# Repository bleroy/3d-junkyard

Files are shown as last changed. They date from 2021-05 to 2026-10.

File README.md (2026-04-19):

# 3d-junkyard

A repository of various 3D models and projects.

So far:

* [DecentXE](./DecentXE): a mechanical keyboard for Atari XE computers
* [DecentXL](./DecentXL/): a mechanical keyboard for Atari 600XL and 800XL computers
* [Decent400](./Decent400/): a mechanical keyboard for Atari 400 computers
* [Decent800](./Decent800/): a mechanical keyboard for Atari 800 computers
* [Decent1200](./Decent1200/): a mechanical keyboard for Atari 1200XL computers 
* [Dungeon Master](./DungeonMaster): reverse-engineering Dungeon Master's rendering and running it in a browser
* [Beyond the Jaggi lines](./Jaggilines): reverse-engineering Rescue on Fractalus and running it in a browser
* [JoyKeyMX](./JoyKeyMX): a joypad compatible with Atari 8-bit and 7800 built with Cherry MX compatible switches

## License

All hardware in this repository is licensed under [CERN Open Hardware License v2](https://ohwr.org/cern_ohl_p_v2.pdf).
All software in this repository is licensed under the [MIT license](https://mit-license.org/).
All documentation in this repository is licensed under [Creative Commons Creative Commons Attribution-ShareAlike 4.0 International Public License](https://creativecommons.org/licenses/by-sa/4.0/legalcode).

Full terms can be found in the [LICENSE](./LICENSE) file or on the web sites linked above.

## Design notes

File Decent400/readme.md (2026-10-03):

# Decent 400 mechanical keyboard replacement for Atari 400 computers

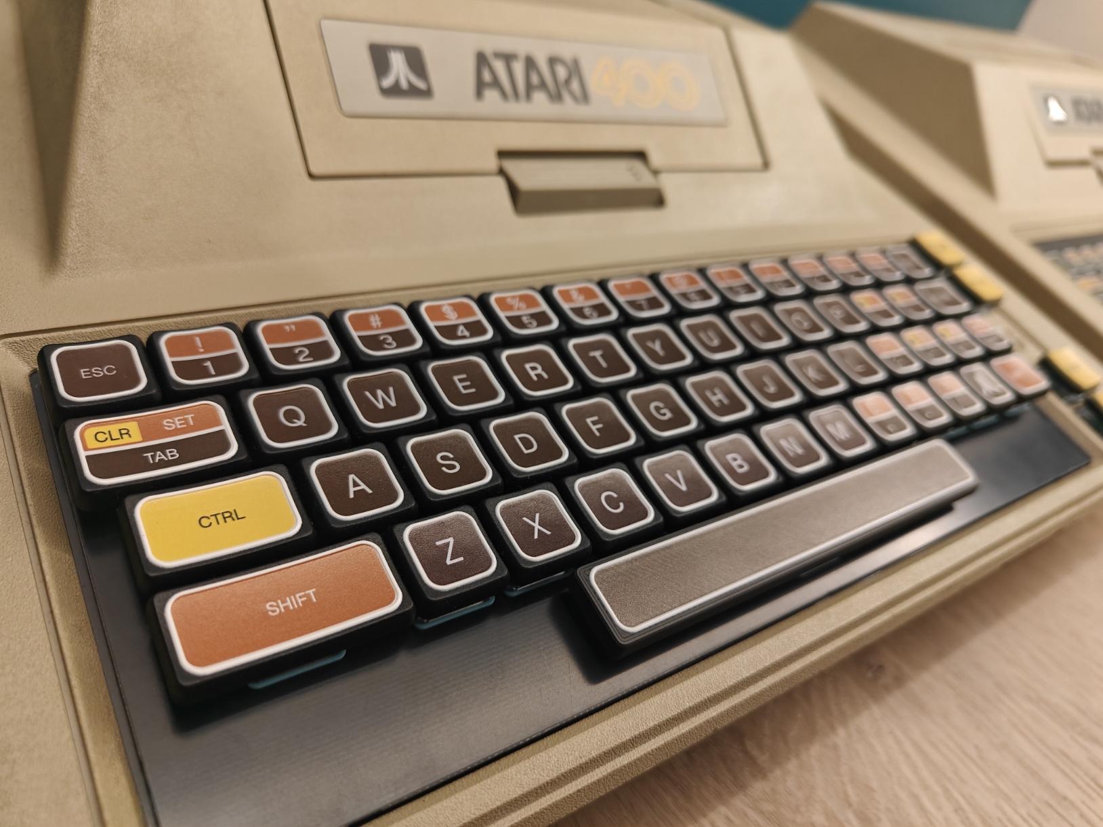
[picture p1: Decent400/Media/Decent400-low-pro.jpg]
The Decent 400 keyboard


If you always wished the Atari 400 had a real keyboard, this is the project for you.

There's been a number of aftermarket keyboards for the Atari 400, but they all faced a big issue: the original membrane "keyboard"'s "keys" are much smaller than standard key caps. There just isn't enough space in the case for a sane layout with full-sized keys. It took a lot of attempts before coming up with the realization that there was an untapped degree of freedom in the design: the spacing of the keys. This is even more true of low-profile key caps, and given how infinitely taller MX switches and caps are compared to the original membrane thing, it made sense to try to build the Decent400 as a low-profile mechanical keyboard. I was finally able in late 2025 to fit the original layout of the computer in its very small space, with modern switches.

There was one final obstacle though, which is that as I'm writing this readme, no company in the world will print custom low-profile key caps. My only option was to somehow find a way to do it myself. When I heard about the [Eufymake](https://www.eufymake.com/) kickstarter for a UV printer capable of transferring a full-color design onto any material, it was clear it could be the last piece to the puzzle. It was a big investment, but I bet on it and waited and waited and waited. Finally, the printer arrived and check this out:

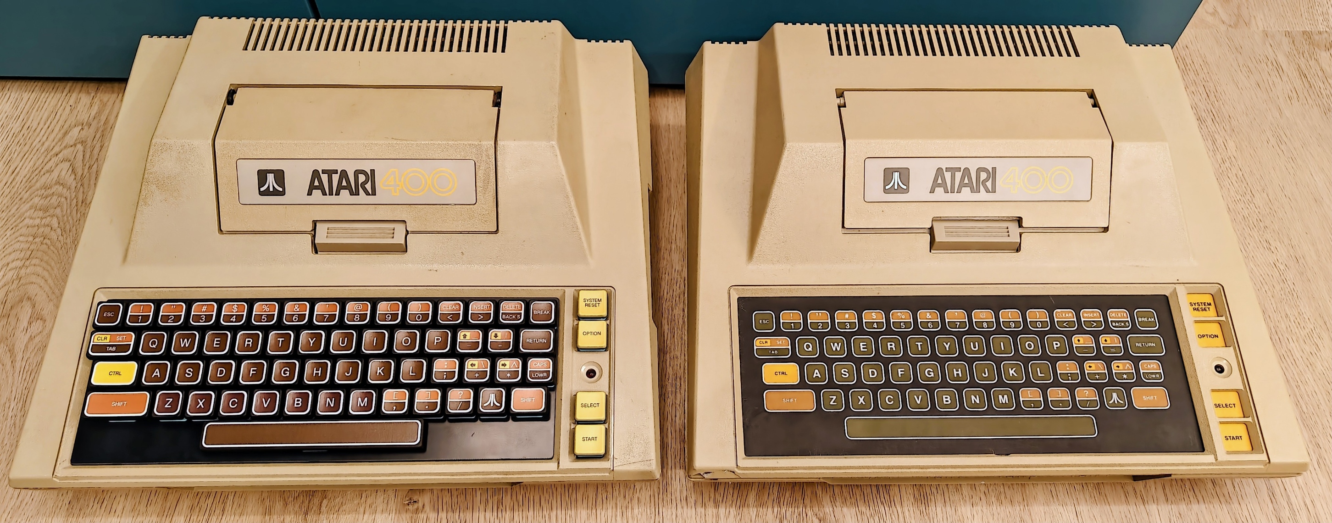
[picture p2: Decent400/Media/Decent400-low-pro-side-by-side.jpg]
Side-by-side comparison with the vintage membrane


It even has the raised white outline on each key, a very satisfying detail...

The keyboard can be built with your choice of Kailh Choc v1 switches. I prefer the clicky Robins myself, but perfectly good tactile and linear options do exist if that's your preference.

If you're looking to modify an XE computer, head over to [the DecentXE project](../Atari130MX/). For 600XL and 800XL keyboards, go to [the DecentXL project](../DecentXL/). For the 1200XL keyboard, go to [the Decent1200 project](../Decent1200/). For the 800, go to [the Decent800 project](../Decent800/).

## Current version

The current revision of the Decent 400 keyboard is: rev. 5.

## Can I buy one?

The project is open-source, and I encourage everyone to build their own (access to a UV printer can be an obstacle, but you can buy the printed key caps from me). I also sell kits and assembled keyboards for those who are not comfortable with ordering parts, PCBs or using a soldering iron.

How expensive is it? It depends on what you're ordering, but this is a made-to-order custom mechanical keyboard, so not cheap.

## Project history

This is a brand new design that uses a lot of lessons learned from building the [DecentXE](https://github.com/bleroy/3d-junkyard/tree/main/Atari130MX) and the [award-winning DecentXL](https://github.com/bleroy/3d-junkyard/tree/main/DecentXL), but adapts to the specificities of the 400.

## Options

### Switches

Switches are largely a matter of taste. The Decent 400 PCB can be mounted with any Kailh Choc v1 switch.

With any type of switch, there is a wide array of choices. If you're new to the world of mechanical keyboards, there are 3 main families of switch experiences:

* Linear (often red): the switch reacts with mostly constant resistance throughout the course of the key press until it hits the bottom.
* Tactile (often brown): there is a higher resistance at a specific point of the key's course, providing tactile feedback to pressing the key.
* Clicky (often white): an even more pronounced and localized resistance is accompanied with an audible and satisfying click.

My personal preference goes to Choc Robin switches, which are very pleasant clicky switches.

## Design

Decent 400 schematic

The Decent 400 project is constituted of the following parts (this is not a BOM but a list of custom parts created for this project; see below for the actual BOM):

* A PCB with adjustable blue backlighting.
* An aluminum or FR4 plate to hold the switches firmly aligned and rigidify the assembly.
* A custom set of Choc v1-compatible modern key caps.
* A connector adapter board
* Cables

## Bill of materials

This project is meant to be reproduced. You'll need a few things that are more or less easy to source, so I've made sure to give multiple roads to success and alternatives for most parts.

It's also an approach that can be easily adapted to other vintage computer keyboards, Atari or not.

### Atari 400 computer

The project is designed around the conservation of the vintage look of the Atari 400 computer and the integration of the keyboard in its original case. As such, you'll need a host 400 computer to receive the end product.

### Key caps

The key caps are the hardest part to source because at the time of writing, nobody's printing custom low-profile caps.

As UV printers are becoming relatively affordable, it has become possible to print blank caps at home.

You'll need a set of blank caps that can be printed in a UV printer.
I'm providing a set of templates and printing support to make it easier to get consistent results.

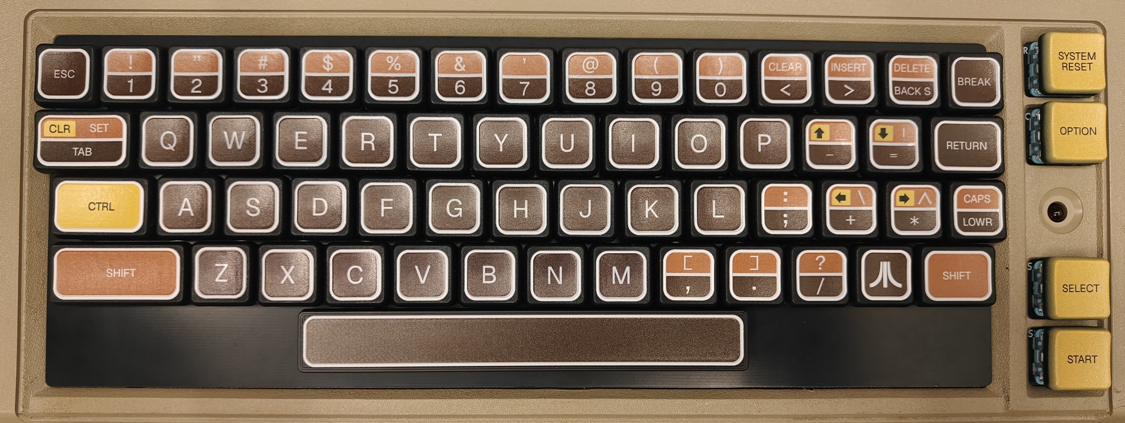
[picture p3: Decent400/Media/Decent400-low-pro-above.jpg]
Bird-eye view of the Decent400


The space bar key cap is almost impossible to source and must be [printed with black filament](./Caps/SpaceBar-Choc-v1-6U25.3mf).

### Switches

You'll need 63 Choc v1 switches.

### Stabilizers and adapters

The Decent 400 keyboard uses one 2U stabilizers for the left shift key, and one 6.25U stabilizer for the space bar.
Make sure you order the correct low-profile stabilizers.

### PCB

Use [the Gerber](./Keyboard/production/Decent400_keyboard_5.zip), [BOM](./Keyboard/production/bom.csv) and [position](./Keyboard/production/positions.csv) files to order a PCB with all the SMD parts assembled.

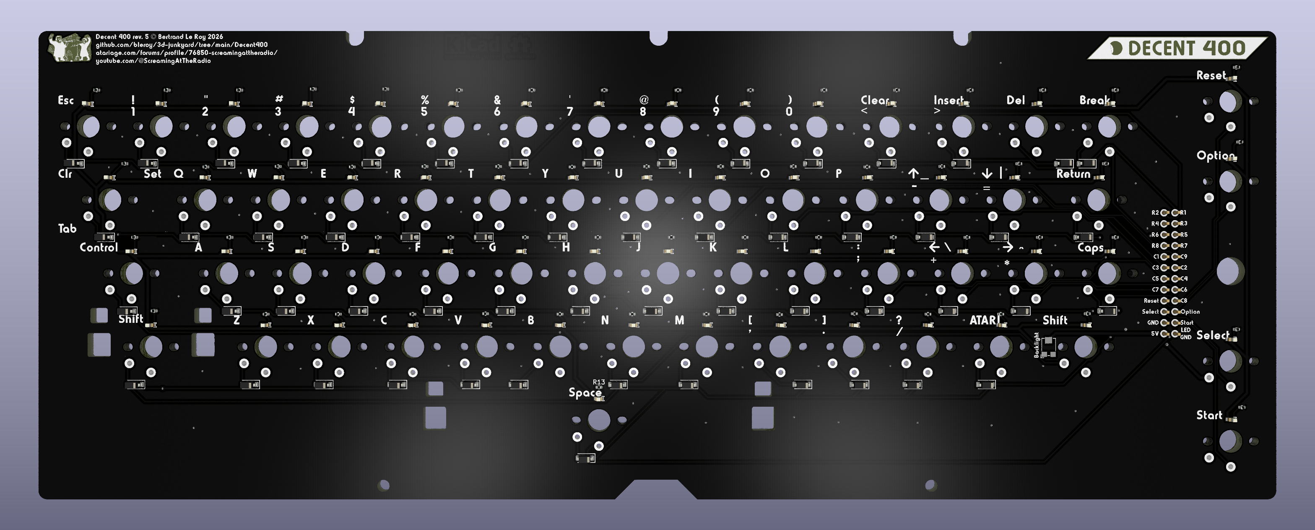
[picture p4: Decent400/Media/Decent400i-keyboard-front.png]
The Decent400 PCB


The main PCB needs a 2x12 pin male IDC connector.

### Plate

The plate is just a PCB, which can be done in aluminum or FR4. Download [the Gerber](./Plate/production/Decent400_Plate_4.2i.zip) and have it produced in 1.2mm. It is important to check the thickness is 1.2mm and not the default 1.6mm, so that the Choc switches can properly grip it. I recommend having this done in black.

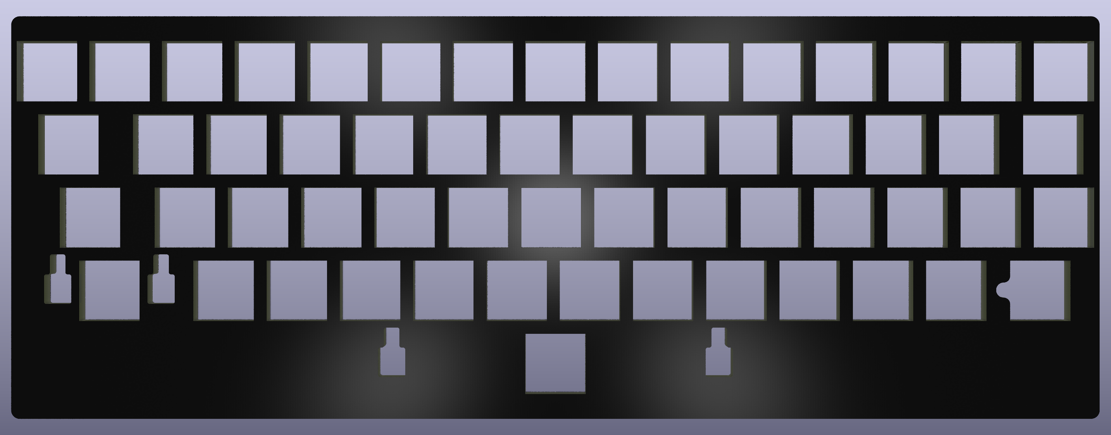
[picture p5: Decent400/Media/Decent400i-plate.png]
Decent 400 aluminum plate


### Connectors

The keyboard connects to the motherboard through a small interface board. A pin header goes into the motherboard connector, and an IDC connector goes to the keyboard. There's also a pair of headers that can be connected to 5V and ground on the 400's power board to provide backlighting.

The connector board needs another 2x12 pin male IDC connector a 22 precision male pin header a a 2 pin angled male header.

You'll need a 24 wire 1.27mm pitch flat cable. 10cm or 15cm is fine since the connector board will be very close to the keyboardś connector.

You'll also need a 22 pin 2.54mm precision male header and a 2 pin 2.54mm pitch angled male header. Finally, two Dupont wires will connect the backlighting to 5V and ground on the Atariś power board.

## Assembly

Once you've gathered all the parts, you can assemble them in the following order:

### Mount the switches onto the plate

Insert switches into the plate with the LED window to the back and the pins to the front.

### Mount the stabilizers

The stabilizers consist of two parts and a rod. They must first be assembled and then added to the plate from the underside.

Thereś plenty of tutorials that get into the details of installing those stabilizers. Here's one:

[Kailh Chox stabilizer installation](https://docs.keeb.io/choc-stabs)

### Get the plate and PCB together

After making sure all the switch pins are vertical and none are bent out of place, carefully align the plate and switches with the PCB. Slowly and carefully complete that assembly, making sure no pins get bent. Once that is done, the plate and PCB should be a few millimeters apart, evenly spaced across the whole surface.

You may secure the boards together with tape or clothespins until you've soldered enough switches.

### Solder the switches onto the PCBs

Solder each switch onto the PCBs.

Note the console key switches are not within the area covered by the plate and need to be soldered separately after being carefully aligned by hand.

### Assemble the connector board

Solder the 24 pin IDC connector to the top of the connector board, the 22 pin header to the bottom and the 2 pin power header to the top.

### Plug the cables

Solder the second 24-pin IDC connector to the bottom of the keyboard and connect both ends of the flat cable into the IDC connectors. 

### Add the key caps

Assemble the key caps onto the switches starting with the stabilized keys. Don't add the caps to the console keys as that will make it difficult to get the keyboard through the tight console key holes.

Your keyboard is now assembled. Let's mount it into the computer.

### Removing the old keyboard

Opening the Atari 400 can be tricky if you haven't done it before. There are some great tutorials and videos showing how to do that. You only need to remove the top of the case, no need to fully disassemble the computer.

Once the top of the case is free, carefully lift it and unplug the keyboard ribbon cable from the connector on the motherboard.

Carefully remove the membrane abomination from the top of the case, taking care not to break the two very small pegs that hold it on the bottom. Some bending will be necessary.

Get the new keyboard in place under the top of the case. Getting the console key switches through is usually the trickiest part. Also take care to get the PCB in place on the bottom.

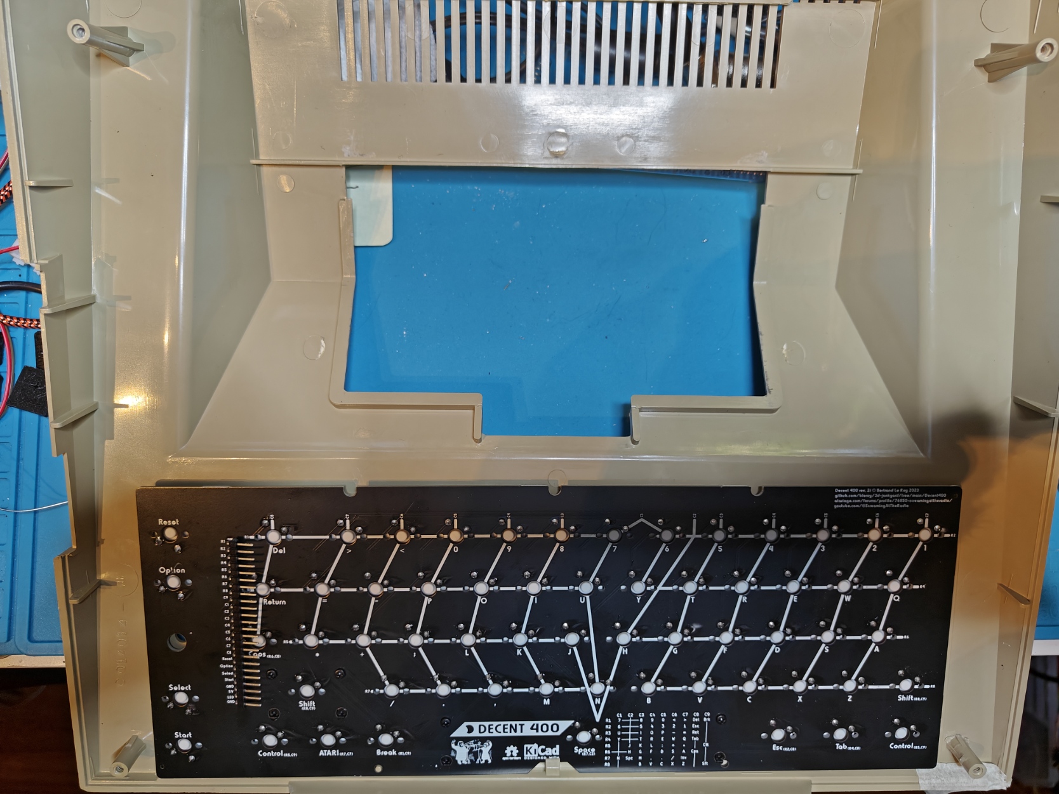
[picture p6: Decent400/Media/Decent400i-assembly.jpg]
Positioning the new keyboard in the case


The top will still be floating, but it will be held by the shielding when we reassemble the computer.

### Connect the LED power lines

The keyboard's backlighting needs to get power from the 400 board since the keyboard connector doesn't have a 5V line. Power and ground taps can be found on the power board.

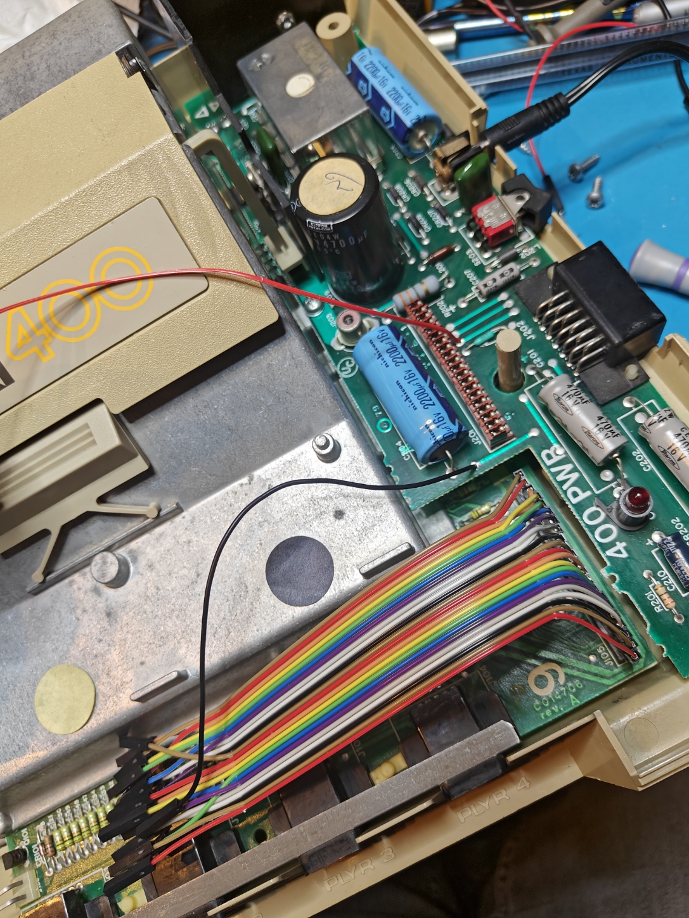
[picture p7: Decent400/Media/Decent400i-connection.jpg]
Connecting backlighting power lines


The black wire is ground and the red one is 5V.

### Connect the keyboard

Carefully insert the pin header on the bottom of the connector board into the motherboard's keyboard connector.

Connect the two power lines to the remaining two pins on the connector board.

### Close the case

Close the case, making sure to hold the keyboard while you're doing it and screw it shut. Now would be a good time to add those console key caps.

Congratulations, you're done! Turn your computer on and enjoy your mechanical keyboard. It's a good idea to go into BASIC and check every key works. There are also [keyboard testers](https://forums.atariage.com/index.php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) that will allow for a complete check.

## Troubleshooting

Defects and mistakes happen. If when testing your keyboard, you notice a key or a bunch of them don't work, testing and fixing the keyboard is usually quite easy.

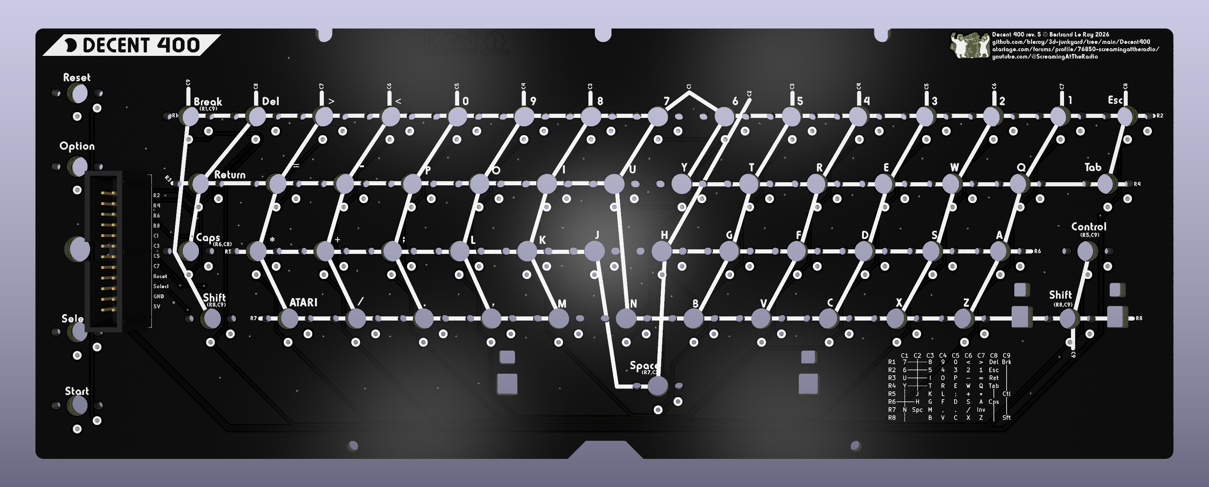
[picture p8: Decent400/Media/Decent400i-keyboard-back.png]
The back of the Decent400 PCB


The back of the board shows the matrix the keyboard is built on. It's easy, from the indications there to figure out what pins a switch is supposed to connect. It's like coordinates: the keyboard is essentially a matrix of switches with diodes behind them. You can test continuity using the connector pins and the diode testing mode of your multimeter. Connect your multimeter, press the switch. You can also test the switch directly, and test continuity from it to its neighbours and to the connectors. Most problems can be found this way, and if the keyboard needs repairs, it's usually easy to pull an additional wire to fix a damaged trace.

## Acknowledgements

I want to thank [XLFreak](https://forums.atariage.com/profile/63723-xl-freak/) for designing early versions of the modern key cap set for this project.

And of course, many thanks to all those who provided feedback on the [DecentXE keyboard](https://github.com/bleroy/3d-junkyard/tree/main/Atari130MX) over its many revisions or bought a keyboard.

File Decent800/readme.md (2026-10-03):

# Decent 800 mechanical keyboard replacement for Atari 800 computers

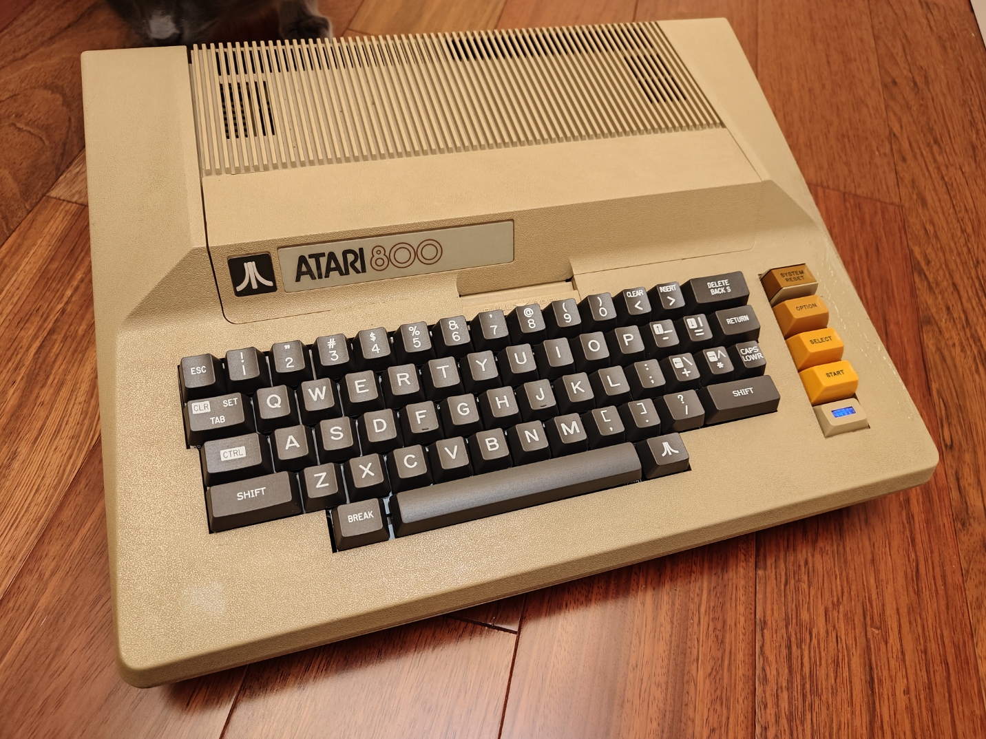
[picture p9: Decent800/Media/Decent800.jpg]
The Decent800 keyboard


If you have an Atari 800 with a faulty keyboard or just want to upgrade, this is the project for you.

If you're looking to modify an XE computer, head over to [the DecentXE project](../Atari130MX/). For 600XL and 800XL keyboards, go to [the DecentXL project](../DecentXL/). For the 1200XL keyboard, go to [the Decent1200 project](../Decent1200/).

## Current version

The current revision of the Decent 800 keyboard is: rev. 3M. There's an older revision that can take low-profile switches and printed adapters for vintage key caps that I'm not covering in this readme.

## Can I buy one?

The project is open-source, and I encourage everyone to build their own. I also sell kits and assembled keyboards for those who are not comfortable with ordering parts, PCBs or using a soldering iron.

How expensive is it? It depends on what you're ordering, but this is a made-to-order custom mechanical keyboard, so not cheap.

## Project history

This is a brand new design that uses a lot of lessons learned from building the [DecentXE](https://github.com/bleroy/3d-junkyard/tree/main/DecentXE) and the [award-winning DecentXL](https://github.com/bleroy/3d-junkyard/tree/main/DecentXL), but adapts to the specificities of the 800.

## Options

### Switches

Switches are largely a matter of taste. The Decent 800 PCB can be mounted with any MX-compatible switch.

With any type of switch, there is a wide array of choices. If you're new to the world of mechanical keyboards, there are 3 main families of switch experiences:

* Linear (often red): the switch reacts with mostly constant resistance throughout the course of the key press until it hits the bottom.
* Tactile (often brown): there is a higher resistance at a specific point of the key's course, providing tactile feedback to pressing the key.
* Clicky (often white): an even more pronounced and localized resistance is accompanied with an audible and satisfying click.

## Design

Decent 800 schematic

The Decent 800 project is made of the following parts (this is not a BOM but a list of custom parts created for this project; see below for the actual BOM):

* A PCB with adjustable blue backlighting.
* An aluminum or FR4 plate to hold the switches firmly aligned and rigidify the assembly.
* A custom set of MX-compatible modern key caps.
* Two 3D-printed brackets.
* Cables.

## Bill of materials

This project is meant to be reproduced. You'll need a few things that are more or less easy to source, so I've made sure to give multiple roads to success and alternatives for most parts.

It's also an approach that can be easily adapted to other vintage computer keyboards, Atari or not.

### Atari 800 computer

The project is designed around the conservation of the vintage look of the Atari 800 computer and the integration of the keyboard in its original case. As such, you'll need a host 800 computer to receive the end product.

### Key caps

You'll need a set of caps that you can order from me or from ThockFactory.

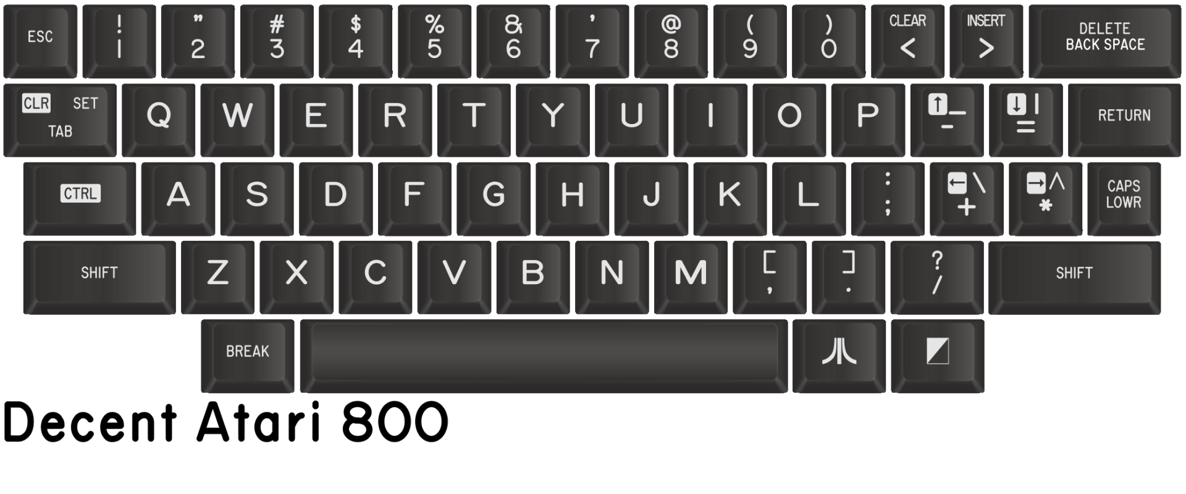
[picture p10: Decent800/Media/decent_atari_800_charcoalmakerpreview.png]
The Decent 800 modern layout


### Switches

You'll need 57 MX compatible switches.

### Stabilizers and adapters

The Decent 800 keyboard uses three 2U Durock v2 stabilizers for the shift and backspace keys, and one 6.25U Durock v2 stabilizer for the space bar.

### PCB

Use [the Gerber](./Keyboard/production/Decent800_keyboard_3M.zip), [BOM](./Keyboard/production/Decent800_Rev_3M-bom.csv) and [position](./Keyboard/production/Decent800_Rev_3M-positions.csv) files to order a PCB with all the SMD parts assembled.

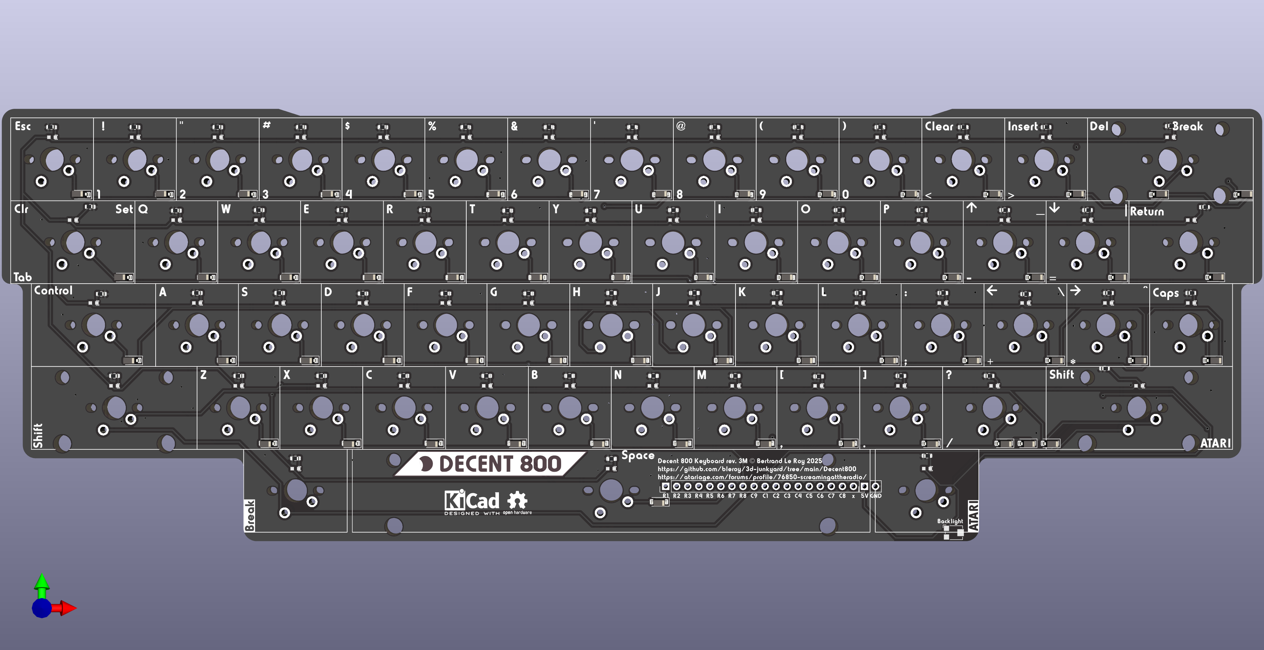
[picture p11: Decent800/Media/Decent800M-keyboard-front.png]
The Decent800 PCB


### Plate

The plate is just an aluminum or FR4 PCB. Download [the Gerber](./Plate/production/Decent800_Rev3M.zip) and have it produced in 1.6mm aluminum or FR4. I recommend having this done in black even if it's more expensive because the default white is very visible between the caps.

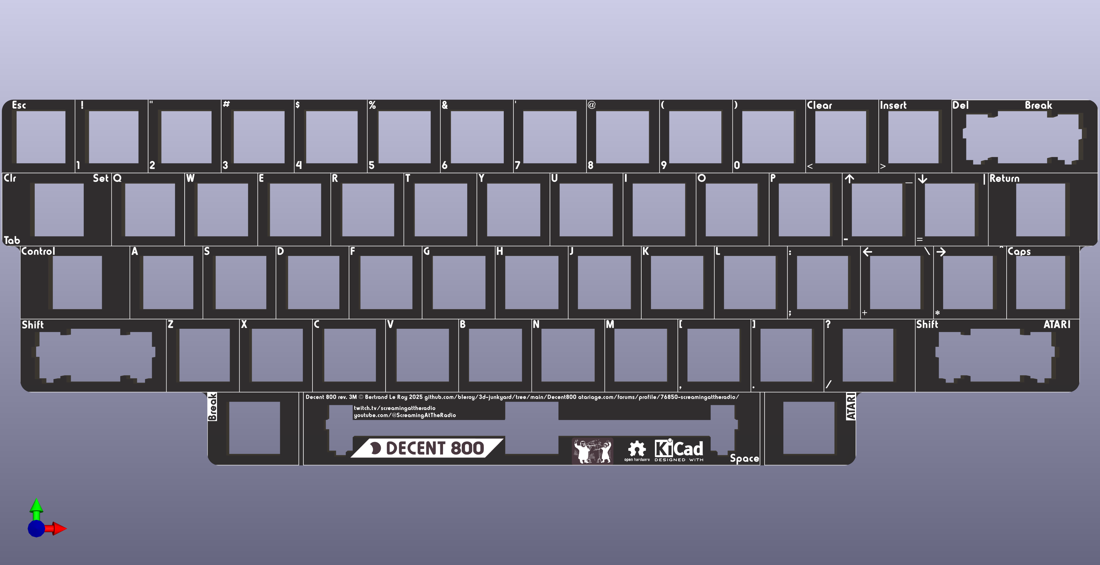
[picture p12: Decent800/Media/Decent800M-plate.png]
Decent 800 aluminum plate


### Connectors

The connector to the motherboard is a pair of cables with female Dupont connectors on both ends. LED power comes through a pair of wires that get soldered onto the power board on one end, and should have female Dupont connectors on the other side. We need 18 pins spaced 2.54mm (0.1") on a single line for the main keyboard signals and two for LED power. The cables should be at least 10cm long, but 15cm or 20cm will be more comfortable.

You'll also need a 20 pin 2.54mm angled header.

## Assembly

Once you've gathered all the parts, you can assemble them in the following order:

### Solder the connector

The 20-pin angled header needs to be soldered before assembling the switches because the solder points will be between the PCB and the plate. That may make some switch solder points a little more difficult as they will be partially under the pins. Make sure to not let the connector pins through the board too much. Your solder points should be almost flush with the PCB because one of the stabilizers for the space bar will need to be assembled over that. Note that the screw for that stabilizers is a little tricky to set right.

Solder the 20-pin angled header under the PCB (solder on the top of the PCB, header under). Make sure to leave enough space between the PCB and the pins.

### Mount the stabilizers

The stabilizers consist of a larger part that has the threaded part, a smaller part that slides into the previous one, a metal bar linking two assemblies of the two previous parts, and some hardware. The stabilizers are best assembled in this order: slide the smaller part into the larger one (make sure you orient it properly), then insert one end of the metal rod into that assembly and push it into place so it clicks and is properly secured. Once you've done that with both ends of the stabilizer, you should be able to verify both ends lift together and with no friction (some people like to lube their stabilizers by the way).

Once the stabilizers are assembled, you can put them in their respective places on the top side of the PCB. Insert the bottom, non-threaded part first, try to lay the stabilizer's surface flat on the PCB, and push the top threaded part into place. This usually moves the other end a bit, so make sure both ends are properly inserted all the way into the holes in the PCB.

Turn the PCB over. Position one of the small washers around each of the screw holes for the stabilizers and secure it with a screw.

### Mount the switches onto the plate

Insert switches into the aluminum plate with the LED window to the back and the pins to the front.

### Get the plate and PCB together

After making sure all the switch pins are vertical and none are bent out of place, carefully align the plate and switches with the stabilizers and the PCB. Slowly and carefully complete that assembly, making sure no pins get bent. Once that is done, the plate and PCB should be a few millimeters apart, evenly spaced across the whole surface.

You can secure the boards together with tape or clothespins until you've soldered enough switches.

### Solder the switches onto the PCBs

Solder each switch onto the PCBs.

### Plug the cables

Plug one end of your cables onto those headers.

### Add the key caps

Assemble the key caps onto the switches starting with the stabilized keys.

Your keyboard is now assembled. Let's mount it into the computer.

### Removing the old keyboard

Opening the Atari 800 can be tricky if you haven't done it before. There are some great tutorials and videos showing how to do that. You only need to remove the top of the case, no need to fully disassemble the computer.

Once the top of the case is free, carefully lift it and unplug the keyboard cable from the connector on the motherboard.

Carefully unscrew the old keyboard from the top of the case. Leave the "pull open" part in place (unlike what's on the photo below, that was a mistake).

Add the two brackets around the PCB and plate, then carefully add the resulting assembly over the four columns around the keyboard opening.
Secure with the four original screws.

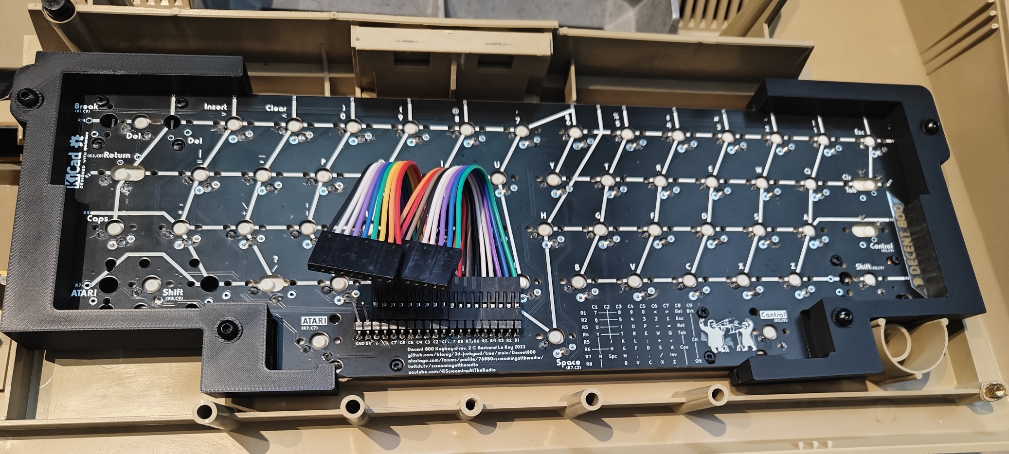
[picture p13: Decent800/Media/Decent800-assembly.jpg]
Positioning the new keyboard in the case


### Connect the LED power lines

The keyboard's backlighting needs to get power from the 800 board since the keyboard connector doesn't have a 5V line. Power and ground tap vias can be found on the power board. Use wires with Dupont female connectors on one end, and nothing on the other end. I just cut and tin jumper cables for those.

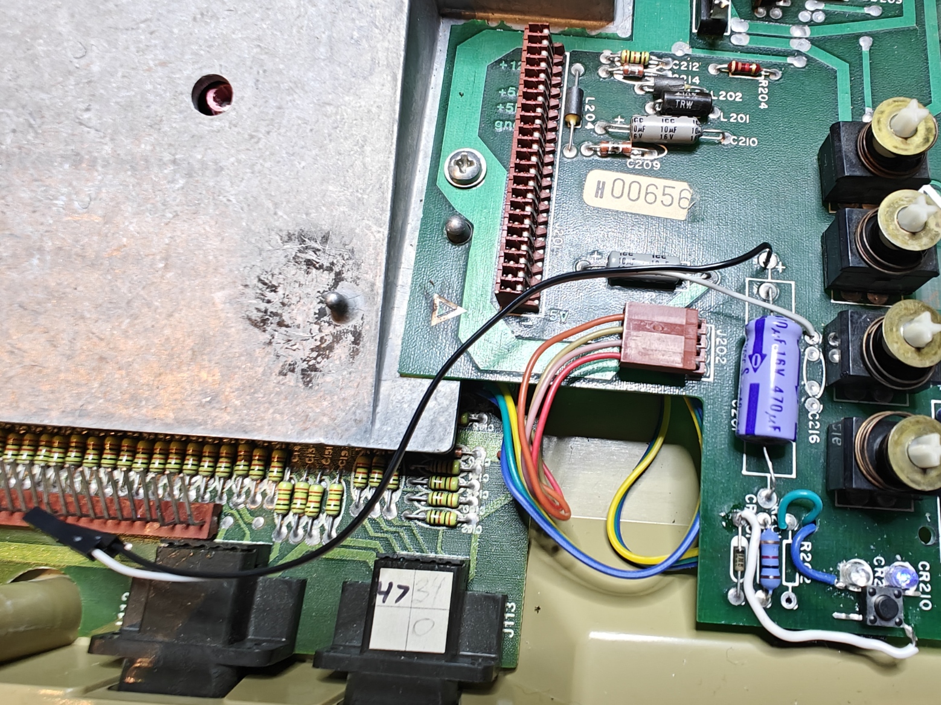
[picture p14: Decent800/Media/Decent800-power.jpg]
Connecting backlighting power lines


The black wire is ground and the white one is 5V.

### Connect the keyboard

Carefully insert the connectors into the motherboard's keyboard connector.

Connect the two power lines to the remaining two pins on the keyboard's connector. LED ground is the bottom pin, and 5V goes right above that.

### Close the case

Close the case (follow whatever tutorial you followed for disassembling the computer in reverse).

Congratulations, you're done! Turn your computer on and enjoy your mechanical keyboard. It's a good idea to go into BASIC and check every key works. There are also [keyboard testers](https://forums.atariage.com/index.php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) that will allow for a complete check.

## Troubleshooting

Defects and mistakes happen. If when testing your keyboard, you notice a key or a bunch of them don't work, testing and fixing the keyboard is usually quite easy.

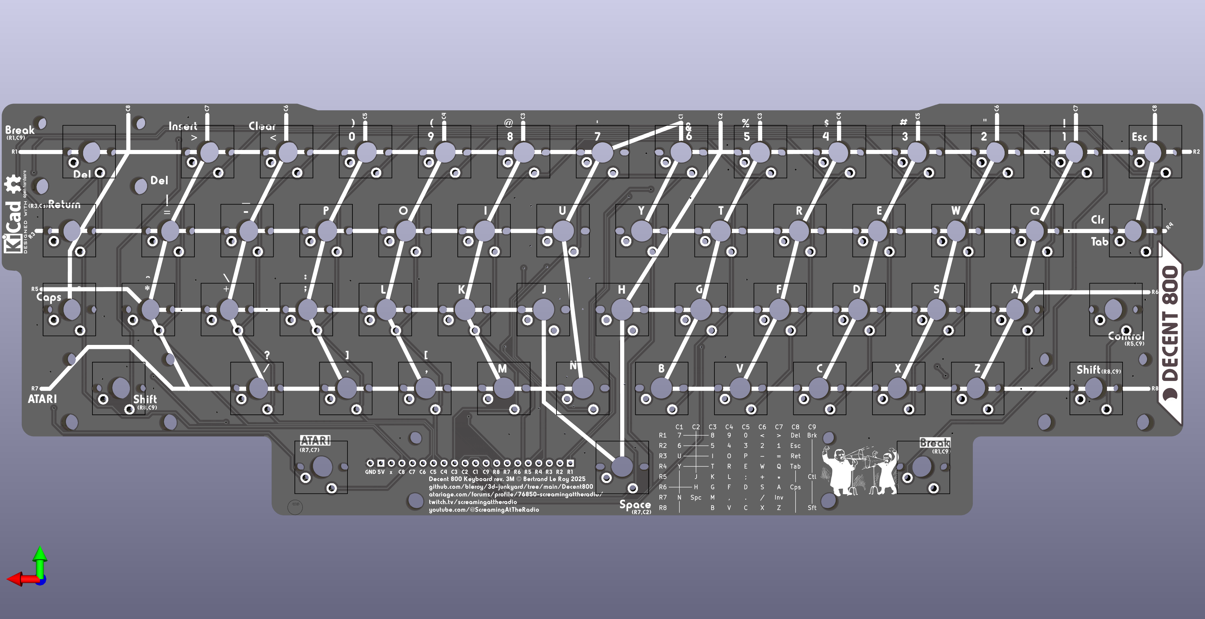
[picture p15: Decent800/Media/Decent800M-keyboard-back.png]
The back of the Decent800 PCB


The back of the board shows the matrix the keyboard is built on. It's easy, from the indications there to figure out what pins a switch is supposed to connect. It's like coordinates: the keyboard is essentially a matrix of switches with diodes behind them. You can test continuity using the connector pins and the diode testing mode of your multimeter. Connect your multimeter, press the switch. You can also test the switch directly, and test continuity from it to its neighbours and to the connectors. Most problems can be found this way, and if the keyboard needs repairs, it's usually easy to pull an additional wire to fix a damaged trace.

## Acknowledgements

I want to thank [XLFreak](https://forums.atariage.com/profile/63723-xl-freak/) for designing the modern key cap set for this project.

And of course, many thanks to all those who provided feedback on the [DecentXE keyboard](https://github.com/bleroy/3d-junkyard/tree/main/Atari130MX) over its many revisions or bought a keyboard.

## What about vintage?

The current PCB supports only modern switches and caps. The older version 2.1 supports vintage versions of the keyboard through the use of Kailh Choc v1 switches and printed adapters that bridge the gap between the footprint of the Kailh switches and the Atari key caps. The adapters can be printed from models that are in [the SCAD file for all adapters](../Atari130MX/Stems/keeb-stem.scad). Wide keys are offset, which necessitates weird positioning of the switch footprints on the PCB.

There's a reason why I stopped producing vintage keyboards: they are of much lower quality than the modern ones, so if you want to go that route, you're on your own, sorry...

The types of keyboards I've seen so far for the 800 are:

* [Mitsumi KSD](https://deskthority.net/wiki/Mitsumi_KSD_Type): 1.6mm cross pattern
* [Hi-Tek High Profile](https://deskthority.net/wiki/Hi-Tek_High_Profile): square pattern, flat-top variant

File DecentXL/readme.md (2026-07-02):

# Decent XL mechanical keyboard replacement for Atari 600XL and 800XL computers

The DecentXL keyboard with charcoal modern key caps mounted in a 800XL

Whether you have a vintage Atari 800XL or 600XL computer with a deficient keyboard or just want a better keyboard, this is the project for you.

There are two versions of the keyboard: modern and vintage. Modern uses brand new MX-compatible key caps and switches, while vintage keeps the original vintage Atari caps and adapts them to modern switches.

The vintage version can use Kailh Choc v2 low-profile switches, in which case 3D-printed adapters bridge one of the supported variants of XL key caps to the Choc switches' MX footprint.

There's been a number of mechanical keyboard builds for Atari computers that are all great but tend to be one-off projects that are not designed to be reproduced or commercially produced. This project does all that and more.

If you're looking to modify an XE computer, head over to [the DecentXE project](https://github.com/bleroy/3d-junkyard/tree/main/Atari130MX).

## Current version

The current revision of the DecentXL keyboard is: rev. 4 (4v designates the vintage version, and 4m the modern version).

## Can I buy one?

The project is open-source, and I encourage everyone to build their own. I also sell kits and assembled keyboards (both modern and vintage) for those who are not comfortable with ordering parts, PCBs or using a soldering iron.

How expensive is it? It depends on what you're ordering, but this is a made-to-order custom mechanical keyboard, so not cheap.

## Project history

This is a brand new design that uses a lot of lessons learned from building the [DecentXE keyboards](https://github.com/bleroy/3d-junkyard/tree/main/Atari130MX), but adapts to the many complicated subtleties of the XL line of computers.

The DecentXL keyboard won first prize at the [2023 ABBUC hardware contest](https://abbuc.de/forum/viewtopic.php?f=3&t=1658).

## Options

### Key caps: modern or vintage?

The modern versions of Decent keyboards are the best quality keyboards. It's a solid design that feels great. In comparison, the vintage versions tend to feel more wobbly and are generally of lower quality. They are also more difficult to build, which is why I stopped producing them myself. I want to keep the quality of the assembled keyboards I build as high as possible.

The modern version also has a slightly modified layout with large delete and return keys, and relocated break and control keys around the shorter space bar. Caps is relocated to where it is on a modern keyboard, above left shift (that's where Atari originally placed the control key, now left of space).

If you absolutely want to keep the look and layout of your keyboard as close to the original as possible, you can use vintage caps (scavenged from the computer you're modifying or bought new old stock or used), but be aware of the quality difference. The result is visually indistinguishable from the original, if it wasn't for the backlighting, and does feel much better than the original, but is significantly less nice than the modern version... You'll also have to build it yourself since I no longer ship assembled vintage versions. See building instructions below to get a feel of the build difficulty.

### Switches

Switches are largely a matter of taste. The DecentXL modern PCB can be mounted with MX-compatible switches. The vintage PCB can be mounted with Kailh Choc v1 switches.

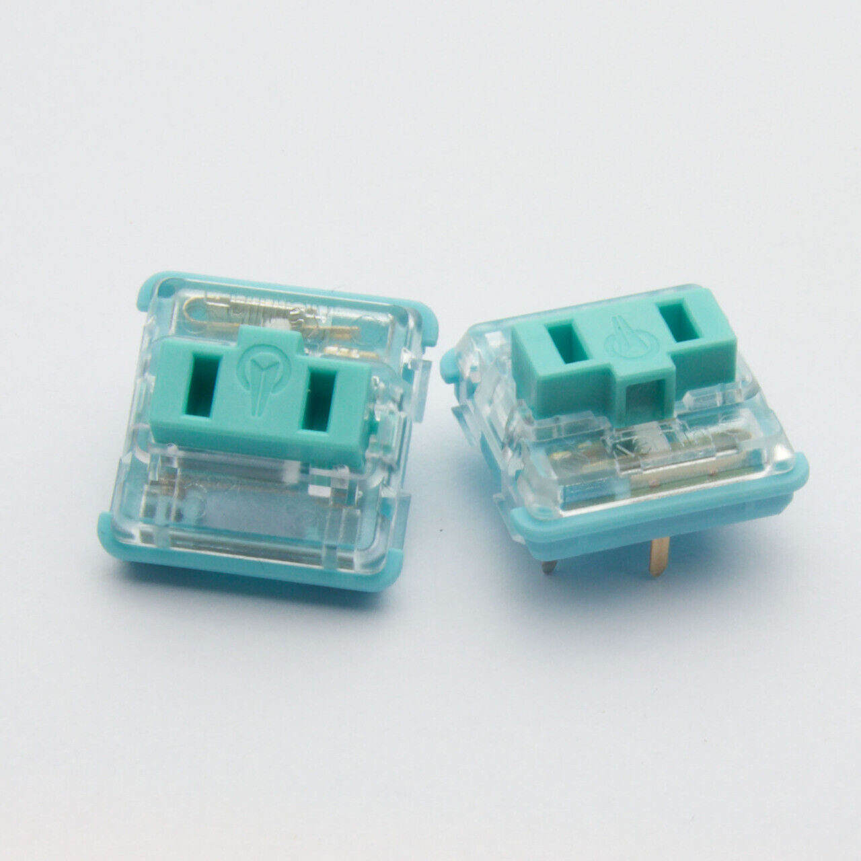
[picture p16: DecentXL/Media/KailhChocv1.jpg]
Kailh Choc v1 switches


It's your choice of caps that determines what type of switch to use:

* Modern: choose MX-compatible switches
* Vintage: choose Kailh Choc v1

With any type of switch, there is a wide array of choices. If you're new to the world of mechanical keyboards, there are 3 main families of switch experiences:

* Linear (often red): the switch reacts with mostly constant resistance throughout the course of the key press until it hits the bottom.
* Tactile (often brown): there is a higher resistance at a specific point of the key's course, providing tactile feedback to pressing the key.
* Clicky (often white): an even more pronounced and localized resistance is accompanied with an audible and satisfying click.

## Design

DecentXL schematic

The DecentXL project is constituted of the following parts (this is not a BOM but a list of custom parts created for this project; see below for the actual BOM):

* A PCB with surface-mounted anti-ghosting diodes, adjustable blue backlighting and flexible cable connection (revisions before rev. 4 have two PCBs, as the console keys are separate).
* An aluminum plate to hold the switches firmly aligned and rigidify the assembly.
* A custom set of MX-compatible modern key caps.
* 3D-printed adapters for vintage caps.
* 3D-printed console keys with vinyl texture stickers.
* A flexible PCB to connect the main board to the Atari motherboard.
* 3D-printed brackets to connect the boards to the XL top case shell (when rails are not available or using a revision lower than 3).
* A 3D-printed LED diffuser.

## Bill of materials

This project is meant to be reproduced. You'll need a few things that are more or less easy to source, so I've made sure to give multiple roads to success and alternatives for most parts.

It's also an approach that can be easily adapted to other vintage computer keyboards, Atari or not.

### Atari 600XL or 800XL computer

The project is designed around the conservation of the vintage look of the Atari XL computers and the integration of the keyboard in its original case. As such, ideally you'd have a host XL computer to receive the end product.

### Key caps and adapters

You'll need a set of caps.

If you've decided to go for modern, you'll need a set of modern caps that you can order from me or from [GoblinTech](https://goblintechkeys.com/collections/60-keycap). Make sure to specify a 2.25U left shift.

The DecentXL modern layout

The key cap set is defined by [this SVG file](./Caps/Atari%20XL.svg).

If you have a complete set of vintage key caps, identify the type of cap by looking underneath one of your caps. Currently supported shapes are:

* Alps:
  
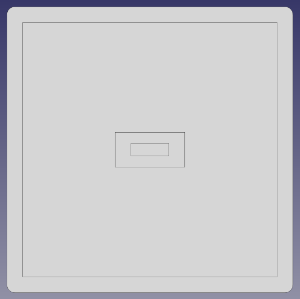
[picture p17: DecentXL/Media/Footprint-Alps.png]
Alps footprint
  

  You'll need 62 [Alps adapters](./Adapters/kailh-choc-to-xl-alps-x10.stl) (more affordable if printed as 7x sets of 10).

* Cross (AWC):

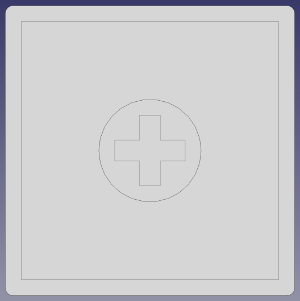
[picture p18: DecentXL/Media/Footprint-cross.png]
Cross footprint
  

  You'll need 63 [cross adapters](./Adapters/kailh-choc-to-xl-cross-x10.stl) (more affordable if printed as 7x sets of 10).

* Square (Stackpole):

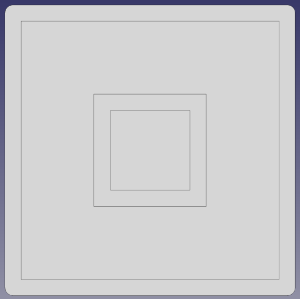
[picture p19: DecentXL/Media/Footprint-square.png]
Square footprint
  

  You'll need 62 [square adapters](./Adapters/kailh-choc-to-xl-square-stackpole-x10.stl) (more affordable if printed as 7x sets of 10).

If your key caps look nothing like those above (there are many different XL key footprints), please contact me. If you're OK sending me a key, I can measure it and make a new adapter for it, after which I'll send your key back.

[JLCPCB](https://jlcpcb.com/) and [PCBWay](https://www.pcbway.com/) are examples of fabrication houses that can produce high-quality prints of adapters for cheap, but there's plenty of other places where these can be done. You can also print your own (with a resin printer).

### Console keys (Help, Start, Select, Option and Reset)

You'll need new [3D-printed console keys](./Caps/ConsoleXL-Choc-Single.stl) (more affordable if printed as a [set of five](./Caps/Console-set-XL-Choc-x5.stl) or [ten](./Caps/Console-set-XL-Choc-x10.stl)). The printed console keys fit on top of Kailh Choc v1 switches, not the MX switches used for the rest of the keyboard.

3D-printed console keys will look great if you apply a [brushed metal vinyl sticker](https://www.amazon.com/dp/B08L4GZRDY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).

If using a revision before 4, you can re-use your existing vintage console keys for a vintage keyboard. Just use the same adapters as for other keys.

### Switches

For a modern layout, you'll need 62 switches total corresponding to your cap type. You need 57 switches for the main keyboard, and 5 for the console keys. That means that you'll need 57 MX switches and 5 Kailh Choc v1 switches.

Vintage uses all Kailh Choc switches for both main keyboard and console keys (62). Some vintage variants require additional switches that are used as stabilizers. For instance, Alps has two switches for the space bar. Both cross and Alps use two switches on the sides for the left shift, and remove the central switch. That means Alps needs two additional switches, bringing the total to 64, and cross (AWC) one additional switches for a total of 63.

### Stabilizers and adapters

#### Left shift

All keyboards except Alps and cross (AWC) need one 2U Durock v2 stabilizer for the left shift.

For modern keyboards, the stabilizer can be used as-is.

For Alps, you'll need special adapters specifically for left shift (not yet available).

For cross (AWC), you can use the same adapters as for other keys.

For square (Stackpole), you'll need in-key adapters (not yet available).

#### Space bar

Modern keyboards use a 6.25U space bar and as such can use a standard 6.25U Durock v2 stabilizer.

Vintage keyboards use a 9U spacebar for which no off-the-shelf modern stabilizer exist.

Alps keyboards have a second stabilizing switch to the right of the center one. This may be enough to stabilize the space bar, but it should also be possible to add a Durock stabilizer with a hand-made custom-length stabilizer rod made from [1/16" copper rods](https://www.mcmaster.com/8859K511/) and custom printed stems (not yet available).

Cross (AWC) keyboards require a Durock stabilizer with a hand-made custom-length stabilizer rod made from [1/16" copper rods](https://www.mcmaster.com/8859K511/) and custom printed stems (not yet available).

#### Delete and return

I recommend also stabilizing the delete and return keys with 2U stabilizers for the modern layout.

Contact me if you have an as yet unsupported shape of vintage cap. If you're OK sending me your space and left shift for measurements, I can design new adapters and send you back your caps.

### PCB

For the modern version, use [the Gerber](./DecentXL-keyboard/production/DecentXL_keyboard_-_Modern_4.2m-bom.csv), [BOM](./DecentXL-keyboard/production/DecentXL_keyboard_-_Modern_4.2m-bom.csv) and [position](./DecentXL-keyboard/production/DecentXL_keyboard_-_Modern_4.2m-positions.csv) files to order a PCB with all the SMD parts assembled.

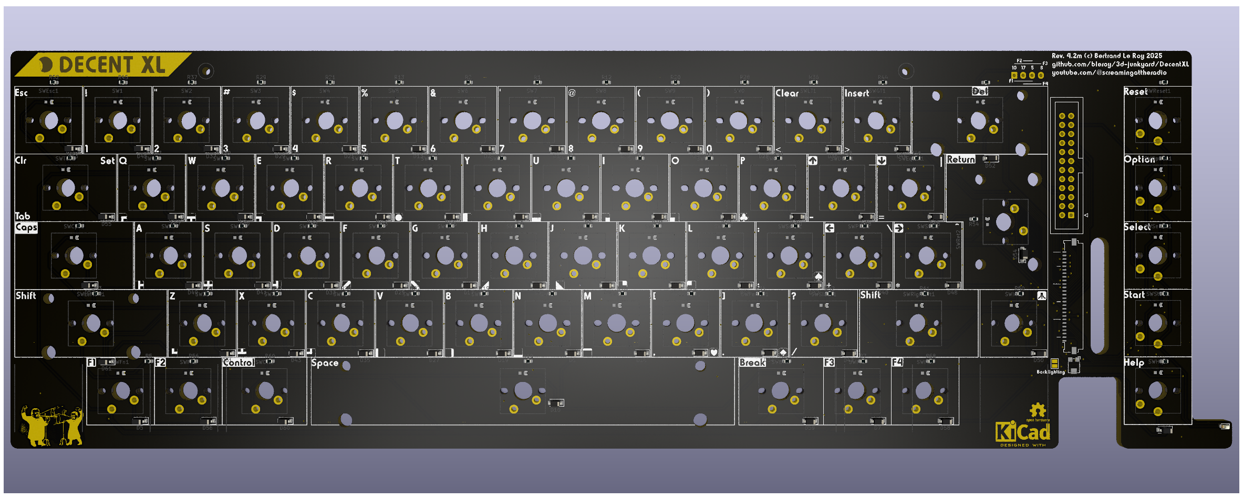
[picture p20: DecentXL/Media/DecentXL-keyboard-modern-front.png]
The DecentXL Modern PCB


For vintage versions, use [the Gerber](./DecentXL-keyboard/production/DecentXL_keyboard_4v.zip), [BOM](./DecentXL-keyboard/production/DecentXL_keyboard_4v-bom.csv) and [position](./DecentXL-keyboard/production/DecentXL_keyboard_4v-positions.csv) files to order a PCB with all the SMD parts assembled.

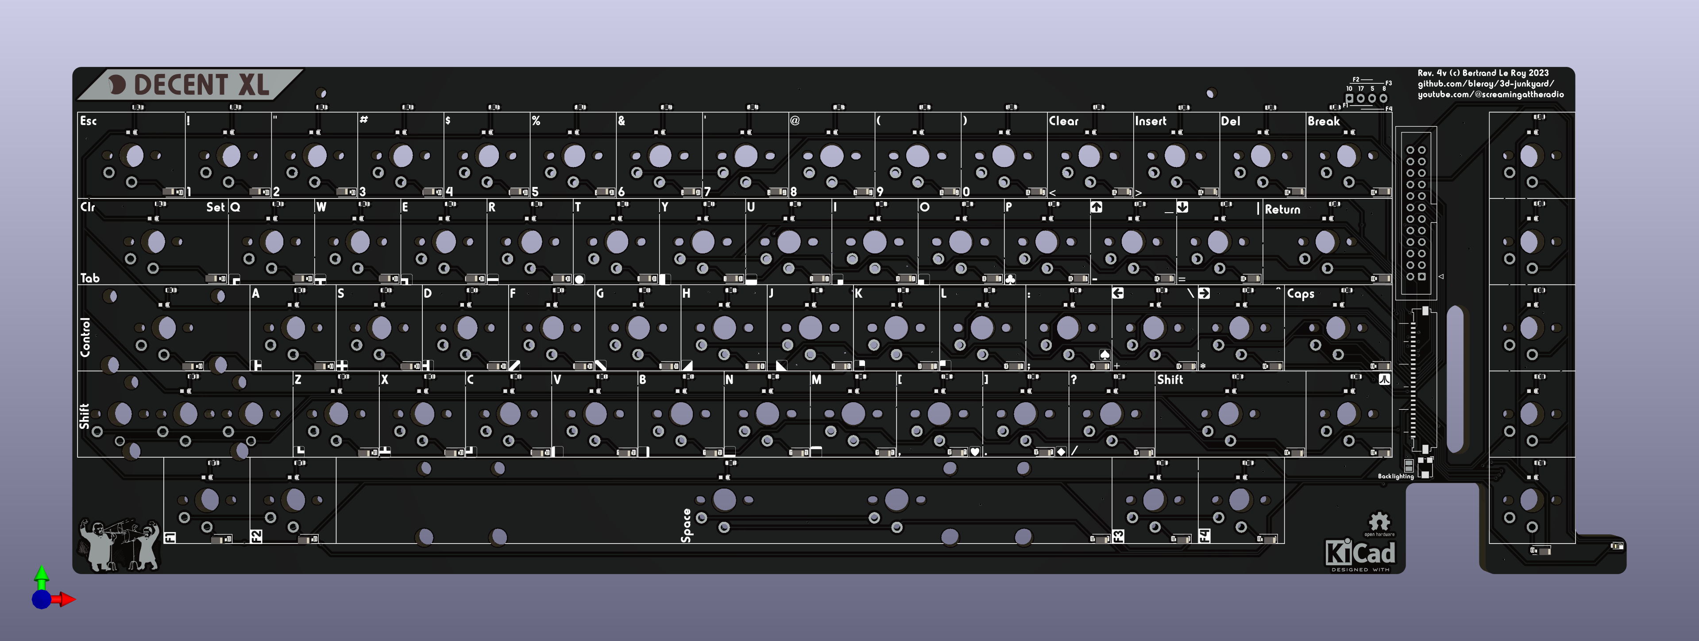
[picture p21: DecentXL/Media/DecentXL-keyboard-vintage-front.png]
The DecentXL Modern PCB


### Plate

The plate is just an aluminum PCB. Download [the Gerber for the modern](./DecentXL-plate/production/DecentXL_modern_plate_4m.zip) or [vintage](./DecentXL-plate/production/DecentXL_vintage_plate_4v.zip) and have it produced. I recommend having this done in black as it will be visible through the gaps between keys and on the sides.

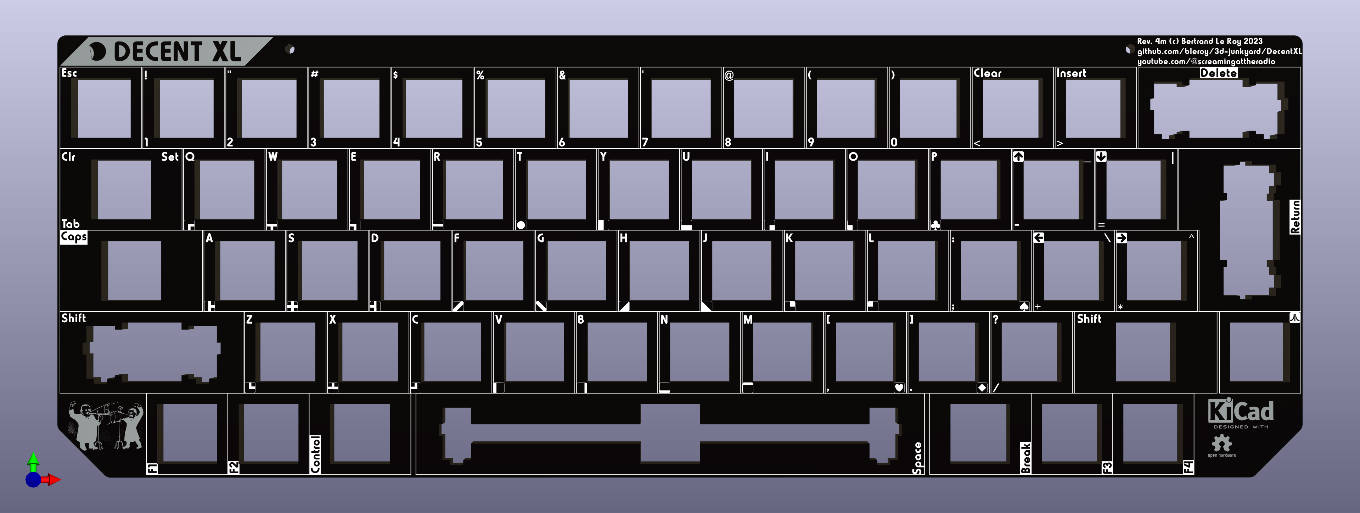
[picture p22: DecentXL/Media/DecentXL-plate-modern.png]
DecentXL modern aluminum plate


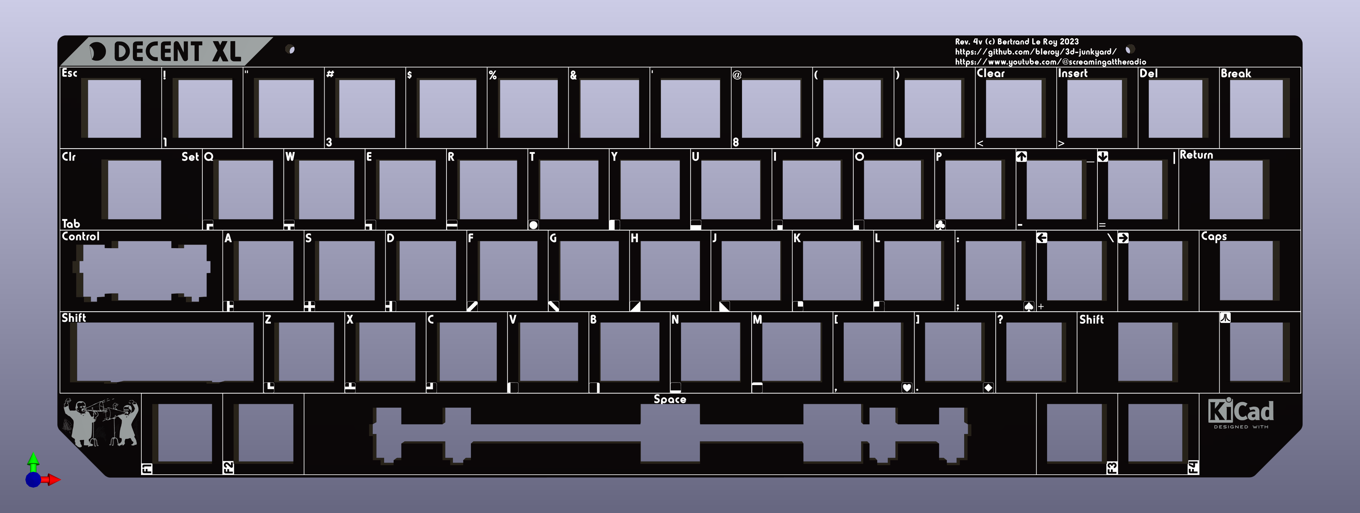
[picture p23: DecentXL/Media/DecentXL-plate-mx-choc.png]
DecentXL vintage aluminum plate


### Connectors

The connector to the motherboard is [a flexible PCB](./DecentXL-Cable/production/DecentXL_Flexible_Cable_2.zip). The fabrication house will usually ask you to specify what zones to apply rigidifiers to. There are two rectangles on the silkscreen that specify that.

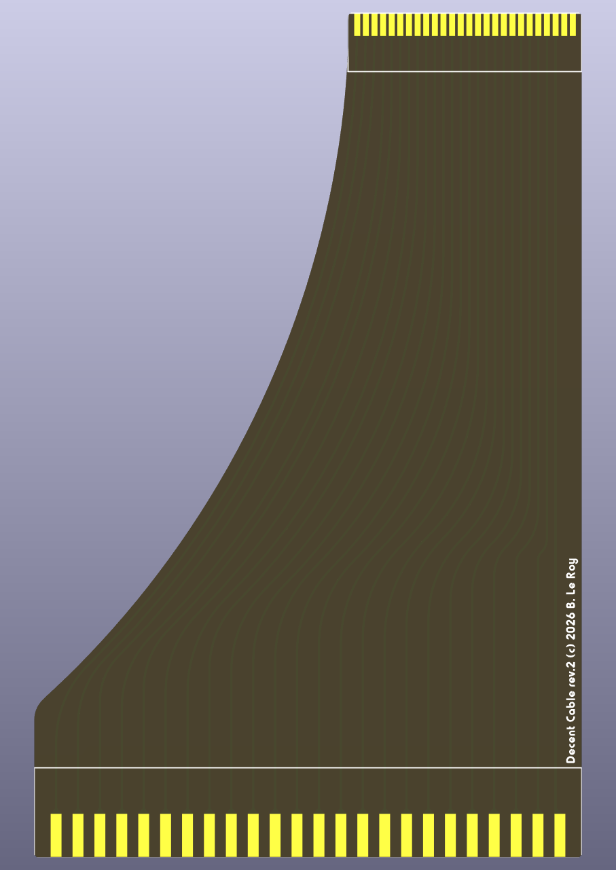
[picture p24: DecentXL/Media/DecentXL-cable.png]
The custom flexible PCB
[](./Media/DecentXL-cable.png)

### Brackets

The XL keyboard is mounted to the top of the Atari case. On some original keyboards, a metal plate has bent parts that extend beyond the PCB or membrane and fit the corresponding screw columns on the top shell of the case. Some models have a pair of metal rails that can be re-used for both modern and vintage versions of the keyboard. If your original keyboard had those, then you don't need to print brackets and can just use those rails.

* [STL file for the left bracket](./Brackets/DecentXL-Left-Bracket.stl)
  Left bracket
* [STL file for the right bracket](./Brackets/DecentXL-Right-Bracket.stl)
  Right bracket

For our keyboards, we can't unfortunately just have correctly placed holes in the PCBs because the columns extend beyond the planes where they need to be located. Instead, the columns go around the PCB and fit into 3D-printed adapters that hold the PCBs in place and receive the screws.

### Spring

If you went for a vintage keyboard, the wide space bar may need a spring. The original spring from the Atari keyboard should work, but you can also source a new 17mm x 9mm one.

### Hardware

When using MX or Alps switches, the plate will usually naturally be held at a constant height by the switches. When using low-profile switches however, it's a little trickier and I recommend using the two mounting holes at the top of the main PCB and plate to add screws and nuts or [standoffs that keep the plate at a constant distance of 3.5mm (or 1/8 freedom units)](https://www.mcmaster.com/92510A400/) from the PCB.

### LED diffuser

The new power LED is quite small, and it's a good idea to diffuse its light. There's [a part that you can print in transparent filament or resin](https://github.com/bleroy/3d-junkyard/blob/main/DecentXL/readme.md). It should fit in the LED hole of the top shell of the case.

[Model for the LED diffuser](./Misc/LedDiffuser600XL.stl)

Thanks to [@Waynetho](https://forums.atariage.com/profile/67688-waynetho/), there's a model for the LED diffuser that mimics more closely the look of the old power LEDs:

- [800XL "bulb" diffuser](./Misc/800XL%20LED%20diffuser.stl)
- [600XL "bulb" diffuser](./Misc/600XL%20LED%20Diffuser.stl)
- [Black washer for either model](./Misc/LED%20diffuser%20black%20washer.stl)

## Assembly

Once you've gathered all the parts, you can assemble them in the following order:

### Mount the stabilizers

The stabilizers consist of a larger part that has the threaded part, a smaller part that slides into the previous one, a metal bar linking two assemblies of the two previous parts, and some hardware. The stabilizers are best assembled in this order: slide the smaller part into the larger one (make sure you orient it properly), then insert one end of the metal rod into that assembly and push it into place so it clicks and is properly secured. Once you've done that with both ends of the stabilizer, you should be able to verify both ends lift together and with no friction (some people like to lube their stabilizers by the way).

Once the stabilizers are assembled, you can put them in their respective places on the top side of the PCB. Insert the bottom, non-threaded part first, try to lay the stabilizer's surface flat on the PCB, and push the top threaded part into place. This usually moves the other end a bit, so make sure both ends are properly inserted all the way into the holes in the PCB.

Turn the PCB over. Position one of the small washers around each of the screw holes for the stabilizers and secure it with a screw.

#### Special vintage stabilizers

Stabilizing vintage caps can be challenging. If you went down that route, be patient: it can be done, but it's difficult.

Bending a copper rod to be the correct distance between stabilizers is hard, but can be done with a good pair of pliers, and fulsh cutters.

In some cases you'll have to print adapters that either fit inside the key cap or replace the stem of a Durock stabilizer.

### Configure the keyboard for your layout (Rev. 2 and 3 only!)

Solder two small jumper wires **horizontally** to the left of the PCB to configure it for Caps or Control. This rewires the key that's above left shift and that's normally Control on an original keyboard. Control on the modern keyboard goes to the left of the space bar, and this key is reconfigured to be Caps. The two wires should short from the middle position to the right position for modern, and from the middle to the left for vintage. The silkscreen has helper text for this.

Revisions 4 and after require no configuration because modern and vintage are separate, pre-configured PCBs.

### Mount the switches onto the plate

Insert switches into the aluminum plate with the LED window to the back and the pins to the front.

On modern layouts, the exception to this is the return key that should have its LED window to the left and pins to the right.

On vintage revisions preceding 4, delete, return and caps have a different orientation. It's more practical to wait and add those at the next step, while soldering the switches.

Note that the console keys do not have a place on the plate. That's because they will be aligned using a separate printed plate.

There are 4 additional positions around the space bar, control and break keys for F1-4 optional keys. Usually you won't mount switches onto those, just ignore them unless you have a modified case that can accommodate them.

### Get the plate and PCB together

After making sure all the switch pins are vertical and none are bent out of place, carefully align the plate and switches with the stabilizers and the PCB. Slowly and carefully complete that assembly, making sure no pins get bent. Once that is done, the plate and PCB should be a few millimeters apart, evenly spaced across the whole surface.

If using low-profile switches, mount standoffs between the plate and main PCB using the two mounting holes on top of the boards.

You can secure the boards together with tape or clothespins until you've soldered enough switches.

### Solder the switches onto the PCBs

Solder each switch onto the PCBs. Use a printed plate to align the console keys before soldering them.

### Assemble the daughter board (Rev. 2 and 3 only!)

This is only for older revisions of the boards. The current versions don't have a daughter board.

Carefully align the switches on the daughter board using the printed console plate. Solder them in place. Mounting the caps before soldering can help achieve better alignment. Soldering one leg, adjusting orientation, then soldering the second leg, is a way to improve alignment, especially in the absence of a guiding plate.

### Assemble the brackets

If you have rails, you can skip this part.

Gently insert the PCBs into the brackets. There is some lateral freedom in the assembly to allow for the 0.25U narrower modern layout to be centered in the case: if you're using the modern layout, you'll want to shift the main board a few millimeters to the right to perfectly center the keyboard.

### Plug the cables

If you're on a rev. 2 or rev. 3 PCB, add the cable linking the daughter board to the main board.

The cable that connects the keyboard to the motherboard is a flexible PCB. Pass the smaller end of the custom cable through the hole in the bracket (if using bracckets, through the hole in the PCB otherwise) and then plug it into the connector on the bottom-right of the keyboard PCB. This can be tricky to get right: make sure the cable is inserted sufficiently that closing the connector will hold it in place and properly connected. You can verify continuity on the pads at the extremities to verify you got this right.

Contacts go on the bottom side.

### Add cap adapters

If you need them (vintage), add the cap adapters to your switches.

### Add the key caps

Assemble the key caps onto the switches or cap adapters. If needed, don't forget to insert the stabilizer adapters into the relevant key caps before you press fit them onto the switches and stabilizers.

Apply brushed metal stickers to the console keys. I find that holding the stickers with an Exacto knife is a good way to get the alignment precisely right. Take you time for this, as misalignments tend to be very visible with the keys so close to one another. Avoid touching the underside of the stickers as fingerprints can cause oxydation of the brushed metal layer in the sticker.

3D-printed console keys

Your keyboard is now assembled. Let's mount it into the computer.

## Mounting the keyboard into the computer

You might want to briefly connect the keyboard before mounting it and turn the computer on to check the LEDs light up. If you need to tune the brightness of the backlight to the desired level, this is a good time to do it by turning the pot on the bottom-right of the board. If you do it later, you may have to remove the keyboard from the case.

Before you assemble the keyboard into the top shell, make sure you've inserted the printed LED diffuser into the LED hole. It should just fit into 600XL cases, and require some tape to hold it in place on 800XL.

If you have rails, mounting the keyboard should be very easy: just position your keyboard on the back of the top case, then screw the rails on top of that. You have some freedom on the horizontal alignment of the keyboard (not a lot, but enough to get your console keys properly centered).

DecentXL keyboard mounted into a 600XL using rails. Make sure that unlike me, you've installed the cable before mounting the keyboard.

If using brackets, align the bracket screw holes with the correct columns on the top shell of your Atari XL case and screw the keyboard in place. Make sure to precisely center your keyboard in its window, moving it in the barckets if necessary, then secure the screws in place. This can take some trial and error. Take your time so your keyboard is nicely centered.

Mounted keyboard

Plug the larger end of the custom cable into the Atari motherboard's connector.

Backlighting

Close the case. Congratulations, you're done! Turn your computer on and enjoy your mechanical keyboard. It's a good idea to go into the Atari diagnostics or BASIC and check every key works.

## Troubleshooting

Defects and mistakes happen. If when testing your keyboard, if you notice a key or a bunch of them don't work, testing and fixing the keyboard is usually quite easy.

The back of the PCBs

The back of the board shows the matrix the keyboard is built on. It's easy, from the indications there to figure out what pins a switch is supposed to connect. It's like coordinates: the keyboard is essentially a matrix of switches. You can test continuity using the empty pinout connector footprint above the FFC connector. Connect your multimeter, press the switch. Be aware that there's an anti-ghosting diode in series with each switch, so setup your multimeter accordingly or you may get false negatives. You can also test the switch directly, and test continuity from it to its neighbours and to the connectors. Most problems can be found this way, and if the keyboard needs repairs, it's usually easy to pull an additional wire to fix a damaged trace.

## Acknowledgements

I want to thank [XLFreak](https://forums.atariage.com/profile/63723-xl-freak/) for designing the modern key cap set for this project.

Thanks to [Wildstar87](https://forums.atariage.com/profile/29638-wildstar87/) who has been loaning me various XL keyboards and case parts to check their footprints and design adapters.

Thanks to ABBUC members for voting for this project and giving it first prize at the 2023 hardware contest.

And of course, many thanks to all those who provided feedback on the [DecentXE keyboard](https://github.com/bleroy/3d-junkyard/tree/main/Atari130MX) over its many revisions or bought a keyboard.

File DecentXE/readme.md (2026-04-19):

# Decent XE mechanical keyboard replacements for Atari XE computers

Open source licenses

Whether you have an old Atari XE computer with a dead keyboard membrane, would like to use a XE keyboard with your favorite PC emulators, or just want to build a more modern XE keyboard, this is the project for you.

The DecentXE keyboard with modern graphite key caps

There are two versions of the keyboard: modern and vintage. Modern uses brand new MX-compatible key caps, while vintage uses the original Atari key caps and adapts them to modern switches.

There's been a number of previous projects to put a modern keyboard on Atari 8-bit computers. I don't think anyone's done it while preserving the original keycaps though (would love to be proven wrong). Once assembled, you can't tell the difference from an aesthetic point of view... Check this out:

Vintage DecentXE keyboard

But wait!... That's not all. Since the project started, there's been multiple revisions, adaptations to all kinds of demands from other Atari enthusiasts, and you now have many options to build the keyboard of your dreams...

## Current version

The current revision of the DecentXE modern keyboard is: **rev. 16.1**.

## Can I buy one?

The project is open-source, and I'm encouraging everyone to try to build their own. I do sell kits and assembled keyboards (both modern and vintage) for those who are not comfortable with ordering parts, PCBs or using a soldering iron. If you'd like to order something, [drop me a personal message on AtariAge](https://forums.atariage.com/profile/76850-screamingattheradio/). Keyboards and kits are made to order, so expect several weeks between ordering and receiving.

How expensive is it? It depends on what you're ordering, but this is a made-to-order custom mechanical keyboard, so, not cheap. You can find all the prices [in this thread](https://forums.atariage.com/topic/352558-decent-xe-mechanical-keyboard-for-atari-xe-computers-how-to-order-one/).

## Project history

My first attempt at this was to replace the stem in a [Kailh Box Pink switch](https://novelkeys.com/collections/switches/products/kailh-box-switches?variant=40598132129959) with a 3D-printed version that replaces the regular MX cap footprint with an Atari XE cap footprint. The modified stems were printed with my first printer, an Elegoo Mars 2 Pro. Its 50 micron resolution was essential when replacing such a small and precise part.

This worked great, with switches that were a little more gritty than the originals but still a huge improvement over the mushy XE keyboard I was replacing.

As I made the project public on [Atariage forums](https://forums.atariage.com/topic/324588-atari-130xe-keyboard-rebuild-vintage-keycaps-on-modern-switches), I quickly discovered the key caps I had on my 130XE were only one of two variants, and not the most common at that. I've been supporting both variants, square and circle ever since.

The stabilizers were costar stabilizers for the left shift, which required some creative bending of the vintage stabilizer rod and always remained a little clunky. The space bar rod has a larger diameter and necessitated 3D-printed stabilizers that were, to be frank, terrible. They sorta did the job, just poorly.

Stems and stabilizers, comparison with stock parts

The first plate I made was water-jet-cut steel. That was expensive and rusty. I quickly realized after that first attempt that PCB fabrication houses can make aluminum PCBs for cheap. Those are machined rather than laser or water-jet cut, but the quality is perfectly adequate for a fraction of the price. They are just PCBs without circuitry on them. I later learned how other handmade keyboard makers use the same trick, including with regular PCBs, although aluminum is clearly superior for this application.

The first connector I used was an ad-hoc cable made from breadboard jumper wires (I replaced the notoriously hard to source 24 pin Atari connector with pin headers). Based on early feedback, this was quickly replaced with a choice of standard flat cables, to the 1mm pitch 26 pin FFCs used today. Why 26 pins? Because 24 pin FFC connectors and cables don't exist or are hard to source whereas the 26 pin versions are commonly used in DVD players and printers. Also, that gives us two additional lines to separate the backlighting power from the rest, but that in itself came later, at first there was no backlighting and those two additional lines just duplicated the 5V and ground lines, which was just good practice at the time, but turned out to provide that feature for free later without breaking pinout back-compat.

On the side of the Atari motherboard, an adapter was needed that could plug into the original 24 pin connector or be soldered to pin headers, and had a 1mm pitch 26 pin FFC connector on the other side. The main difficulty is that there's very little space between the motherboard and the bottom of the keyboard.

The next breakthrough resulted from re-thinking the constraints:
* Keep compatibility with vintage key caps
* Keep the assembly the same height as the original so everything looks unchanged, including function keys flush to the case

Keeping the same height with MX switches meant replacing internal parts. This is time-consuming and results in lower-quality. What if instead you could work with lower switches that give enough vertical space to build an interface between the switch and the cap? That's what led me to consider low-profile switches. My first choice was to remain with Kailh switches, that I like quite a lot, and I picked Choc v1, specifically Robins that have a clicking behavior similar to Box Pinks. Using adapters instead of replacing internals however also gave the side benefit to allow people to choose the switches they prefer. If you prefer linear or tactile, that's fine.

I made a new version of the PCB for Choc switches which was also the first to have backlighting.

Then there were demands to support more types of low-profile switches to allow for cheaper alternatives to Kailh Chocs.

Around the same time, I had been trying to find reasonably affordable small batch key cap sets to make it possible to build a keyboard without depending on vintage parts. XLFreak is the one who designed and sourced new key caps from [WASD](https://www.wasdkeyboards.com/) (no longer in activity). The very wide space bar doesn't exist on modern keyboards, so we had to shuffle things around. I think the layout that came out of this is better than the original: we get a larger backspace key, an ISO return key, control moves to the left of the smaller 6.5U space bar, break to its right, caps moves to its modern place above left shift. I was able to lay out the PCB so it's compatible with both the vintage and the modern layouts with a single configuration header.

In order to simplify things and have a single unified PCB design, I designed a switch footprint that could accommodate four different kinds of switches: MX, Kailh Choc, Gateron low-pro and RedDragon low-pro.

I also moved the Raspberry Pi Pico connection off the board to a separate USB adapter board since not everybody needed it and it added routing complexity.

It was also a good time to update the stabilizer design. For modern caps, there was no reason not to use the better alternative that are Durock v2 stabilizers. For vintage caps, I wasn't able to swap left switch stabilizers because the way vintage shift keys are built doesn't leave space for 2U Durock v2 stabilizers.

That was where we were with revision 11, which shipped as a pre-order to readers of [the AtariAge forum thread](https://forums.atariage.com/topic/324588-atari-130xe-keyboard-rebuild-vintage-keycaps-on-modern-switches/).

**Revision 12** moved the FFC connector to the top side of the board so it could be assembled at the fab house with the other surface-mount components, and moved to the bottom-right of the board, next to the break key. The FFC cable is now routed to the front between the two halves of the shield.

The power LED is now surface-mount like the backlight LEDs.

The optional function keys (F1-4) pins are now duplicated on a separate header on the top-right of the board to enable easy wiring of those pins to keys placed for example in an extension device.

The adapter that plugs into the motherboard was now smaller, leaving more space above and removing the requirement to replace the Atari keyboard connector and replace it with pin headers (although that was still recommended). The adapter's FFC connector was now moved to the left of the connector instead of above it.

The plate outline has been modified to let more power LED light through.

The silkscreen has been updated to give clearer instructions about configuring the keyboard for vintage or modern modes.

**Revision 13** changes console keys (Help, Start, Select, Option and Reset) to use low-profile switches, which enables thinner 3D-printed key caps that better fit the XE case.

The PCB now has a visual representation of the keyboard matrix with pin numbers, making debugging easier.

The PCB and plate have a consistent Harry Fatt typeface, and each key gets all its glyphs represented, which makes it easier to use the keyboard without caps.

**Revision 14** replaced the adapter and flat cable with a flexible PCB.

**Revision 15** splits the modern and vintage designs. This removes the requirement to have configuration headers and greatly simplifies the layout of the PCBs. I also stopped building assembled vintage keyboards myself with this version, instead focusing on the higher quality modern keyboards. The files for vintage remain available for thos who want to build their own.

**Revision 16**

[x] Power LED switched to red in BOM
[x] Optional red LED diffuser 3D model
[x] Mid-keyboard support 3D model
[x] Back of the board padding 3D model for better fit in the XE case
[x] Console keys have stabilization holes in PCB and plate
[x] Plate covers the whole width of the keyboard and conoles keys area
[x] PCB made 1.75mm deeper to reach the case's fins on the back of the keyboard area
[x] Remove legends from plate front so it's a uniform black between key caps

**Revision 16.1**

[x] Moved the cable slot and connector apart for easier assembly.
[x] Rerouted the whole thing with wider power tracks.

## Options

### Key caps: vintage or modern?

My own original preference was to use the original key caps from a vintage Atari XE computer. They can be scavenged from an existing computer, or from new old stock that's still available at the usual places. The result is, like above, visually indistinguishable from the original keyboard, but feels oh so much better.

XLFreak has been working on new caps in the style of old Atari caps, but that can be produced in small quantities. The nice thing about those is that no adapter is necessary and the end result is an amazing keyboard that is and feels in every way like a great modern keyboard. This is now my preferred option to upgrade Atari XE keyboards.

### Switches

If you're using modern key caps, you may choose any MX-compatible switch. You'll need 5 low-profile Kailh Choc v1 switches for the conole keys.

If you're using vintage caps, you can pick any Kailh Choc v1 low-profile switch.

## Design

The Decent XE project is built on [an original PCB design](./Keyboard/DecentXE-Modern.kicad_pcb), [a custom aluminum plate](./Plate/DecentXE-plate-modern.kicad_pcb), [MX-compatible switches](https://www.kailhswitch.com/mechanical-keyboard-switches/smt-key-switches/box-blue-white-switches-for-mechanical.html), [Kailh Choc v1 low-profile switches](http://www.kailh.com/en/Products/Ks/CS/), custom key caps, 3D printed adapters and Durock v2 and Costar stabilizers.

The DecentXE keyboard assembly

Here's [a video showing revision B of the project)](https://youtu.be/r8T07Rskkgs):

Atari 130XE keyboard rebuild (https://www.youtube.com/watch?v=r8T07Rskkgs)

And here's [another](https://youtu.be/FDqwOca9oRQ/) showing the revision 11 with modern caps:

DecentXE keeb (https://www.youtube.com/watch?v=r8T07Rskkgs)

DecentXE schematic

## Bill of materials

This project is meant to be reproduced. You'll need a few things that are more or less easy to source, so I've made sure to give multiple roads to success and alternatives for most parts.

It's also an approach that could easily be adapted to other vintage computer keyboards, Atari or not. Everything is provided [under an open source license](../LICENSE) so you're encouraged to reproduce and fork the design.

### Atari XE computer

The project is designed around the conservation of the look of Atari XE computers and the integration of the keyboard in its original case. As such, you'll need a host XE computer to receive the end product.

It is also possible however to build and use this keyboard and use it with an emulator on a PC or Mac through a USB adapter. In this way, you can get closer to the original experience even if you don't have access to the original hardware.

* Optimal: Atari XE computer
* Fine: a PC, mac or a MiSTer with [an emulator](https://www.virtualdub.org/altirra.html)

### Key caps

The best result will be obtained with new key caps.

Key caps can be sourced from [ThockFactory](https://thockfactory.com/fr/configurator) or [GoblinTech](https://goblintechkeys.com/collections/60-keycap).

#### ThockFactory

Use the following configuration files in the ThockFactory configurator:

* [Modern layout (white)](./Caps/Atari%20XE%20-%20White%20-%20Thock.json)
* [Modern layout (Falcon)](./Caps/Atari%20XE%20-%20Falcon%20-%20Thock.json)

#### GoblinTech

Use the following templates when ordering from GoblinTech:

* Modern layout (white)
* Modern layout (Falcon)

#### Vintage

Vintage key caps from an Atari XE computer can also be used to maintain a look that is indistinguishable from the original. Old-new stock of XE keyboards is also currently available without too much trouble and for a reasonable price.

* Optimal: MX-compatible set of key caps
* Fine: vintage set of XE key caps

### Console keys (Help, Start, Select, Option, Reset)

If you're using modern key caps, you'll need to make a choice for console keys.

The best solution is to re-use your vintage console keys with adapters.

Itś also possible to [3D-print your own](./Caps/fn-console-set-choc.stl) and then paint them. I recommend [Tamiya Sea Grey model paint](https://www.tamiyausa.com/shop/acrylic-paint-flat-mini-10ml/acrylic-mini-xf-83-m-sea-gray/) for a pretty good match with the Atari XE case color. You can mask the legends when painting to make them stand out.

* Fine: 3D-printed
* Optimal: vintage function keys on adapters

### Switches

A choice of switches is highly personal and there are many options. Get a sample set if you don't have a preferred kind. You can choose between MX-compatible switches for modern caps and any Kailh Choc v1 switch for conole switches or for the vintage version.

There are three main categories for switches:
* linear (such as reds): the resistance from the switch is about constant as it's pressed.
* tactile (such as browns): there's a slight bump of resistance as the switch is pressed, giving more feedback than linear switches.
* clicky (such as whites): there's a bump in resistance (or it feels like thereś one), accompanied with an audible and satisfying clicking sound.

Console keys should now be mounted on Kailh Choc v1 low-profile switches, so you'll need to buy 5 that match the characteristics of your main keyboard choice (clicky, linear or tactile).

* Optimal: 57 MX-compatible switches of your preferred brand and kind (for modern caps) + 5 Kailh Choc v1 switches for the console keys
* Fine: 62 Kailh Choc v1 low-profile switches (for vintage caps)

### Adapters

The switch adapters link vintage caps to modern switches. As such, you don't need them if you opted for all modern caps. If you're using vintage console keys, you'll need 5 adapters.

The best option today is to simply have the adapters printed, for example by JLCPCB.

Online printing services have become very inexpensive, and the quality of their prints can't be rivalled by any hobbyist printer available today. The trick for small parts such as these adapters is to group them in [batches](./Stems/kailh-choc-to-xe-circle-set.stl) so they count as a single part. I stopped printing locally after the prototyping phase, and am now ordering all my 3D prints from JLCPCB.

If you decide to print them, you'll need a resin printer with a resolution of 50 micrometers (1/20th of a millimeter) or better.

The choice of resin is very important, as the same design on the same printer can give wildly varying qualities of print. For instance, I stay away from all grey Elegoo resins, as I found them to blur the design and be very unreliable. The resin I've had the best results with is Elegoo's [clear red](https://www.elegoo.com/collections/resin/products/elegoo-standard-resin?variant=32365787807792). Resin prints also tend to be brittle, and it's no fun trying to remove a broken leg from inside a switch's stem or a key cap.

There are adapters in the repo for all types of vintage XE caps. You can even generate your own by using [the OpenScad model](./Stems/keeb-stem.scad), which is fully parametric.

* Optimal: order from a fab house such as JLCPCB
    - 7x [set of circle adapters](./Stems/kailh-choc-to-xe-circle-set.stl) or 7x [set of square adapters](Stems/kailh-choc-to-xe-square-set.stl) if you're going full vintage.
    - 5 adapters, circle or square. You can use one of the sets above (10 adapters per set).
* Fine: print your own with a resin printer

I also sell adapters separately from keyboards.

### Board padding (obsolete as of rev. 16)

A revision 15.2 keyboard with 3D-printed padding added for better stability

For the most stable results, you can add two [padding 3D-printed parts](./Stabilizers/HeightPadding.stl) on top of the main board at the bottom left and right:

board padding, photo courtesy of Clint Thompson

Those can be printed on any 3D printer as they don't require a lot of precision.

[Additional padding](./Misc/XE-rev-before-16-depth-padding.stl) can be added to the back of the board to prevent the keyboard from moving to the back of the computer.

### Mid-keyboard support

While the XE case provides some support to the middle of the keyboard with a column, pressing the console keys can still cause some bending of the board. To prevent that, [support](./Misc/XE-mid-keeb-support.stl) can be added to the left of the console keys.

### Power LED coloring

If you have a board with a white power LED and your XE case has a transparent LED window, you can still make thepower LED shine red using a [LED diffuser](./Misc/LED-red-lens.stl) printed in transparent red.

### Stabilizers

If you're using modern caps, just use Durock v2 stabilizers for backspace, Return, left shift and the space bar.

The Atari XE keyboard has stabilizers on the left SHIFT key and on the space bar. Some versions also have stabilizers on control and right shift, but anything 2U and smaller can work well without stabilizers.

The left shift stabilizer is made with a standard metal bar that fits in standard costar stabilizers, for which the vintage plate is designed. There are two possible orientations for the costar stabilizers that work best for the circle and square variants of vintage key caps. Those stabilizers can be bought for a very reasonable price from many places.

The vintage space bar can use Durock v2 stabilizers, for which I've made adapters for both types of vintage Atari space bars.

* Optimal (modern caps): 1x 6.5U and 3x 2U Durock v2 stabilizers
* Fine (vintage caps):
    * Vintage Atari XE left shift stabilizer metal part
    * 2x standard costar stabilizers
    * 1x 6.5U Durock v2 stabilizer set
    * 3D-printed stabilizer adapters [for circle](./Stabilizers/durock-v2-spacebar-circle-adapter.stl) or [square](./Stabilizers/durock-v2-spacebar-square-adapter.stl)

### Main board

The [DecentXE KiCad project](./Keyboard/DecentXE-Modern.kicad_pcb) should have everything you need to order a 2 layer PCB from any manufacturing house. The board requires surface-mount diodes, LEDs, resistors and connectors that are best assembled at the fabrication house: nobody wants to solder 62 of the same very tiny components by hand. I think. I don't.

The DecentXE main board

* Optimal:
    - [DecentXE Modern main board Gerber files](./Keyboard//production/Decent_XE_Keyboard_-_Modern_16.1.zip)
    - [DecentXE Modern BOM file](./Keyboard/production/Decent_XE_Keyboard_-_Modern_16.1-bom.csv)
    - [DecentXE Modern Position file](./Keyboard/production/Decent_XE_Keyboard_-_Modern_16.1-positions.csv)
* Fine:
    - [DecentXE Vintage main board Gerber files](./Keyboard//production/Decent_XE_Keyboard_-_Vintage_15.zip)
    - [DecentXE Vintage BOM file](./Keyboard/production/Decent_XE_Keyboard_-_Vintage_15-bom.csv)
    - [DecentXE Vintage Position file](./Keyboard/production/Decent_XE_Keyboard_-_Vintage_15-positions.csv)

### Plate

While it is possible to build and operate a keyboard without a plate, it will not be as nicely aligned and won't feel as solid as it would with a proper plate.

The plate

In terms of weight, the keyboard assembled with an aluminum plate is about 430g.

* Optimal: 1.6mm aluminum PCB. Aluminum PCBs can be made for similar prices as regular PCBs nowadays, and that constitutes the best price / performance compromise currently available.
    - [DecentXE Modern aluminum plate Gerber files](./Plate/production/Decent_XE_Keyboard_Plate_-_Modern_16m.zip)
    - [DecentXE Vintage aluminum plate Gerber files](./Plate/production/Decent_XE_Keyboard_Plate_Vintage_15v.zip)
* Great but expensive: laser-cut or waterjet-cut metal
* Not fine: laser-cut acrylic. Really, don't even try, it'll shatter. Some other laser-cut plastics may be OK, but I can't help you with that, I don't know.

When using vintage caps, you may need to add some spacers between the board and the plate while building, in addition to the switches themselves. I've been using stacked washers.

There's a smaller, 3D-printed plate for the console keys that also adjusts the height of the switches relative to the PCB:

* [Console key plate](./Stabilizers/LowProRaiserPlate.stl)

### Connector

The original Atari XE keyboard's connector was just a part of the mylar membrane. We need a replacement for that. Note that the clearance between the Atari XE motherboard and the bottom of the keyboard is very small at about 16mm.

The current solution is a custom flexible PCB that can plug directly into the Atari motherboard connector, and is compatible with a modern 1mm 26 positions surface-mounted connector on the other side:

The Decent flexible PCB

If your Atari connector is damaged, or you don't have one, it's also possible to solder [an adapter](../Atari130MX/Atari130MX-adapter/Atari130MX-adapter.kicad_pro) and use a standard 1mm pitch 26 position flat cable.

* Optimal:
    * [Flexible PCB](../DecentXL/DecentXL-Cable/production/DecentXL_Flexible_Cable_2.zip).
* Fine:
    * [FFC 26 position 1mm Type A](https://www.digikey.com/en/products/detail/adafruit-industries-llc/5386/16129671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) (contacts on the same side on both ends) ribbon cable, 15cm at least.  Here's also [an Amazon source](https://www.amazon.com/uxcell-Flexible-Cable-Ribbon-Player/dp/B07RWRX6YT/r).
    * [XE keyboard Adapter](../Atari130MX/Fabrication/DecentXE-adapter.zip)
    * 1x24 2.54mm pin headers

## Fabrication and assembly instruction

Once you've sourced all the components, it's time to assemble. The following instructions attempt to reflect all the choices you may have made in selecting components.

Jan Beta has a great video where he shows the full assembly process (the mistake he makes with the config jumpers can no longer be made: those are gone from the design).

Jan Beta's build (https://www.youtube.com/watch?v=BoW_3545O0c)

### Printing console caps and adapters (optional)

There are two known shapes of vintage key caps, requiring distinct adapters. The first type of key cap has square stems, while the second has circular stems.

In this repository, you'll find [OpenScad](./Stems/keeb-stem.scad) and [STL](./Stems) files for [both](./Stems/kailh-choc-to-xe-circle-set.stl) [types](./Stems/kailh-choc-to-xe-circle-set.stl) of stems. If you need to modify anything about the stems, you'd need to regenerate the STL from the OpenScad file. There is [a single OpenScad file](./Stems/keeb-stem.scad) that covers both types of stems through configuration. Otherwise, just send the STL file to your 3D printing manufacturer.

You'll need 62 adapters total for the whole vintage keyboard, and only 5 for modern if you want to re-use your vintage console keys.

### Optional: replace the Atari connector

If you lack the original Atari connector on your motherboard (rare), you may want to use an adapter and solder that in.

### Installing a modern keyboard (assembled)

I do sell assembled modern keyboards, but you still need to get those into your Atari. This section goes through the details of doing that.

The FFC cable should already be attached to the keyboard.

[skip to the common section](#common-section-inserting-the-adapter)

### Installing a vintage keyboard (assembled)

Use a key cap extractor to remove the keys from your vintage keyboard (a key extractor is the best way to make sure you don't damage the caps). Make sure to be especially gentle if you have the square variant, those break easily.

Put the two space bar stabilizer adapters into your vintage space bar. You can set aside the old metal rod for this key, you won't need it. The alignment of the stabilizers and the adapters is not always perfect. If that's a problem in your build, you can try to adjust the OpenScad model to move the footprint and better align with your space bar. Even with good alignment, I recommend salvaging the spring from the original keyboard and inserting it into the new keyboard. It does make a big difference for vintage builds.

Remove the stabilizer rod for your left shift key. You'll need to slightly bend this so it can go around the new switch and into the new stabilizer. This may require some fiddling. In the worst case, the left shift stabilizer can be omitted if you can't find a way to make it work. This is my least favorite part of those keyboards...

Assemble the caps back onto the new keyboard by gently pressing them into place.

[skip to the common section](#common-section-inserting-the-adapter)

### Modern keyboard (kit)

If you ordered a kit or parts from the BOM, there is a specific order in which you should assemble.

#### Assemble the Durock stabilizers

The stabilizers consist of a larger part that has the threaded part, a smaller part that slides into the previous one, a metal bar linking two assemblies of the two previous parts, and some hardware. The stabilizers are best assembled in this order: slide the smaller part into the larger one (make sure you orient it properly), then insert one end of the metal rod into that assembly and push it into place so it clicks and is properly secured. Once you've done that with both ends of the stabilizer, you should be able to verify both ends lift together and with no friction (some people like to lube their stabilizers for added smoothness).

Once the stabilizers are assembled, you can put them in their respective places on the top side of the PCB. Insert the bottom, non-threaded part first, try to lay the stabilizer's surface flat on the PCB, and push the top threaded part into place. This usually moves the other end a bit, so make sure both ends are properly inserted all the way into the holes in the PCB.

Turn the PCB over. Optionally position a small washers around each of the screw holes for the stabilizers. Secure the stabilizer into place with a screw. Repeat this for the space stabilizer, the left shift, the delete key and the return key.

#### Solder the console key switches

The console key switches go *under* the plate, and as such need to be soldered before the other switches are inserted into the plate and soldered.

#### Add the cable

Insert the flexible PCB from below the PCB into its slot through the PCB, so the contacts are on the bottom and can face the board.

Pull the two tabs for the connector, then insert the contacts into the connector, pushing the cable as far as it will go. Push the tabs back in.

At this point, I usually test continuity between a few of the solder points on the board to the other end of the connector, in order to check the cable is properly inserted and secure.

#### Mount the switches onto the plate

Insert switches into the aluminum plate with the LED window to the back and the pins to the front. The exception to this is the modern return key that should have its LED window to the left and pins to the right.

Note that the console keys do not have a place on the plate. That's because they use low-profile switches that wouldn't reach the height of the plate. We'll assemble those later.

#### Get the plate and PCB together

After making sure all the switch pins are vertical and none are bent out of place, carefully align the plate and switches with the stabilizers and the PCB. Slowly and carefully complete that assembly, making sure no pins get bent. Once that is done, the plate and PCB should be a few millimeters apart, more or less evenly spaced across the whole surface. You may want  to secure them together with tape or clothespins until you've soldered enough of them.

#### Solder the switches onto the PCB.

Solder each switch onto the PCB.

Once you've done all the full-size switches, insert the low-profile switches for the console keys into their 3D-printed plate, then align that to the PCB. Solder the switches.

Even after soldering, you can make small adjustments by melting the solder around one of the pins and carefully moving the switch, then reflow the other pin of the same switch to relieve constraints or further adjust.

[skip to the common section](#common-section-inserting-the-adapter)

### Vintage keyboard (kit)

If you ordered a kit or are building one from parts from the BOM, there is a specific order in which you should assemble.

#### Assemble the space stabilizer

Assemble the space stabilizer. The stabilizers consist of a larger part that has the threaded part, a smaller part that slides into the previous one, a metal bar linking two assemblies of the two previous parts, and some hardware. The stabilizers are best assembled in this order: slide the smaller part into the larger one (make sure you orient it properly), then insert one end of the metal rod into that assembly and push it into place so it clicks and is properly secured. Once you've done that with both ends of the stabilizer, you should be able to verify both ends lift together and with no friction (some people like to lube their stabilizers by the way).

Once the stabilizer is assembled, you can put both ends in their respective places on the top side of the PCB. Insert the bottom, non-threaded part first, try to lay the stabilizer's surface flat on the PCB, and push the top threaded part into place. This usually moves the other end a bit, so make sure both ends are properly inserted all the way into the holes in the PCB.

Turn the PCB over. Optionally position a small washers around each of the screw holes for the stabilizers. Secure the stabilizer with a screw.

#### Add the cable

Insert the flexible PCB from below the PCB into its slot through the PCB, so the contacts are on the bottom and can face the board.

Pull the two tabs for the connector, then insert the contacts into the connector, pushing the cable as far as it will go. Push the tabs back in.

At this point, I usually test continuity between a few of the solder points on the board to the other end of the connector, in order to check the cable is properly inserted and secure.

#### Mount the switches onto the plate

Insert switches into the aluminum plate with the LED window to the back and the pins to the front.

#### Get the plate and PCB together

After making sure all the switch pins are vertical and none are bent out of place, carefully align the plate and switches with the stabilizers and the PCB. Slowly and carefully complete that assembly, making sure no pins get bent.

Once that is done, the plate and PCB should be a few millimeters apart, more or less evenly spaced across the whole surface. Low-profile switches have a tendency to not attach to the plate as well as full-sized switches, so don't worry if some of these fall out during assembly, you'll have a chance to set them back in later. At this point, you want to have enough switches in place to ensure proper alignment.

Another thing with low-profile switches is that they're not as good at maintaining the distance between PCB and plate. To make that distane more even with the distance imposed by the space stabilizer, there are two holes for M2 screws at the top of the plate and main board. Use three M2 nuts to keep the correct distance between the plate and PCB. Secure everything from the top with one final nut.

#### Assemble the left shift stabilizer

The left shift stabilizer is more problematic and potentially the most frustrating part of this build. Worst case, it may be fine to just omit this stabilizer because if improperly installed it can make things worse. The stabilizer consists of two plastic parts that should fit into slots around the switch's position. Depending on whether you have circle or square caps, it should be installed upside up or upside down. Those stabilizers are very tricky to put in place. Once they are in place, you'll need (later, we'll get back to that) to get the metal rod from your vintage left shift, remove it, then bend it slightly so it can go around the switch and still be inserted into the new stabilizer. I'm not kidding when I say this is frustrating.

#### Solder the switches

Solder the switches onto the PCB. The Choc switches will barely stick out on the back of the PCB. This is normal, but makes soldering a little more difficult. Give the iron enough time to heat up the vias, the solder and the pins and create a proper join, even if that join ends up relatively flat.

Dont's forget the console keys. Since those do not mount on the plate, use a 3D-printed console key plate to align the switches precisely and keep the switches at the correct height.

Even after soldering, you can make small adjustments by melting the solder around one of the pins and carefully moving the switch, then reflow the other pin of the same switch to relieve constraints or further adjust.

### Common section: inserting the cable

Remove your existing keyboard, pulling the membrane connector carefully using both hands to avoid accidentally folding it.

Insert the flexible PCB into the connector on the motherboard.

Add the height padding on top of your keyboard's main PCB, to the bottom left and right.

You can now power your computer. The power LED on the keyboard should go on and the backlighting should too (this is a good time to set the potentiometer on the bottom left to a brightness level you're comfortabel with). 

It's a good idea to go to the diagnostics and try the keyboard diagnostics. If you got your keyboard from me, I've already done that, but you never know what could happen in transit.

Once you've verified everything works, just add the top of the case back.

And that's it. Let me know if you have any questions or need to troubleshoot anything.

Enjoy!

## License

All hardware in this repository is licensed under [CERN Open Hardware License v2](https://ohwr.org/cern_ohl_p_v2.pdf).
All software in this repository is licensed under the [MIT license](https://mit-license.org/).
All documentation in this repository is licensed under [Creative Commons Creative Commons Attribution-ShareAlike 4.0 International Public License](https://creativecommons.org/licenses/by-sa/4.0/legalcode).

Full terms can be found in the [LICENSE](./LICENSE) file or on the web sites linked above.

## Certification

This project is [certified open source hardware by OSHWA](https://certification.oshwa.org/us002378.html).

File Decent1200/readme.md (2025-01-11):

# Decent 1200 mechanical keyboard replacement for Atari 1200XL computers

The Decent 1200 keyboard with charcoal modern key caps

Whether you have a vintage Atari 1200XL computer with a deficient keyboard or just want a better keyboard, this is the project for you.

There are two versions of the keyboard: modern and vintage. Modern uses brand new MX-compatible key caps and switches, while vintage keeps the original vintage Atari caps and adapts them to modern switches.

The vintage version can use Kailh Choc v2 low-profile switches, in which case 3D-printed adapters bridge one of the supported variants of XL key caps to the Choc switches' MX footprint.

There's been a number of mechanical keyboard builds for Atari computers that are all great but tend to be one-off projects that are not designed to be reproduced or commercially produced. This project does all that and more.

If you're looking to modify an XE computer, head over to [the DecentXE project](https://github.com/bleroy/3d-junkyard/tree/main/Atari130MX). For 600XL and 800XL keyboards, go to [the DecentXL project](https://github.com/bleroy/3d-junkyard/tree/main/DecentXL)

## Current version

The current revision of the Decent 1200 keyboard is: rev. 5m.

## Can I buy one?

The project is open-source, and I encourage everyone to build their own. I also sell modern kits and assembled modern keyboards for those who are not comfortable with ordering parts, PCBs or using a soldering iron.

How expensive is it? It depends on what you're ordering, but this is a made-to-order custom mechanical keyboard, so not cheap.

## Project history

This is a brand new design that uses a lot of lessons learned from building the [DecentXE](https://github.com/bleroy/3d-junkyard/tree/main/Atari130MX) and the [award-winning DecentXL](https://github.com/bleroy/3d-junkyard/tree/main/DecentXL), but adapts to the specificities of the 1200XL.

## Options

### Key caps: modern or vintage?

The modern versions of Decent keyboards are the best quality keyboards. It's a solid design that just feels great. In comparison, the vintage versions tend to feel more wobbly and are generally of lower quality. They are also more difficult to build, which is why I stopped producing them myself. I want to keep the quality of the assembled keyboards I build as high as possible.

The modern version also has a slightly modified layout with a large return key, and relocated control keys around the shorter space bar. Caps is relocated to where it is on a PC keyboard, above left shift (that's where Atari originally placed the control key).

If you absolutely want to keep the look and layout of your keyboard as close to the original as possible, you can use vintage caps (scavenged from the computer you're modifying or bought new old stock or used), but be aware of the quality difference. The result is visually indistinguishable from the original, if it wasn't for the backlighting, and does feel much better than the original, but is significantly less nice than the modern version... You'll also have to build it yourself since I no longer ship assembled vintage versions. See building instructions below to get a feel of the build difficulty.

### Switches

Switches are largely a matter of taste. The Decent 1200 PCB can be mounted with any MX-compatible switch. Version 3, which is the last one to support vintage, can be mounted with MX-compatible or Kailh Choc v1 switches.

It's your choice of caps that determines what type of switch to use:

* Modern: choose MX-compatible switches
* Vintage: choose Kailh Choc v1

With any type of switch, there is a wide array of choices. If you're new to the world of mechanical keyboards, there are 3 main families of switch experiences:

* Linear (often red): the switch reacts with mostly constant resistance throughout the course of the key press until it hits the bottom.
* Tactile (often brown): there is a higher resistance at a specific point of the key's course, providing tactile feedback to pressing the key.
* Clicky (often white): an even more pronounced and localized resistance is accompanied with an audible and satisfying click.

## Design

Decent 1200 schematic

The Decent 1200 project is constituted of the following parts (this is not a BOM but a list of custom parts created for this project; see below for the actual BOM):

* A PCB with adjustable blue backlighting.
* An aluminum plate to hold the switches firmly aligned and rigidify the assembly.
* A custom set of MX-compatible modern key caps.
* 3D-printed adapters for vintage caps.
* 3D-printed console keys with vinyl texture stickers.
* 3D-printed brackets to connect the boards to the 1200XL top case shell.

## Bill of materials

This project is meant to be reproduced. You'll need a few things that are more or less easy to source, so I've made sure to give multiple roads to success and alternatives for most parts.

It's also an approach that can be easily adapted to other vintage computer keyboards, Atari or not.

### Atari 1200XL computer

The project is designed around the conservation of the vintage look of the Atari 1200XL computer and the integration of the keyboard in its original case. As such, ideally you'd have a host 1200XL computer to receive the end product.

### Key caps and adapters

You'll need a set of caps.

If you've decided to go for modern, you'll need a set of modern caps that you can order from me or from [GoblinTech](https://goblintechkeys.com/collections/60-keycap).

The Decent 1200 modern layout

If you have a complete set of vintage key caps, you'll need 55 [adapters](../DecentXL/Adapters/kailh-choc-to-xl-cross-x10.stl) (more affordable if printed as 6x sets of 10).

[JLCPCB](https://jlcpcb.com/) and [PCBWay](https://www.pcbway.com/) are examples of fabrication houses that can produce high-quality prints of adapters for cheap, but there's plenty of other places where these can be done. You can also print your own (with a resin printer).

### Console keys (Help, Start, Select, Option, Reset, F1-F4, Break, Reverse video)

You'll need 11 new [3D-printed console keys](./Caps/Decent1200-console-choc.stl) (more affordable if printed as [sets](./Caps/Decent1200-console-choc-x10.stl)). The printed console keys fit on top of Kailh Choc v1 switches, not the MX switches used for the rest of the keyboard.

3D-printed console keys will look great if you apply a [brushed metal vinyl sticker](https://www.amazon.com/dp/B08L4GZRDY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). The stickers can be cut with a simple vinyl cutter such as a Cricut using [this template](./PrintedParts/ConsoleKeyStickers.svg).

### Switches

For a modern layout, you'll need 67 switches total corresponding to your cap type. You need 56 switches for the main keyboard, and 11 for the console keys. That means that you'll need 56 MX switches and 11 Kailh Choc v1 switches.

Vintage uses all Kailh Choc switches for both main keyboard and console keys with some extras due to stabilization using switches on some keys (69).

### Stabilizers and adapters

#### Modern

The modern version of the Decent 1200 keyboard uses four 2U Durock v2 stabilizers for both shift keys, return and delete, and one 6.25U Durock v2 stabilizer for the space bar.

#### Vintage

The vintage version requires a Durock stabilizer with a hand-made custom-length stabilizer rod made from [1/16" copper rods](https://www.mcmaster.com/8859K511/) and [custom printed stems](./PrintedParts/DurockInsert.stl). 

Shift and delete keys use two lateral switches as a stabilizing method.

### PCB

Use [the Gerber](./Keyboard/production/Decent1200_modern_keyboard_5m.zip), [BOM](./Keyboard/production/Decent1200_modern_keyboard_5m-bom.csv) and [position](./Keyboard/production/Decent1200_modern_keyboard_5m-positions.csv) files to order a PCB with all the SMD parts assembled (vintage versions: [Gerber](./Keyboard/production/Decent1200_keyboard_3.zip), [BOM](./Keyboard/production/Decent1200_keyboard_3-bom.csv) and [position](./Keyboard/production/Decent1200_keyboard_3-positions.csv)). That includes a pair of 4051 chips that decode and encode queries to the keyboard matrix. The 1200XL is the only Atari computer to have those chips on the keyboard and not on the motherboard, which reduces the number of wires necessary in the connector, but makes the keyboard slightly more expensive. It also makes it necessary to have a PCB for the keyboard, a requirement Atari dropped in later computers for the much cheaper membrane-based keyboards in some XL computers and in the XE computers. Note that the vintage PCB has through-hole footprints for the original 4051 chips Atari was using in their keyboards. This is usually going to remain unpopulated, and is only there to allow using vintage chips instead of the modern surface-mounted ones that should come assembled on the PCBs.

### Plate

The plate is just an aluminum PCB. Download [the Gerber](./Plate/production/Decent1200_plate.zip) and have it produced in 1.6mm aluminum. I recommend having this done in black as it will be visible through the gaps between keys and on the sides.

Decent 1200 aluminum plate

There's also [a printed plate](./Adapters/ConsoleKeyKeyPads.stl) to help with the alignment of vintage console keys if you go for the difficult choice of using vintage console keys (which again I really don't recommend). There's [a separate plate for reset](./Adapters/ResetKeyPad.stl). The console keys in this case use smaller standard tactile switches instead of mechanical switches and are mounted on [printed stems](./Adapters/ConsoleKeyAdapter1200-x12.stl).

### Connectors

The connector to the motherboard is a pair of cables with Dupont connectors on both ends. We need 15 pins spaced 2.54mm (0.1") on a single line. 15-pin connectors pretty much don't exist, but 9-pin and 6-pin ones are easy and cheap to source, for example on AliExpress. The cables should be at least 10cm long.

You'll also need 15 pin 2.54mm angled headers.

### Brackets

The XL keyboard is mounted to the top of the Atari case using 3D-printed brackets:

* [STL file for the brackets](./PrintedParts/Decent1200Brackets.stl)
  Left bracket

For our keyboards, we can't unfortunately just have correctly placed holes in the PCBs because the columns extend beyond the planes where they need to be located. Instead, the columns go under the PCB and fit into 3D-printed adapters that hold the PCBs in place and receive the screws.

### Padding

There's some space in the 1200XL case under the keyboard, which can cause some buckling in the middle. To prevent that, you can print a padding part that sit on top of the RF shield and supports the keyboard around the middle.

* [STL file for the support pad](./PrintedParts/KeyboardMiddleSupport1200.stl)
  Support pad

This is easy to print upside-down without support.

### Spring

If you went for a vintage keyboard, the wide space bar may need a spring. The original spring from the Atari keyboard should work, but you can also source a new 17mm x 9mm one.

### Hardware

When using MX switches, the plate will usually naturally be held at a constant height by the switches. When using low-profile switches however, it's a little trickier and I recommend using the two mounting holes at the top of the main PCB and plate to add screws and nuts or [standoffs that keep the plate at a constant distance of 3.5mm (or 1/8 freedom units)](https://www.mcmaster.com/92510A400/) from the PCB.

## Assembly

Once you've gathered all the parts, you can assemble them in the following order:

### Mount the stabilizers

The stabilizers consist of a larger part that has the threaded part, a smaller part that slides into the previous one, a metal bar linking two assemblies of the two previous parts, and some hardware. The stabilizers are best assembled in this order: slide the smaller part into the larger one (make sure you orient it properly), then insert one end of the metal rod into that assembly and push it into place so it clicks and is properly secured. Once you've done that with both ends of the stabilizer, you should be able to verify both ends lift together and with no friction (some people like to lube their stabilizers by the way).

Once the stabilizers are assembled, you can put them in their respective places on the top side of the PCB. Insert the bottom, non-threaded part first, try to lay the stabilizer's surface flat on the PCB, and push the top threaded part into place. This usually moves the other end a bit, so make sure both ends are properly inserted all the way into the holes in the PCB.

Turn the PCB over. Position one of the small washers around each of the screw holes for the stabilizers and secure it with a screw.

The vintage Decent 1200 keyboard only uses a stabilizer for the space bar (the other stabilized keys just have additional switches), but since the space bar is 9U and the cap footprint is different from MX caps, you'll need additional parts. First you'll need custom-printed stems for the stabilizers, that you'll assemble into the Durock stabilizers like you would the standard ones. Then you'll need a custom-length rod made from 1.6mm copper rods (see BOM for source). The rod must be cut to measured dimensions and bent carefully before being added to the stabilizers.

### Configure the keyboard for your layout (vintage only)

Solder two small jumper wires **horizontally** to the left of the PCB to configure it for Control.The two wires should short from the middle position to the left for vintage. The silkscreen has helper text for this.

### Mount the switches onto the plate

Insert switches into the aluminum plate with the LED window to the back and the pins to the front.

On the modern layout, the exception to this is the return key that should have its LED window to the left and pins to the right.

On the vintage layout, delete, return, shift and caps have a different orientation. It's more practical to wait and add those at the next step, while soldering the switches. Also note that stabilized keys need two switches on the vintage layout.

Note that the console keys do not have a place on the plate.

### Get the plate and PCB together

After making sure all the switch pins are vertical and none are bent out of place, carefully align the plate and switches with the stabilizers and the PCB. Slowly and carefully complete that assembly, making sure no pins get bent. Once that is done, the plate and PCB should be a few millimeters apart, evenly spaced across the whole surface.

If using low-profile switches, mount standoffs between the plate and main PCB using the two mounting holes on top of the boards.

You can secure the boards together with tape or clothespins until you've soldered enough switches.

### Solder the switches onto the PCBs

Solder each switch onto the PCBs.

Note the console keys use Kailh Choc v1 switches on both vintage and modern versions.

On the vintage version, each console key, as well as Esc, Tab, Caps/Control, left shift and space have two possible positions, because the keyboard doesn't have the same width for vintage and modern. For vintage, choose the leftmost position.

### Plug the cables

Solder the 15-pin angled header under the PCB (solder on the top of the PCB, header under). Plug one end of your cables onto those headers.

### Add cap adapters

If you need them (vintage), add the cap adapters to your switches.

### Add the key caps

Assemble the key caps onto the switches or cap adapters. If needed, don't forget to insert the stabilizer adapters into the relevant key caps before you press fit them onto the switches and stabilizers.

Apply brushed metal stickers to the console keys. I find that holding the stickers with an Exacto knife is a good way to get the alignment precisely right. Take you time for this, as misalignments tend to be very visible with the keys so close to one another.

Your keyboard is now assembled. Let's mount it into the computer.

### Removing the old keyboard

Opening the Atari 1200 is easy. Remove all the screws on the bottom of the computer, then hold the case together as you carefully put it back upside up. Carefully lift the top of the case to the left, making sure not to pull on the cables to the front-left. Carefully unplug the connectors for the LED board and the keyboard.

Opening the case

Remove the four screws holding the keyboard to the top of the case, then remove the keyboard.

Removing the old keyboard
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

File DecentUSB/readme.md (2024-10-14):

# DecentUSB Host - a USB / Bluetooth / Wifi host for Atari 8-bit computers

The DecentUSB Host board installed in an Atari 800XL computer

## Disclaimer

This is very much a prototype.
Both the hardware and the software are work in progress but the proof of concept is here.

## Summary

The DecentUSB Host aims at being a low-cost extension for Atari 8-bit computers that brings USB,
Bluetooh and Wifi capabilities to the platform.
It's open source both in hardware and software to allow the community to easily build new features.

The device is a multi-function interface to keyboards, gamepads or memory devices
in a single board that costs less than $15 to build.
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

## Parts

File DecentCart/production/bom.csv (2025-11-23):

Designator | Footprint | Quantity | Value | LCSC Part #
BT1 | BAT-SMD_BS-CR2032-8 | 1 | Battery_Cell | C70377
C1, C10, C11, C12, C13, C14, C15, C16, C4, C6, C7, C8, C9 | 0402 | 13 | 100nF | C1525
C20, C5 | 0402 | 2 | 4.7uF | C23733
C21, C22 | 0603 | 2 | 4.7uF | C19666
C23, C26, C27, C28 | 0402 | 4 | 10uF | C15525
C24, C25 | 0402 | 2 | 15pF | C1548
D1 | Nexperia_CFP3_SOD-123W | 1 | MBR120VLSFT1G | C8598
D2 | 0805 | 1 | LED | C2297
J1 | TF-SMD_TF-PUSH | 1 | Micro_SD_Card | C393941
J2 | Atari Cartridge Edge Connector | 1 | Conn_02x15_Row_Letter_First
J3 | IDC-SMD_14P-P1.27_HXJN1.27-14P_ATARI_ECI | 1 | Conn_02x07_Row_Letter_First | C42455944
J4 | CONN-SMD_4P-P1.00_SM04B-SRSS-TB-LF-SN | 1 | Conn_01x04_Socket | C160404
J5 | USB-C-SMD_TYPE-C-6PIN-2MD-073 | 1 | USB_C_Receptacle_USB2.0_16P | C2765186
J9 | JST_SH_SM03B-SRSS-TB_1x03-1MP_P1.00mm_Horizontal | 1 | SM03B-SRSS-TB | C160389
L16 | IND-SMD_L2.0-W1.6_AOTA-B201610S3R3-101-T | 1 | 3.3uH | C42411119
Q1 | SOT-23 | 1 | PNP | C8542
Q2 | SOT-23 | 1 | DMG2305UX | C150470
R1 | 0402 | 1 | 470 | C25117
R2, R3 | 0402 | 2 | 10k | C25744
R25 | 0402 | 1 | 33 | C25105
R26, R28 | 0805 | 2 | 27 | C17561
R30, R31, R32 | 0402 | 3 | 1k | C11702
R34 | 0402 | 1 | 220 | C25091
R4, R5, R6, R7, R8, R9 | 0402 | 6 | 47k | C25792
R41, R42 | 0402 | 2 | 5k1 | C25905
SW2, SW3 | Tactile_Switch_Basic_XKB_TS-1187A | 2 | SW_TACTILE | C318884
U1 | rpi_rmc20452t | 1 | Raspberry Pi RM2 | C49451547
U2 | SOIC-8_3.9x4.9mm_P1.27mm | 1 | DS3231MZ | C107410
U3 | QFN-80_L10.0-W10.0-P0.40-TL-EP3.4 | 1 | RP2354B_80QFN | C39843328
U4 | SOT-223-3_TabPin2 | 1 | NCP1117-3.3_SOT223 | C6186
X1 | Crystal_SMD_Abracon_ABM8AIG-4Pin_3.2x2.5mm | 1 | 12MHz | C20625731

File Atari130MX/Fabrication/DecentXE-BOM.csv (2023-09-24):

Designator | Footprint | Quantity | Value | LCSC Part # | Fitted
D1 | 0603 | 1 | LED | C2290 | Y
D100, D101, D102, D103, D104, D105, D106, D107, D108, D109, D110, D111, D112, D113, D114, D115, D116, D117, D118, D119, D120, D121, D122, D123, D124, D125, D126, D127, D128, D2, D68, D69, D70, D71, D72, D73, D74, D75, D76, D77, D78, D79, D80, D81, D82, D83, D84, D85, D86, D87, D88, D89, D90, D91, D92, D93, D94, D95, D96, D97, D98, D99 | D_SOD-123 | 62 | 1N4148W | C81598 | Y
J2 | Molex_200528-0260_1x26-1MP_P1.00mm_Horizontal | 1 | Conn_01x26 | C60248 | Y
R1, R10, R11, R12, R13, R14, R15, R16, R17, R18, R19, R2, R20, R21, R22, R23, R24, R25, R26, R27, R28, R29, R3, R30, R31, R32, R33, R34, R35, R36, R37, R38, R39, R4, R40, R41, R42, R43, R44, R45, R46, R47, R48, R49, R5, R50, R51, R52, R53, R54, R55, R56, R57, R58, R59, R6, R60, R61, R62, R63, R64, R65, R66, R67, R68, R7, R8, R9 | 0603 | 68 | R | C22775 | Y
SW0, SW1, SW2, SW3, SW4, SW5, SW6, SW7, SW8, SW9, SWA1, SWB1, SWBrk1, SWC1, SWComma1, SWD1, SWDash1, SWDel1, SWE1, SWEqual1, SWEsc1, SWF1, SWG1, SWGT1, SWH1, SWI1, SWInv1, SWJ1, SWK1, SWL1, SWLT1, SWM1, SWN1, SWO1, SWP1, SWPeriod1, SWPlus1, SWQ1, SWR1, SWS1, SWSemi1, SWSlash1, SWStar1, SWT1, SWU1, SWV1, SWW1, SWX1, SWY1, SWZ1 | MX-1-00U-LED | 50 | SW_Push_45deg | C193191 | Y
SWBrk2, SWCps1, SWCtl1 | MX-1-25U-LED | 3 | SW_Push_45deg | C193191 | Y
SWCtlCaps1, SWRightSft1 | MX-1-75U-LED | 2 | SW_Push_45deg | C193191 | Y
SWFn1, SWFn2, SWFn3, SWFn4, SWHlp1, SWOption1, SWReset1, SWSelect1, SWStart1 | MX-1-50U-Atari-Fn-LED | 9 | SW_Push_45deg | C193191 | Y
SWLeftSft1 | MX-2-25U-LED | 1 | SW_Push_45deg | C193191 | Y
SWRet1, SWTab1 | MX-1-50U-LED | 2 | SW_Push_45deg | C193191 | Y
SWSpc1 | MX-6-25U-LED | 1 | SW_Push_45deg | C193191 | Y
RV1 | Potentiometer_Bourns_TC33X_Vertical | 1 | R_Potentiometer | C720647 | Y

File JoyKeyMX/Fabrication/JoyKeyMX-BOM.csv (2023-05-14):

Comment | Designator | Footprint | JLCPCB Part # | Quantity
SW_WITHLED | SW7,SW6,SW5,SW4,SW3,SW2,SW1 | MX-1-00U-LED | C193191 | 7
560 | R9,R8 | R_0603_1608Metric | C23204 | 2
100 | R7,R6,R5,R4,R3,R2,R1 | R_0603_1608Metric | C22775 | 7
DPDT | JP1 | SW_CuK_JS202011AQN_DPDT_Angled |  | 1
Conn_01x02 | J4,J3 | PinHeader_1x02_P2.54mm_Vertical |  | 2
Conn_01x09 | J2 | PinHeader_1x09_P2.54mm_Vertical |  | 1
DB9_Female | J1 | DSUB-9_Female_Horizontal_P2.77x2.54mm_EdgePinOffset9.40mm |  | 1
1M | RV1,RV2 | Potentiometer (centered) |  | 2

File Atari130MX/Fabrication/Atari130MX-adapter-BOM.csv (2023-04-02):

Comment | Designator | Footprint | JLCPCB Part # | Quantity
Potentiometer_CUI-PTN06-D02CB20 | RV1 | R_Potentiometer |  | 1
Molex_200528-0260_1x26-1MP_P1.00mm_Horizontal | J8 | Conn_01x26 | C60248 | 1

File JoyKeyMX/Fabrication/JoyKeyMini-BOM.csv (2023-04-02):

Comment | Designator | Footprint | Quantity | Designation | JCLPCB part #
SMD LED mounted on switch footprint | SW1,SW6,SW4,SW5,SW3 | MX-1-00U-LED | 5 | SW_WITHLED | C193191
SMD Resistor | R7,R6,R5,R4,R1 | R_0603_1608Metric_Pad0.98x0.95mm_HandSolder | 5 | 100 | C22775

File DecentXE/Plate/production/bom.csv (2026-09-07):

Designator | Footprint | Quantity | Value | LCSC Part #
SW0, SW1, SW2, SW3, SW4, SW5, SW6, SW7, SW8, SW9, SWA1, SWB1, SWC1, SWCOMMA1, SWD1, SWDASH1, SWE1, SWEQUAL1, SWESC1, SWF1, SWG1, SWGT1, SWH1, SWI1, SWINV1, SWJ1, SWK1, SWL1, SWLT1, SWM1, SWN1, SWO1, SWP1, SWPERIOD1, SWPLUS1, SWQ1, SWR1, SWS1, SWSEMI1, SWSLASH1, SWSTAR1, SWT1, SWU1, SWV1, SWW1, SWX1, SWY1, SWZ1 | MX-1-00U-Hole | 48 | SW_Push_45deg
SWBRK2, SWCTL1 | MX-1-25U-Hole | 2 | SW_Push_45deg
SWCTLCAPS1, SWRIGHTSFT1 | MX-1-75U-Hole | 2 | SW_Push_45deg
SWDEL2 | MX-2-00U-Hole | 1 | SWITCH
SWHLP1, SWOPTION1, SWRESET1, SWSELECT1, SWSTART1 | Choc-1-50U-Atari-Fn-Hole | 5 | SW_Push_45deg | C193191
SWLEFTSFT1 | MX-2-25U-Hole | 1 | SW_Push_45deg
SWRET2 | MX-ISO-RETURN-Hole | 1 | SWITCH
SWSPC1 | MX-6-25U-Hole | 1 | SW_Push_45deg
SWTAB1 | MX-1-50U-Hole | 1 | SW_Push_45deg

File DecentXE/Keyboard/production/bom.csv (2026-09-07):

Designator | Footprint | Quantity | Value | LCSC Part #
D1 | 0603 | 1 | LED | C2286
J2 | Molex_200528-0260_1x26-1MP_P1.00mm_Horizontal | 1 | Conn_01x26 | C2914085
SW0, SW1, SW2, SW3, SW4, SW5, SW6, SW7, SW8, SW9, SWA1, SWB1, SWC1, SWCOMMA1, SWD1, SWDASH1, SWE1, SWEQUAL1, SWESC1, SWF1, SWG1, SWGT1, SWH1, SWI1, SWINV1, SWJ1, SWK1, SWL1, SWLT1, SWM1, SWN1, SWO1, SWP1, SWPERIOD1, SWPLUS1, SWQ1, SWR1, SWS1, SWSEMI1, SWSLASH1, SWSTAR1, SWT1, SWU1, SWV1, SWW1, SWX1, SWY1, SWZ1 | MX-1-00U-LED | 48 | SW_Push_45deg | C193191
SWBRK1, SWCTL1 | MX-1-25U-LED | 2 | SW_Push_45deg | C193191
SWCPS1, SWRIGHTSFT1 | MX-1-75U-LED | 2 | SW_Push_45deg | C193191
SWDEL1 | MX-2-00U-LED | 1 | SW_Push_45deg | C193191
SWHLP1, SWOPTION1, SWRESET1, SWSELECT1, SWSTART1 | Choc-1-50U-Atari-Fn-LED | 5 | SW_Push_45deg | C193191
SWLEFTSFT1 | MX-2-25U-LED | 1 | SW_Push_45deg | C193191
SWRET1 | MX-ISO-RETURN | 1 | SW_Push_45deg | C193191
SWSPC1 | MX-6-25U-LED | 1 | SW_Push_45deg | C193191
SWTAB1 | MX-1-50U-LED | 1 | SW_Push_45deg | C193191

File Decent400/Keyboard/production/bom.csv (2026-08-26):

Designator | Footprint | Quantity | Value | LCSC Part #
D1, D10, D11, D12, D13, D14, D15, D16, D17, D18, D19, D2, D20, D21, D22, D23, D24, D25, D26, D27, D28, D29, D3, D30, D31, D32, D33, D34, D35, D36, D37, D38, D39, D4, D40, D41, D42, D43, D44, D45, D46, D47, D48, D49, D5, D50, D51, D52, D53, D54, D55, D56, D6, D7, D8, D9 | D_SOD-123 | 56 | 1N4148W | C81598
R1, R10, R11, R12, R13, R14, R15, R16, R17, R18, R19, R2, R20, R21, R22, R23, R24, R25, R26, R27, R28, R29, R30, R31, R32, R33, R34, R35, R36, R37, R38, R39, R4, R40, R41, R42, R43, R44, R45, R46, R47, R48, R49, R5, R50, R51, R52, R53, R54, R55, R56, R57, R58, R6, R61, R62, R63, R64, R7, R8, R9 | 0402 | 61 | 100 | C25076
RV1 | Potentiometer_Bourns_TC33X_Vertical | 1 | R_Potentiometer | C720647
SW0, SW1, SW2, SW3, SW4, SW5, SW6, SW7, SW8, SW9, SWA1, SWB1, SWBRK1, SWC1, SWCOMMA1, SWCPS1, SWD1, SWDASH1, SWDEL1, SWE1, SWEQUAL1, SWESC1, SWF1, SWG1, SWGT1, SWH1, SWI1, SWINV1, SWJ1, SWK1, SWL1, SWLT1, SWM1, SWN1, SWO1, SWOPTION1, SWP1, SWPERIOD1, SWPLUS1, SWQ1, SWR1, SWRESET1, SWS1, SWSELECT1, SWSEMI1, SWSLASH1, SWSTAR1, SWSTART1, SWT1, SWU1, SWV1, SWW1, SWX1, SWY1, SWZ1 | Choc-1-00U-LED | 55 | SW_LED | C2290
SWCTL1, SWTAB1 | Choc-1-50U-LED | 2 | SW_LED | C2290
SWLEFTSFT1 | Choc-2-00U-LED | 1 | SW_LED | C2290
SWRET1, SWRIGHTSFT1 | Choc-1-25U-LED | 2 | SW_LED | C2290
SWSPC1 | Choc-6-25U-LED | 1 | SW_LED | C2290

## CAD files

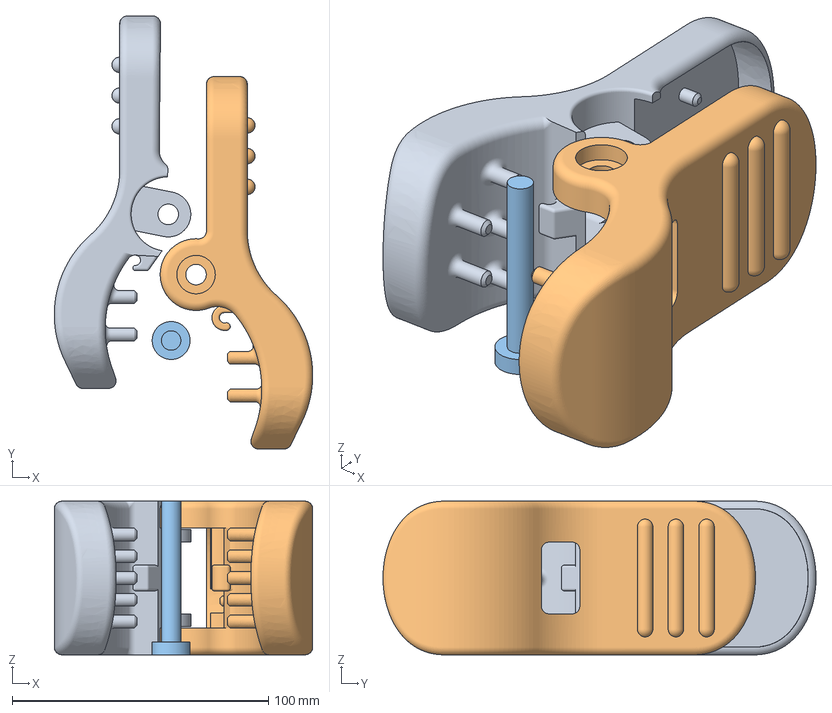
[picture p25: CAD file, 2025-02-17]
misc-models/Cosplay/Arrietty's clip - main.3mf
100.9 x 169.0 x 60.0 mm
Arrietty's clip-Left.stl
Arrietty's clip-Right.stl
Arrietty's clip-Pin.stl

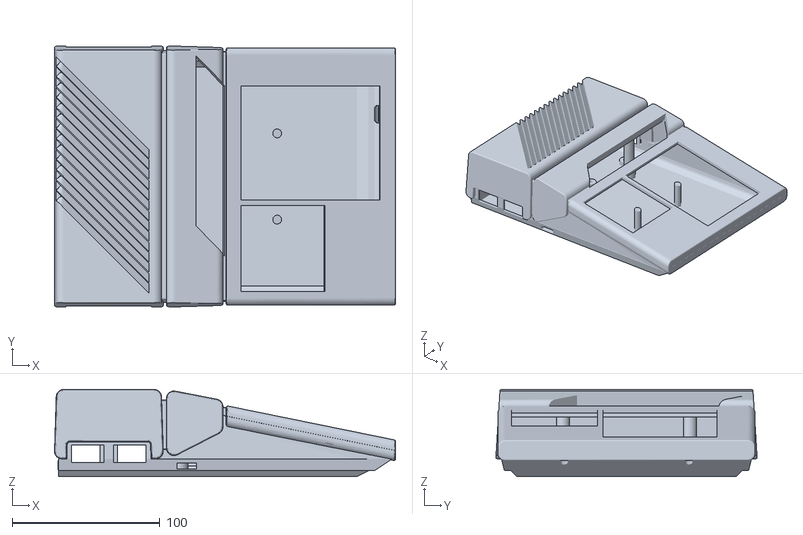
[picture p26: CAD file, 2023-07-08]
SidecarXE85/Case/SidecarXE85-case-Full.stl
231.0 x 177.0 x 59.0

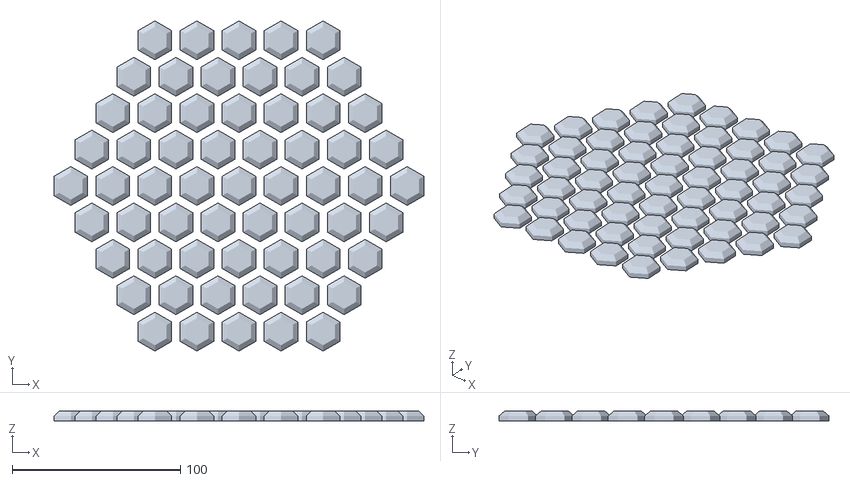
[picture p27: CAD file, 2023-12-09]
misc-models/HexLattice/Printed/WearableHexLattice-Full.stl
220.0 x 196.3 x 6.00

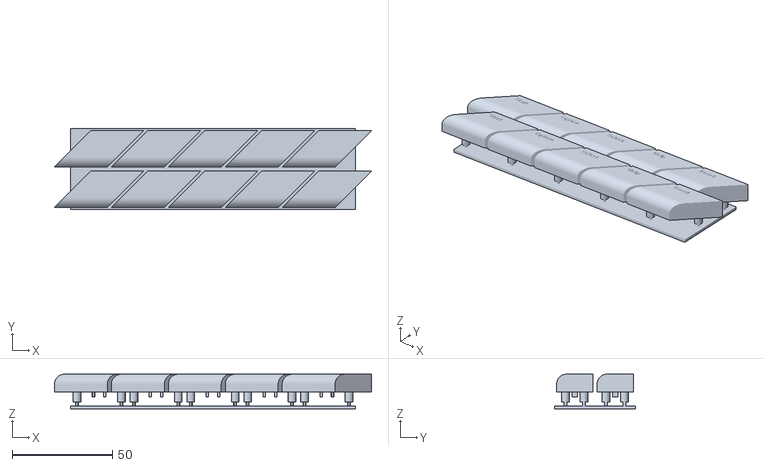
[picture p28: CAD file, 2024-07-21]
Atari130MX/Caps/fn-console-set-choc-x2.stl
158.2 x 40.3 x 17.3

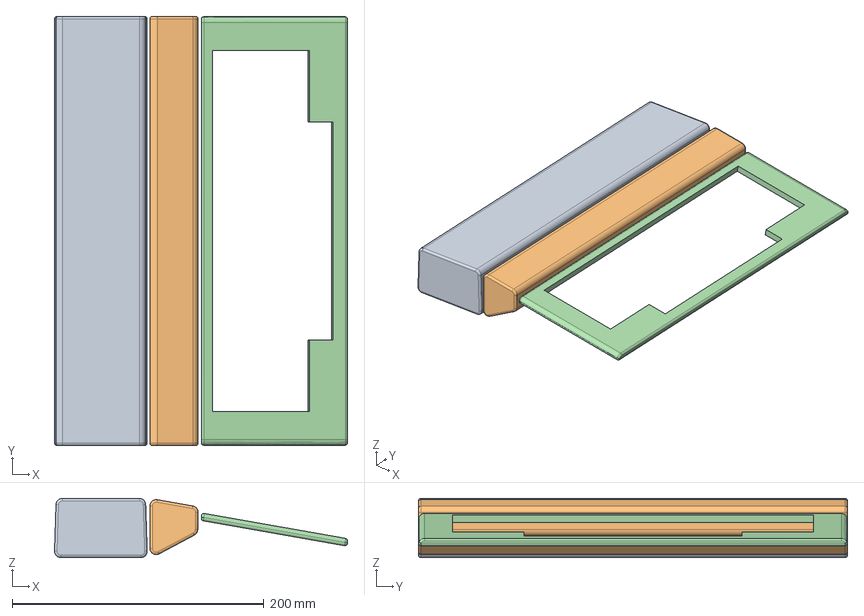
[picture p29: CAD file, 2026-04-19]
Atari130MX/Case/DecentXE-case.FCStd
232.8 x 341.0 x 47.0 mm
Body back
Fillet001 (Solid)

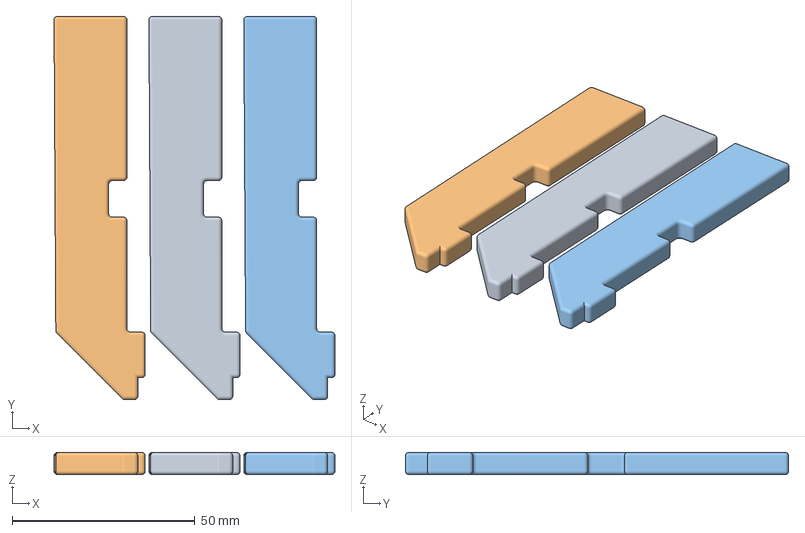
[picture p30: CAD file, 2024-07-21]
Atari130MX/Stabilizers/HeightPadding.3mf
77.0 x 105.0 x 6.10 mm
HeightPadding.stl x 3

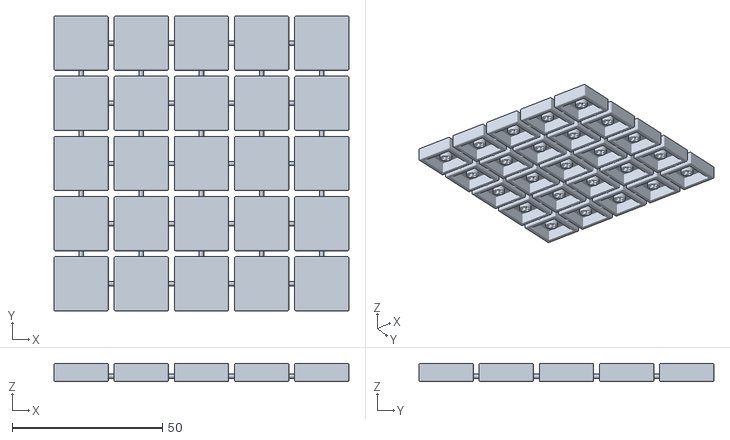
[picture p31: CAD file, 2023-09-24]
Atari130MX/Stems/mx-to-xl-console-set-25.stl
98.1 x 98.1 x 6.13

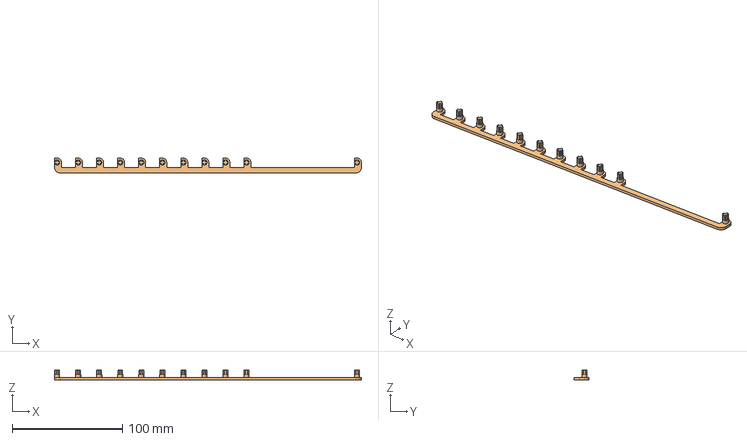
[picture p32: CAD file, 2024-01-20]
Decent1200/Adapters/ConsoleKeyAdapter.FCStd
277.9 x 13.5 x 8.90 mm
ConsoleKeyAdapterBody
Connect

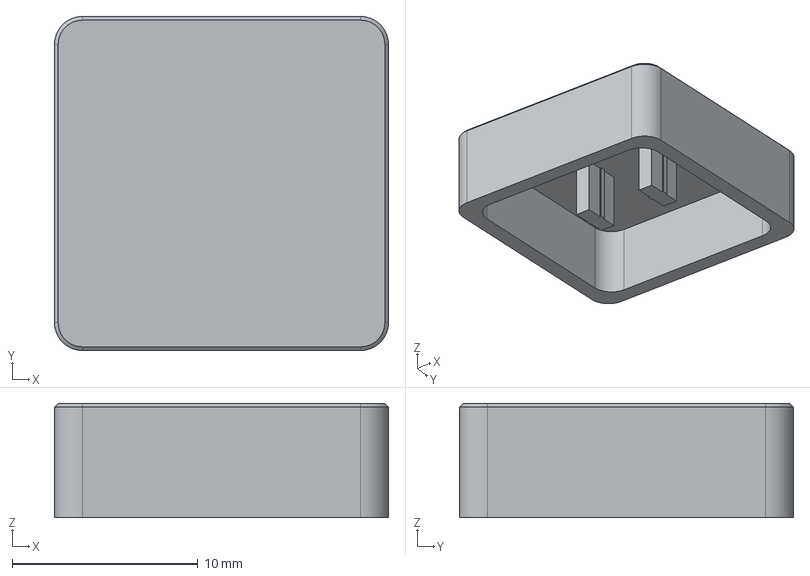
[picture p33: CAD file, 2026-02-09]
Decent1200/Caps/Decent1200-console-choc.step
18.0 x 18.0 x 6.15 mm

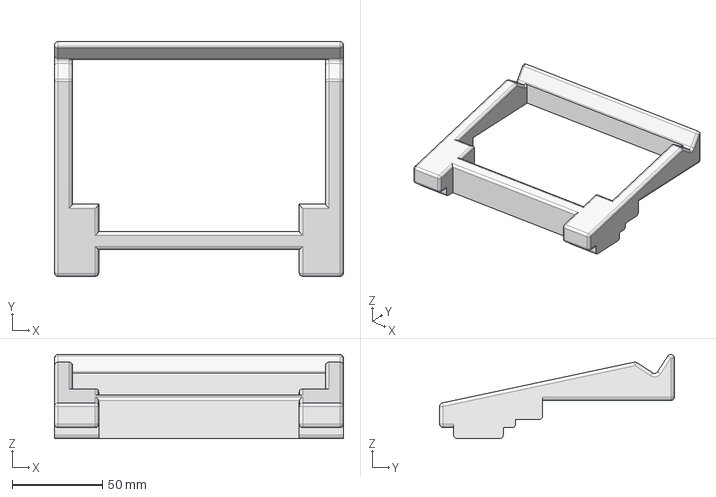
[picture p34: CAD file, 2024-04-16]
Decent1200/PrintedParts/KeyboardMiddleSupport.FCStd
160.0 x 130.0 x 46.5 mm

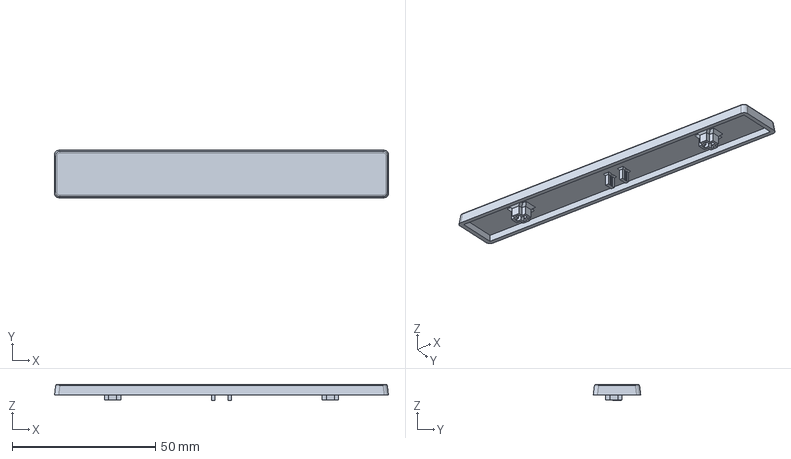
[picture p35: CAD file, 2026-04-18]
Decent400/Caps/SpaceBar.FCStd
116.6 x 16.6 x 5.60 mm

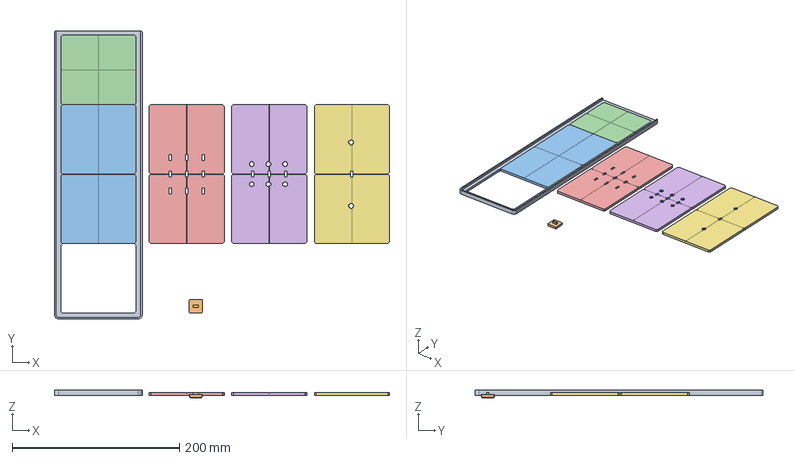
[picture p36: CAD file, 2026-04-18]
Decent400/Misc/Decent400CapPrintRig.FCStd
400.8 x 344.5 x 9.00 mm
Centering device for mini plate
Test cap
Center Fixture
SingleFixture
1U fixture plate
Wide key fixture plate
Space bar fixture plate

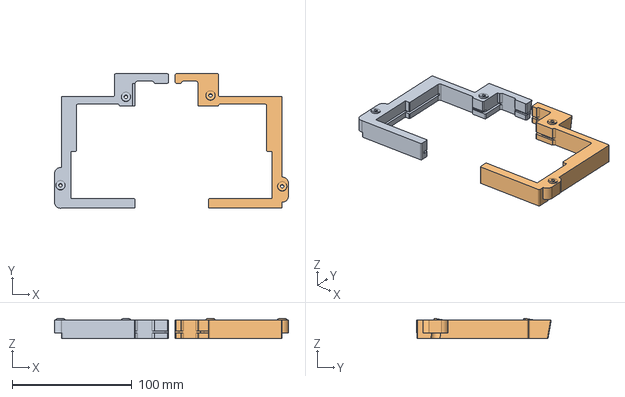
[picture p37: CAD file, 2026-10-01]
Decent800/Misc/Decent800 brackets rev 2.FCStd
195.8 x 112.6 x 17.0 mm
Left
Right

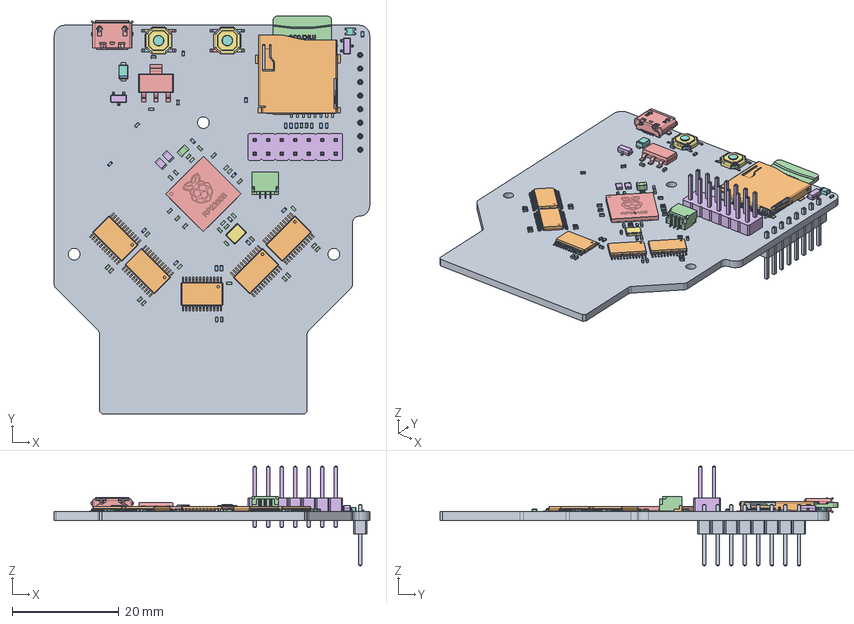
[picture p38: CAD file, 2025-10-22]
DecentCart/3DModels/DecentCart2350Board.FCStd
59.3 x 74.7 x 18.7 mm
Pcb_9dbe
U6_TSSOP_24_44x78mm_P065mm_249428eb97b7 x 5
R30_R_0402_1005Metric_56d1e8ac7ec3 x 19
C33_C_0402_1005Metric_439f5c97a156 x 38
U3_RP2350B_5bf34b71a8d2
R28_R_0805_2012Metric_252277e7415b x 2
TS-1187A v2 x 2
TS-1187A v003 x 2
TS-1187A v004 x 2
TS-1187A v005 x 2
TS-1187A v006 x 2
TS-1187A v007 x 2
TS-1187A v008 x 2
TS-1187A v009 x 2
TS-1187A v010 x 2
TS-1187A v011 x 2
Contact009
Contact008
Contact007
Contact006
Contact005
Contact004
Contact003
Contact002
frame002
cover001
spring
cont002
cont003
cont005
cont006
cont007
cont008
cont001
cont004
microSD001
microSD002
microSD003
microSD004
microSD005
microSD006
microSD007
microSD008
DATA2
DATA003
DATA004
DATA005
DATA006
DATA3
DATA008
DATA009
DATA010
DATA011
DATA012
DATA013
DATA014
CMD
CMD001
CMD002
VDD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

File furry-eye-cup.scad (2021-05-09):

$fa = 1;
$fs = 0.2;

eye = "right"; // [right, left]
eye_outer_width = 90;
eye_outer_height = 80;
cup_depth_left = 19;
cup_depth_right = 16;
pupil_width = 54;
pupil_height = 58;
pupil_x_offset = 2.5;
pupil_y_offset = 2;
wall_thickness = 3.5;
floor_thickness = 2;
boudin = 2;
magnet_diameter = 9;
magnet_thickness = 2.5;
magnet_depth_offset = -9;

cup_total_height = cup_depth_left + wall_thickness;

scale([eye == "right" ? 1 : -1, 1, 1]) {
  difference() {
    union() {
      // Outer eye cup cylinder
      scale([1, eye_outer_height / eye_outer_width, 1]) {
        translate([0, 0, -cup_total_height / 2])
          cylinder(h = cup_total_height, r = eye_outer_width / 2, center = true);
      }
    }

    // Remove slanted plane on top
    angle = atan((cup_depth_left - cup_depth_right) / eye_outer_width);
    translate([0, 0, (cup_depth_left - cup_depth_right) / 2 - 50 - cup_total_height] )
      rotate([0, angle, 0])
        cube([eye_outer_width + 100, eye_outer_height + 100, 100], center = true);

    // Remove pupil space
    translate([pupil_x_offset, pupil_y_offset, 0])
      scale([1, pupil_height / pupil_width, 1]) {
        cylinder(h = 100, r = pupil_width / 2, center = true);
      }

    // Dig cup cavity
    scale([1, eye_outer_height / eye_outer_width, 1]) {
      translate([0, 0, -(cup_total_height + floor_thickness)])
        minkowski() {
          cylinder(h = cup_total_height - floor_thickness, r = eye_outer_width / 2 - wall_thickness - boudin);
          sphere(r = boudin);
        }
    }

    // Remove magnet holes
    translate([-eye_outer_width / 2, 0, magnet_depth_offset])
      rotate([0, 90, 0])
        cylinder(r = magnet_diameter / 2, h = magnet_thickness * 2, center = true);
    translate([eye_outer_width / 2, 0, magnet_depth_offset])
      rotate([0, 90, 0])
        cylinder(r = magnet_diameter / 2, h = magnet_thickness * 2, center = true);
    translate([0, eye_outer_height / 2, magnet_depth_offset])
      rotate([90, 0, 0])
        cylinder(r = magnet_diameter / 2, h = magnet_thickness * 2, center = true);
  }
}

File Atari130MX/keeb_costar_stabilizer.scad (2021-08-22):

$fa = 1;
$fs = 0.2;

rod_diameter = 1.7;
rod_diameter_tolerance = 0.6;
tolerance = 0.1;
rod_entry_point_offset = 0.6;

total_length = 15.3;
base_width = 5.3;
hole_width = 3;
hole_length = 13.65;
inner_length = 6;
from_outer_edge_to_inner = 3.2;
plate_thickness = 1.5;
plate_tolerance = 0.5;
under_plate = 1.5;
height_above_plate = 6;
total_height = height_above_plate + plate_thickness + under_plate;
bar_side_height = 7 - plate_thickness - under_plate;
rod_hole_offset = 6.5;

sqrt2 = sqrt(2);

difference() {
  translate([0, 0, total_height / 2 - plate_thickness - under_plate])
    union() {
      cube([hole_width - tolerance, total_length, total_height], center = true);

      translate([0, 0, (total_height - height_above_plate) / 2])
          cube([base_width, total_length, height_above_plate], center = true);
    }

  translate([0, (inner_length - total_length) / 2 + from_outer_edge_to_inner, height_above_plate / 2 + 0.99])
    cube([base_width * 2, inner_length, height_above_plate + 2], center = true);
  translate([0, -hole_length * .852, 5])
    rotate([77, 0, 0])
      cube([base_width * 2, 10, 10], center = true);
  translate([0, 5, 5 + bar_side_height])
    cube([base_width * 2, 10, 10], center = true);
  translate([0, -total_length / 2 + tolerance, -(plate_thickness + plate_tolerance) / 2])
    cube([base_width * 2, total_length - hole_length, plate_thickness + plate_tolerance], center = true);
  translate([0, total_length / 2 - tolerance, -(plate_thickness + plate_tolerance) / 2])
    cube([base_width * 2, total_length - hole_length, plate_thickness + plate_tolerance], center = true);
  translate([0, 4.8,-under_plate - plate_thickness])
    cube([base_width * 2, 1.4, (under_plate + plate_thickness) * 2], center = true);
  translate([0, rod_hole_offset, bar_side_height / 2])
    rotate([0, 90, 0])
      cylinder(r = (rod_diameter + rod_diameter_tolerance) / 2, h = base_width * 2, center = true);
  translate([0, total_length / 2 + 1.3, -plate_thickness - plate_tolerance - under_plate / 2])
    rotate([-30, 0, 0])
      cube([base_width * 2, 3, 3], center = true);
  translate([0, total_length / 2 + 4.4, 5])
    rotate([20, 0, 0])
      cube([base_width * 2, 10, 10], center = true);
  translate([0, total_length / 2 + 2, bar_side_height / 2])
    cube([base_width * 2, 7, rod_diameter + rod_diameter_tolerance - rod_entry_point_offset], center = true);
}

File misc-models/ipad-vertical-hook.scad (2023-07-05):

// Some simple hooks to hold a tablet or phone vertically on a surface with rectangular holes
// (c) Bertrand Le Roy under MIT license

$fa = 1;
$fs = 0.2;

// Width of the support hole
hole_width = 9;

// Depth of the support hole
hole_depth = 12.5;

// Back and front holder depth
holder_depth = 5;

// Back and front holder height
holder_height = 23;

// Height of the top part of the hook
top_height = 10;

// Top or bottom gutter
gutter_position = "Bottom"; // [Top, Bottom]

// Gutter depth
gutter_depth = 20;

// Gutter height
gutter_height = 5;

// Top dam depth
top_dam_depth = 24;

// Top dam height
top_dam_extra_height = 8;

// Round the model
rounded = true;

// Rounding radius
rounding = 1;

module round_box(x, y, z, width, depth, height, rounding) {
    translate([x, y, z])
        cube([width - rounding * 2, depth, height], center = true);
}

module gutter(x, y, z, width, depth, dam_radius, rounding) {
    translate([x - width / 2, y, z - rounding])
        rotate([0, 90, 0])
            union() {
                intersection() {
                    translate([0, 0, width / 2])
                        cylinder(r = depth - rounding * 2, h = width - rounding * 2, center = true);
                    cube([depth, depth, width]);
                }
                translate([0, depth - dam_radius - rounding, width / 2])
                    cylinder(r = dam_radius - rounding, h = width - rounding * 2, center = true);
                translate([depth / 2 - rounding, 0, width / 2])
                    cube([depth - rounding * 2, rounding * 2, width - rounding * 2], center = true);
            }
}

module gutter_top(x, y, z, width, depth, dam_radius, dam_extra_height, rounding) {
    rotate([0, 180, 0])
        translate([x - width / 2, y, z - rounding])
            rotate([0, 90, 0])
                difference() {
                    union() {
                        intersection() {
                            translate([0, depth / 2 - dam_radius, width / 2])
                                cylinder(r = depth / 2 + dam_radius - 2 * rounding, h = width - rounding * 2, center = true);
                            translate([0, rounding * 3 - depth, 0])
                                cube([depth, depth * 2, width]);
                        }
                        translate([-dam_extra_height / 2, depth - dam_radius - rounding, width / 2])
                            cube([dam_extra_height * 2 - 7 * rounding, (dam_radius - rounding) * 2, width - rounding * 2], center = true);
                        translate([-dam_extra_height, depth - dam_radius - rounding, width / 2])
                            cylinder(r = dam_radius - rounding, h = width - rounding * 2, center = true);
                    }
                    translate([0, depth / 2 - dam_radius, width / 2])
                        cylinder(r = depth / 2 - dam_radius, h = width - rounding, center = true);
                }
}

module unrounded_hook() {
    union() {
        // Back of the hook
        round_box(
            0, -holder_depth / 2, (top_height - holder_height) / 2,
            hole_width, holder_depth, holder_height + top_height,
            rounding);

        // Top of the hook
        round_box(
            0, hole_depth / 2, top_height / 2,
            hole_width, hole_depth + 2 * holder_depth, top_height,
            rounding);

        // Front of the hook
        round_box(
            0, hole_depth + holder_depth / 2, (top_height - holder_height) / 2,
            hole_width, holder_depth, holder_height + top_height,
            rounding);

        // gutter
        if (gutter_position == "Top") {
            gutter_top(
                0, hole_depth + holder_depth, 0,
                hole_width,
                top_dam_depth + 2 * gutter_height,
                gutter_height,
                top_dam_extra_height,
                rounding);
        }
        else {
            gutter(
                0, hole_depth + holder_depth, 0,
                hole_width, gutter_depth + 2 * gutter_height,
                gutter_height, rounding);
        }
    }
}

if (rounded) {
    minkowski() {
        unrounded_hook();
        sphere(r = rounding);
    }
}
else {
    unrounded_hook();
}

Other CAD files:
DecentCart/Enclosure/DecentCart2350-Front.stl
DecentCart/VertiCart/Enclosure/VertiCart Base Support.FCStd
DecentCaseXE/DecentCaseXE.FCStd
DecenTKL/Caps/ConsoleXE-F11-F12.FCStd
misc-models/furry-eye-cup.scad
Atari130MX/Caps/AtariFnKeyPaintRig.FCStd
Atari130MX/Caps/AtariFnKeyPaintRig.stl
Atari130MX/Caps/f1-4-set-choc.stl
Atari130MX/Caps/fn-console-set-choc.stl
Atari130MX/Stabilizers/ConsoleKeyPlate.stl
Atari130MX/Stems/kailh-choc-to-xe-circle-90-set.stl
Atari130MX/Stems/kailh-choc-to-xe-circle-90.stl
Atari130MX/Stems/kailh-choc-to-xl-alps.stl
Atari130MX/Stems/kailh-choc-to-xl-console.stl
Atari130MX/Stems/kailh-choc-to-xl-cross-set-25.stl
Atari130MX/Stems/kailh-choc-to-xl-cross.stl
Atari130MX/Stems/kailh-choc-to-xl-square.stl
Atari130MX/Stems/keeb-stem-alps.stl
Atari130MX/Stems/keeb-stem-circle.stl
Atari130MX/Stems/keeb-stem-square.stl
Atari130MX/Stems/low-pro-to-mx.stl
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

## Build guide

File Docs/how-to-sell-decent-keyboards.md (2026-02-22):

# How to sell Decent keyboards

Decent keyboards are open source under [a very liberal license](../LICENSE) that allows
for commercial applications. As such, anybody can in principle build, modify and
even sell their own keyboards.

This guide is for small businesses that want to get started selling kits and assembled
Decent keyboards.

## IP and royalties

The open source [license](../LICENSE) under which Decent keyboards are available doesn't require
vendors to share a part of the profit with the authors, in principle.
However, I'd prefer people would adhere to some sort of "don't be a dick" ethos.
A lot of work went into the design of the keyboards, and it seems fair that if
you're going to profit from our work, you would share some of this profit with
us, the authors.

I ([Bertrand Le Roy](https://forums.atariage.com/profile/76850-screamingattheradio/)) created
the general design of the keyboards, in particular the PCBs.

Jesse ([@XL Freak](https://forums.atariage.com/profile/63723-xl-freak/) on AtariAge) designed
all the key caps.

The cost of a keyboard is roughly 1/3 key caps and 2/3 for everything else, so if you're going
to share part of the profit, you should split that share 1/3 - 2/3 between Jesse and I.

Typical royalty rates are 10-15% of the sale price, so if you sell a keyboard for $300,
15% of that would be $45, so I suggest you cut a share of $15 to Jesse and $30 to me.

## What do you need in order to get started?

First, you need a business structure, in accordance with local laws for reselling electronics.

You'll also need a way to get payment from your buyers. I've been using a simple
[Stripe link](https://docs.stripe.com/payment-links), but if you have a full commerce web
site, that's great too.

Of course, you'll need to stock parts and supplies, some of which you can acquire as you
handle orders, some you'll need to have an inventory of, for example because buying in
larger quantities is going to save you money.

Depending on the quantities you order, you may be able to negotiate deals with suppliers.
In most places, businesses can waive the sales tax on the supplies they use to manufacture goods.
Consult your local government to obtain the relevant forms and procedures.
Contact each supplier to ask them to setup your account so taxes are waived.

Finally, some parts are 3D-printed, so you'll need access to a 3D printer, or to have those
parts printed, for example by JLCPCB.

You'll need access to a vinyl cutter to make console key stickers.

### Parts and supplies

1. **PCBs and plates**: the PCBs and plates for each model of Decent keyboard can be ordered
   from JLCPCB or from any PCB manufacturer. Those fabrication houses usually start with
   orders of 5. The PCB for a keyboard can be ordered with all surface-mount parts
   assembled, leaving only the switches to be soldered manually by you.
1. **Cables**: XE and XL models use the same flexible PCB as a cable. Those are relatively
   inexpensive and can also be ordered in batches of at least 5 from JLCPCB. Other models
   use Dupont cables that can easily be ordered from various places (specs by model below).
   Make sure to have enough length (more than 10cm).
1. **Headers**: some keyboards (400, 800 ans 1200XL) need 90 degree angle pin headers.
   those are very easy and inexpensive to source. They can be cut to size.
1. **Stabilizers**: all modern models use one 6.5U stabilizer for the space bar and 3 to 4
   2U stabilizers. All stabilizers are Durock v2 types (although there are other brands).
1. **Key caps**: there are very few companies that print custom key caps. We use
   [GoblinTech](https://goblintechkeys.com/). Note that there's typically a long lead
   of a few weeks on those parts.
1. **Printed parts**: some parts are fine to print on a simple consumer-level printer
   and some more delicate parts such as key cap adapters, are better done on the kind of
   expensive printer places like JLCPCB have.
1. **Switches**: you should have an inventory of linear, tactile and clicky switches, both
   full-size and low-profile (for console keys), sufficient to build a full keyboard with
   each type (around 57 full-size switches and 5 to 11 low-profile).
1. **Packing material**: you'll need boxes and padding material to ship the keyboards safely.
1. **Solder** and soldering supplies and tools.

## Assembly

There are assembly instructions specific to each keyboard type in the relevant readmes in
this repository:

- [DecentXE](../DecentXE/readme.md)
- [DecentXL](../DecentXL/readme.md)
- [Decent1200](../Decent1200/readme.md)
- [Decent400](../Decent400/readme.md)
- [Decent800](../Decent800/readme.md)

Essentially, for all keyboards, the steps are:

1. Mount stabilizers.
1. If there's a flexible PCB for the cable, connect it now. If it's an angled pin header
   connector, it's necessary to solder it now because the connector may be inaccessible
   once the plate and switches have been assembled.
1. Insert switches in the plate, verify pins are properly aligned.
1. Carefully align the pins of the switches and bring the plate and PCB together.
1. Solder the switches.
1. If there are console keys, solder the low-profile switches for them.
1. Add the key caps.
1. Add the console keys if there are any. Apply stickers if relevant.
1. Test the keyboard.
   Keyboards can be tested in a real Atari machine, or you can build and use a
   [Decent Keyboard Tester](../misc-models/KeyboardTester/).

### Troubleshooting

#### Some keys don't work

First check the proper connection of the cable.

If a single key fails to actuate, it's usually a missing or defective solder joint,
or it can be a defective switch. Both issues are easy to diagnose and deal with by
inspecting the board, flowing or reflowing the solder points, or by desoldering and
replacing the switch.

More rarely, a whole set of adjacent switches can fail. That means an entire row or
column is failing. That's a little trickier but still fairly easy to fix.
One common cause could be a broken trace, which can be patched by soldering a cable
replacing the broken trace.

All keyboards have a representation of the internal matrix
for easy reference and diagnostics, as well as a set of extra vias that can be used with a multimeter to probe rows and columns.

When testing with a multimeter, keep in mind that we have anti-ghosting diodes behind
the switches from columns to rows, so a continuity test will work when testing column
traces, but you should use diode testing mode for row traces.

First determine what row or column is defective, then solder a wire between the
relevant labelled via on the diagnostics port and one of the vias on the correct side
of the switches for that row or column.

Fixing rows can be a little more involved because the anti-ghosting diodes are on the
inaccessible side of the PCB, so you can't solder after the diodes.
That means you have to bypass the diodes for that row and establish contact between
all switches on the row. Consult the schematic if in doubt.

#### Stabilized keys don't correctly come back all the way up or at all

Stabilizers can be tricky to get right: their proper function relies on near perfect
alignment and distances between three stems under the key cap.

Because stabilizers are attached to the PCB before the switches are soldered and are
inaccessible thereafter, it can seem discouraging to discover a stabilizer is
misbehaving. However, there are simple steps that are usually enough to make them work.

First, try to loosen the screws of the stabilizers, to give the stabs some freedom
to move into better alignment.

If that doesn't work, you can reflow the switches while operating the keys, which
should deal with misalignment of the switch.

#### F#@#$%, I forgot to assemble the stabilizers before I soldered the switches

Yeah, that sucks. Desoldering 57 switches is dangerous: the risk of damaging a pad
is pretty high, especially on modern PCBs. You may have to discard that PCB once you're
done, but at least the switches should be reusable.

#### I'm still stuck

You can always contact me or someone else with expertise on Decent keyboards through the
AtariAge forums.

## BOM

| Part | XE | XL | 1200 | 400 | 800 |
|---|----|----|---|-----|-----|
|PCB | 1| 1| 1| 1| 1|
|Plate | 1| 1| 1| 1| 1|
|Flex cable | 1| 1| | | |
|5P F/F Dupont | | | 1| | |
|9P F/F Dupont | | | | | 2|
|10P F/F Dupont | | | 1| | |
|10P M/F Dupont | | | | 1| |
|12P M/F Dupont | | | | 1| |
|2P F Dupont, other end tinned | | | | 1| 1|
|15P angled pin headers | | | 1| | |
|20P angled pin headers | | | | | 1|
|24P angled pin headers | | | | 1| |
|6.5U Durock v2 stabilizer | 1| 1| 1| 1| 1|
|2U Durock v2 stabilizer | 3| 3| 4| 1| 3|
|MX-style switches |  57|  57| 56| 62| 57|
|Kailh Choc v1 switches | 5| 5| 11| | |
|Key caps |  57|  57| 56| 62| 57|
|Printed console keys (1) |Opt5| 5| 11| | |
|Console key stickers (1) |Opt5| 5| 11| | |
|Cap adapters (1) |  10| | | | |
|Printed padding | 2| | | | |
|Printed brackets | | 2| 2| | 4|
|Printed support block | 1| | 1| | |
|LED diffuser (2) | 1| 2| | 1| |

(1) Two sets of key cap adapters for the square and round types of XE 
key caps so people have spares. Ask customer to specify which type
of adapter (square or circle) they need for their vintage console keys.
Provide printed console keys only if the customer asks for them.

(2) The new power LED is small and bright, and should ideally be diffused.
A printed translucent part of the right diameter can fulfill this role.
The diameter on 600XL and 800XL is different, so you should include both parts.

## Component and supplies sources

The following are suggestions for sourcing parts and supplies.
If you can find better ones, for example local suppliers, fantastic!

- [Shipping box](https://www.amazon.com/BOX-USA-BMFL15112-White-Pack/dp/B01D9T473E)
- [Packing material](https://www.amazon.com/dp/B09Y693NJB)
- Anti-static bubble wrap: You can usually cut and re-use the wrap that the fabrication
  house sends the PCBs in.
- [PCBs, plates and flex PCBs](https://cart.jlcpcb.com/quote?orderType=1)
- [Dupont cables](https://www.aliexpress.us/item/3256805354208051.html)
- [Pin headers](https://www.aliexpress.us/item/3256807383526945.html)
- [Stabilizers](https://novelkeys.com/collections/supplies/products/nk-stabilizers) or
  [Durock v3](https://www.aliexpress.us/item/3256801446358046.html)
- [Kailh Box switches](https://novelkeys.com/collections/switches/products/kailh-box-switches)
- [Kailh Choc v1 switches](https://chosfox.com/collections/kailh-low-profile-switch-pg1350/products/kailh-chocs)
- [Key caps](https://goblintechkeys.com/collections/65-keycaps)
- [Printed console keys and key adapters](https://jlc3dp.com/3d-printing-quote)
- [Cuttable XL brushed metal vinyl](https://www.amazon.com/Stainless-Countertops-Waterproof-Backsplash-Appliances/dp/B09TZWGTFB)
- [Cuttable XE grey vinyl](https://www.amazon.com/dp/B0CQYQGDNH)

## Design files

### DecentXE

- [PCB Gerber](../DecentXE/Keyboard/production/Decent_XE_Keyboard_-_Modern_16.1.zip),
  [BOM](../DecentXE/Keyboard/production/Decent_XE_Keyboard_-_Modern_16.1-bom.csv) and
  [positions](../DecentXE/Keyboard/production/Decent_XE_Keyboard_-_Modern_16.1-positions.csv)
- [Plate](../DecentXE/Plate/production/Decent_XE_Keyboard_Plate_-_Modern_16m.zip) should
  be made in aluminium with the default 1.6mm thickness and a black silkscreen.
- [Flex cable](../DecentXL/DecentXL-Cable/production/DecentXL_Flexible_Cable_2.zip): tell the fabrication
  house to apply stiffeners to the two rectangles in the front silkscreen layer.
- [Falcon caps](../DecentXE/Caps/Atari%20XE%20-%20Falcon.svg) and
  [white caps](../DecentXE/Caps/Atari%20XE%20-%20White.svg)
- [Console keys](../DecentXE/Caps/ConsoleKeySet-x2.stl) can be printed in grey or clear resin covered with stickers to make shine-through console keys.
- [Console key stickers](../DecentXE/Caps/ConsoleKeyStickers.svg)
- [Circle key adapters](../DecentXE/Stems/kailh-choc-to-xe-circle-set.stl) and
  [square key adapters](../DecentXE/Stems/kailh-choc-to-xe-square-set.stl)
- [Printed padding](../DecentXE/Stabilizers/HeightPadding.stl)
- [Printed support bracket](../DecentXE/Misc/XE-mid-keeb-support.stl)
- [LED diffuser](../DecentXE/Misc/LED-red-lens.stl)

### DecentXL

- [PCB Gerber](../DecentXL/DecentXL-keyboard/production/DecentXL_keyboard_-_Modern_4.2m.zip),
  [BOM](../DecentXL/DecentXL-keyboard/production/DecentXL_keyboard_-_Modern_4.2m-bom.csv) and
  [positions](../DecentXL/DecentXL-keyboard/production/DecentXL_keyboard_-_Modern_4.2m-positions.csv)
- [Plate](../DecentXL/DecentXL-plate/production/DecentXL_plate_4m.zip) should
  be made in aluminium with the default 1.6mm thickness and a black silkscreen.
- [Flex cable](../DecentXL/DecentXL-Cable/production/DecentXL_Flexible_Cable_2.zip): tell the fabrication
  house to apply stiffeners to the two rectangles in the front silkscreen layer.
- [Caps](../DecentXL/Caps/Atari%20XL.svg)
- [Console keys](../DecentXL/Caps/Console-set-XL-Choc-x10.stl) can be printed in clear resin
  and covered with stickers to make shine-through console keys.
- [Console key stickers](../Decent1200/PrintedParts/ConsoleKeyStickers.svg)
- [600XL LED diffuser](../DecentXL/Misc/LedDiffuser600XL.stl) and
  [800XL LED diffuser](../DecentXL/Misc/LedDiffuser800XL.stl)
- [Left](../DecentXL/Brackets/DecentXL-Left-Bracket.stl) and [right brackets](../DecentXL/Brackets/DecentXL-Right-Bracket.stl)

## Decent1200

- [PCB Gerber](../Decent1200/Keyboard/production/Decent1200_modern_keyboard_5m.zip),
  [BOM](../Decent1200/Keyboard/production/Decent1200_modern_keyboard_5m-bom.csv) and
  [positions](../Decent1200/Keyboard/production/Decent1200_modern_keyboard_5m-positions.csv)
- [Plate](../Decent1200/Plate/production/Decent1200_plate_4m.zip) should
  be made in aluminium with the default 1.6mm thickness and a black silkscreen.
- [Caps](../Decent1200/Caps/Atari%201200XL.svg)
- [Console keys](../Decent1200/Caps/Decent1200-console-choc-x10.stl) can be printed
  in clear resin and covered with stickers to make shine-through console keys.
  **WARNING** the 1200 console keys are different from the XL console keys: they are
  deeper.
- [Console key stickers](../Decent1200/PrintedParts/ConsoleKeyStickers.svg)
- [Printed support](../Decent1200/PrintedParts/KeyboardMiddleSupport1200.stl)
- [Printed brackets](../Decent1200/PrintedParts/Decent1200Brackets.stl)

## Decent400

- [PCB Gerber](../Decent400/Keyboard/production/Decent400_keyboard_2i.zip),
  [BOM](../Decent400/Keyboard/production/Decent400_keyboard_2i-bom.csv) and
  [positions](../Decent400/Keyboard/production/Decent400_keyboard_2i-positions.csv)
- [Plate](../Decent400/Plate/production/Decent400_Plate_2i.zip) should
  be made in aluminium with the default 1.6mm thickness and a black silkscreen.
- [Caps](../Decent400/Caps/Decent_Atari_400_REAL400_Black.svg)
- [LED diffuser](../Decent400/Misc/Decent400LedDiffuser.stl)

## Decent800

- [PCB Gerber](../Decent800/Keyboard/production/Decent800_keyboard_3M.zip),
  [BOM](../Decent800/Keyboard/production/Decent800_Rev_3M-bom.csv) and
  [positions](../Decent800/Keyboard/production/Decent800_Rev_3M-positions.csv)
- [Plate](../Decent800/Plate/production/Decent800_Rev3M.zip) should
  be made in aluminium with the default 1.6mm thickness and a black silkscreen.
- [Caps](../Decent800/Caps/Decent_Atari_800.svg)
- Printed brackets [1](../Decent800/Misc/Decent800%20brackets-ScrewColumn%201.stl),
  [2](../Decent800/Misc/Decent800%20brackets-ScrewColumn%202.stl)
  [3](../Decent800/Misc/Decent800%20brackets-ScrewColumn%203.stl) and
  [4](../Decent800/Misc/Decent800%20brackets-ScrewColumn%204.stl)

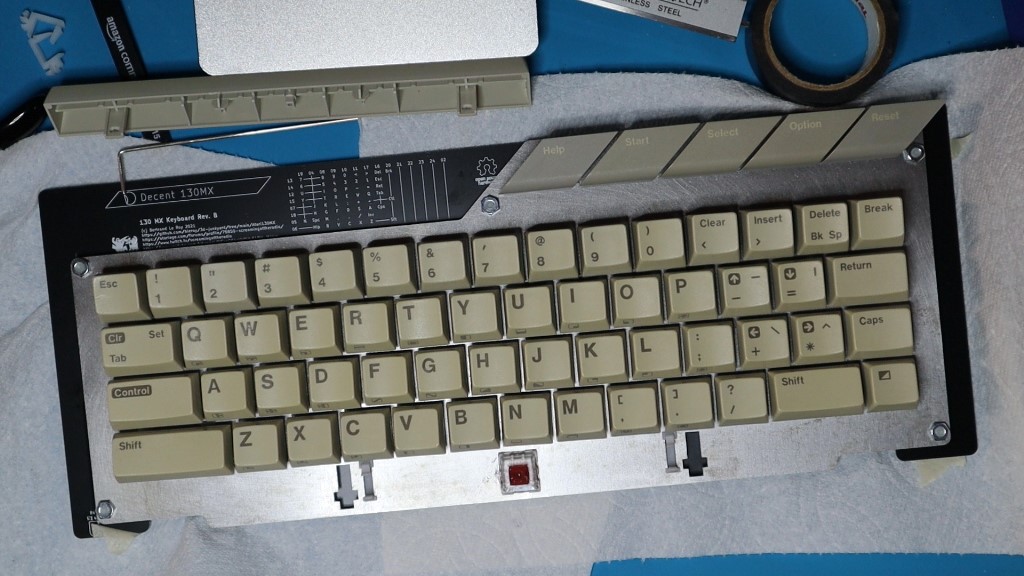
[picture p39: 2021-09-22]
Atari130MX/Media/Atari130MX-assembly.jpg

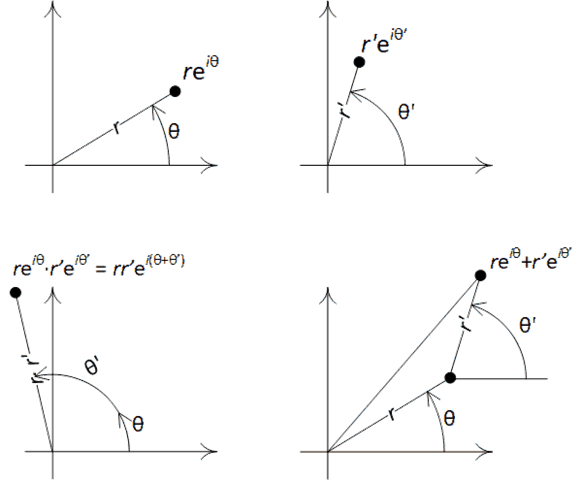
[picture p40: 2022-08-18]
FFT/assets/AngularComplexOperations.png

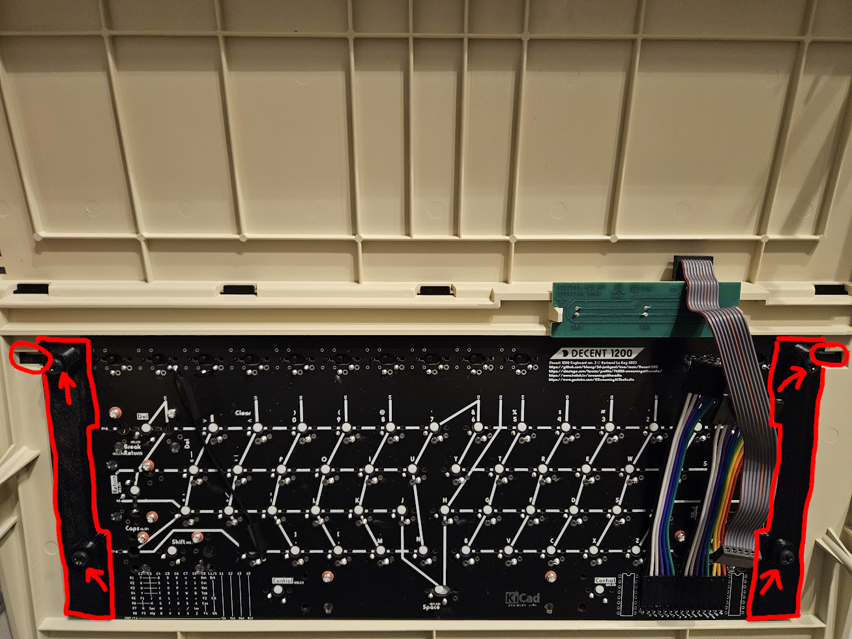
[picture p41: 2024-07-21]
Decent1200/Media/assembly-3.png

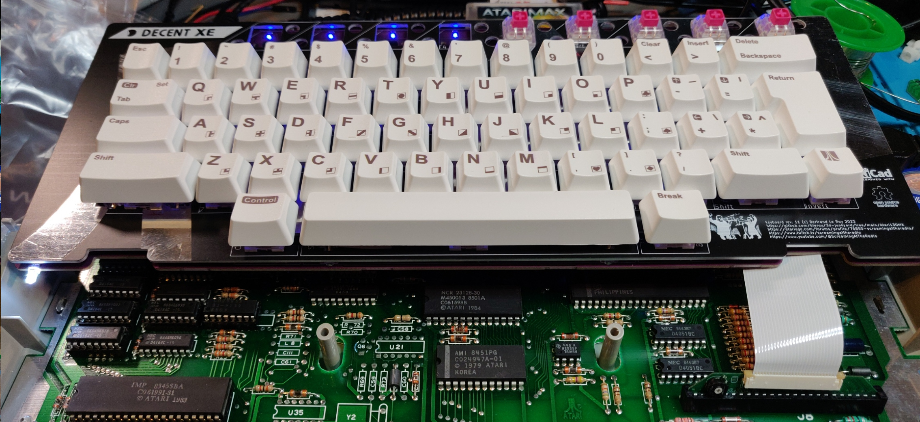
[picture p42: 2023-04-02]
Atari130MX/Media/ModernKeyboardAssembly.jpg

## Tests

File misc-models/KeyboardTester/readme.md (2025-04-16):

# Decent Retro Keyboard Tester

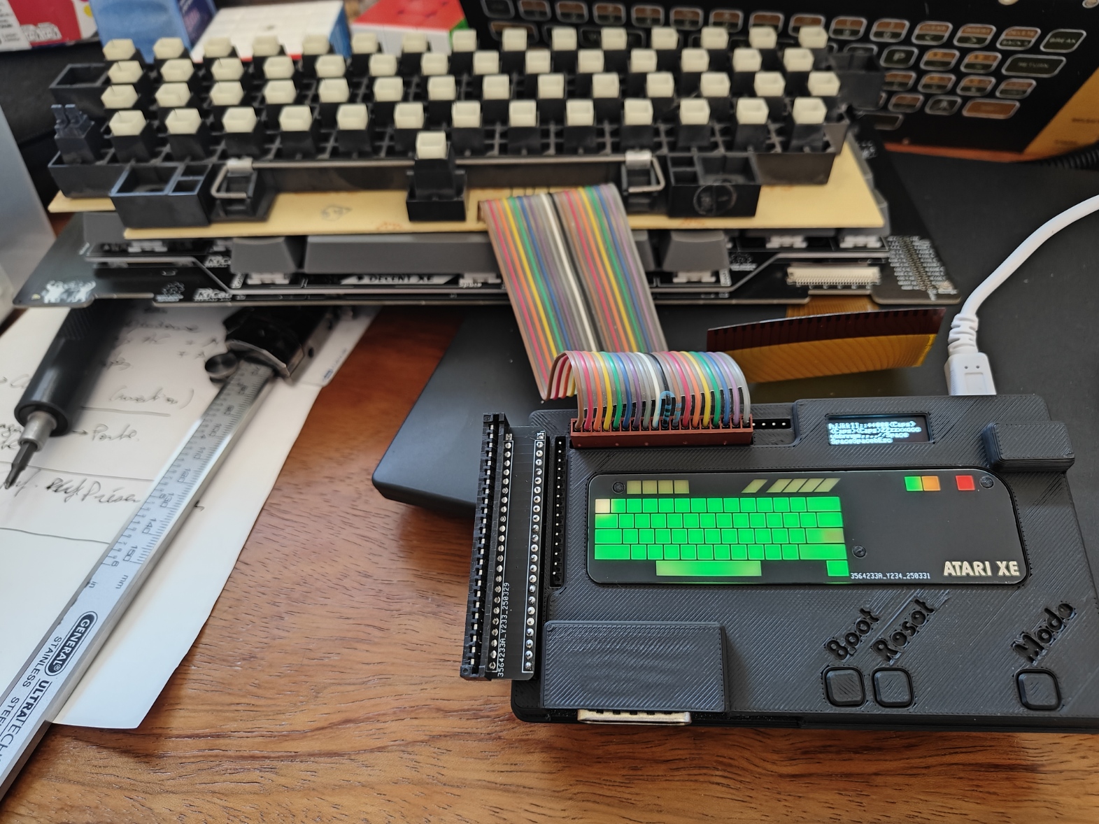
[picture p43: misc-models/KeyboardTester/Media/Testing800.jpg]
The Decent Retro Keyboard Tester testing an Atari 800 keyboard


The Decent Retro Keyboard Tester is an open source board designed around the RP2040 chip
to test vintage computer keyboards.
I built it to test my own modern keyboard replacements for Atari 8-bit computers, but
the architecture is generic enough that drivers for other computers should be very easy
to build.

The tester currently supports the following keyboards:

- Atari 400
- Atari 800
- Atari XE (except XEGS, coming soon)
- Atari 600XL and 800XL
- Atari 1200XL
- USB keyboards

## How to use the tester

Connect the tester to a power source (either the micro-USB at the back or the barrel jack,
center-positive with 5V).

Press the mode button repeatedly until you reach the mode for the keyboard to test.

Connect the keyboard to test.

Start pressing each key on the keyboard. The corresponding LED on the tester should turn
from orange to green. Continue doing that until all the lights are green.

If a light remains orange after the corresponding key has been pressed, there is an issue
with that key. Oftentimes, a whole pattern of keys will fail, not just one.
That usually means that a whole line or column of the keyboard matrix is failing.
Consult a map of the keyboard's matrix and probe the corresponding lines on the PCB or on the
keyboard cable.

## How to build one

### The board

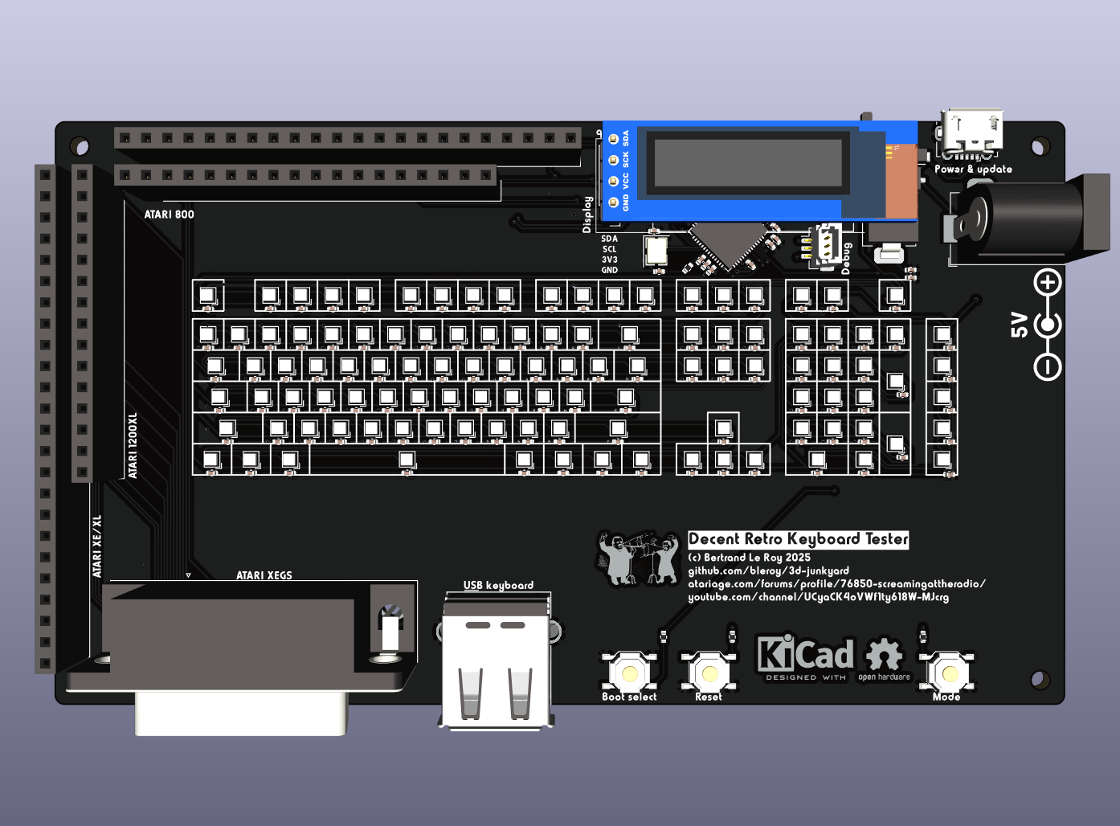
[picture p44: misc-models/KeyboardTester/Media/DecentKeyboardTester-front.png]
The Front of the board


The assembled board can be ordered from JLCPCB or PCBWay using the following files:

- [Gerber](./production/Decent_Retro_Keyboard_Tester_2.zip)
- [BOM](./production/bom.csv)
- [Positions](./production/positions.csv)

You should order the boards assembled, and you'll only have to solder the connectors,
the OLED screen and the barrel jack if you want to power the board without USB.

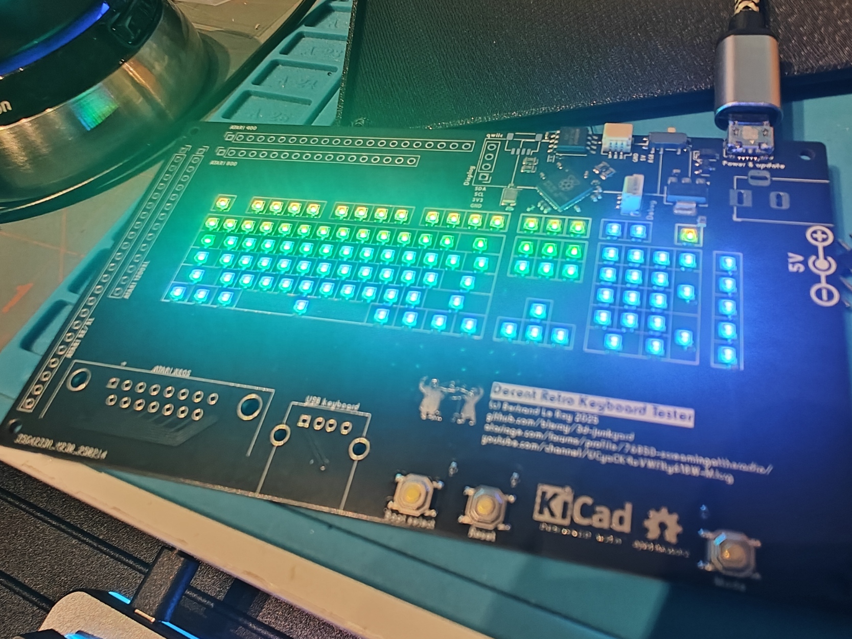
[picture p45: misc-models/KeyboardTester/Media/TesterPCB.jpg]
The Decent Retro Keyboard Tester board


The connectors are:

- 24P 2.54mm male pin headers on the left of the board
- 15P 2.54mm male pin headers immediately to the right of the 24P connector
- 22P 2.54mm female headers on the top of the board
- 18P 2.54mm male pin headers under the 22P one.
- DB15 at the bottom left of the board
- USB-A connector to the right of the DB25 connector

Don't solder the display yet, as it's easier to do once the board is in the top half of the enclosure.

### The enclosure

Print the following parts:

- 1x [Enclosure top](./Enclosure/Decent%20Retro%20Keyboard%20Tester%20Enclosure-Top.stl)
- 1x [Enclosure bottom](./Enclosure/Decent%20Retro%20Keyboard%20Tester%20Enclosure-Bottom.stl)
- 3x [Button](./Enclosure/Decent%20Retro%20Keyboard%20Tester%20Enclosure-Button.stl)
- 1x [Full light tunnel](./Enclosure/Decent%20Retro%20Keyboard%20Tester%20Enclosure-Light%20tunnels.stl)
- 1x [Switch slider](./Enclosure/Decent%20Retro%20Keyboard%20Tester%20Enclosure-Slider.stl)

Depending on the keyboards you want to test:

- 1x [Atari XE light tunnel](./Enclosure/Decent%20Retro%20Keyboard%20Tester%20Enclosure-ATARI-XE-Light%20tunnels.stl)
- 1x [Atari XL light tunnel](./Enclosure/Decent%20Retro%20Keyboard%20Tester%20Enclosure-ATARI-XL-Light%20tunnels.stl)

Add 4 threaded inserts to the top of the enclosure.

With the top of the enclosure upside-down on your workbench, add the three buttons, put the OLED
screen in position, then add the main board on top of that.

Make sure everything is properly aligned and level, then solder the screen to the board.

Add the slider to the little switch at the back of the board.

Put the bottom of the enclosure in place, then secure everything with 4 screws corresponding to the
threaded inserts you chose.

### Adapter boards

The tester has some connectors built-in, but the ultimate goal is to support a wide variety of
keyboards with exotic connectors.
For instance, Atari XE and XL computers use a single-sided 2.54mm 24 pin connector that is very
hard to source outside of scavenging it from a vintage motherboard.

To address this, the board presents 24 GPIOs on a standard pin header connector so one can build
adapter boards that translate that into specific connectors.

Have the adapter boards you need fabricated and assemble the required connectors on them.

At this moment, the only adapter board is for Atari XE and XL computers:

- [Gerber](./adapter-ATARI-XE-XL/production/adapter-ATARI-XE-XL.zip)

  It can be assembled by adding a 24P 2.54mm female header on the bottom of the board and to the right
  and an Atari keyboard connector on top to the left with the contacts on the left.

### Overlays

Each keyboard driver will do its own mapping of the physical keys to the array of LEDs on the tester.
To make things a little nicer to look at, there are overlays that are made with a printed light tunnel
and a small PCB with windows in the mask layer that let the light get diffused over each key
footprint.

There are overlays available for the following keyboards:

- Atari XE - [Gerber](./Overlays/XE-overlay/production/XE-overlay.zip) & [light tunnel](./Overlays/XE-overlay/Decent%20Retro%20Keyboard%20Tester%20Enclosure-ATARI-XE-Light%20tunnels.stl)
- Atari XL - [Gerber](./Overlays/XL-overlay/production/XL-overlay.zip) & [light tunnel](./Overlays/XL-overlay/Decent%20Retro%20Keyboard%20Tester%20Enclosure-ATARI-XL-Light%20tunnels.stl)

### Flashing the firmware

The tester can be programmed through its micro-usb port on the back.
Connect that port to a computer and it will appear as a disk drive.

There's a one-time operation which is to install CircuitPython on the device.
Get [the latest version for the Pi Pico](https://circuitpython.org/board/raspberry_pi_pico/) and
copy the uf2 file to the root of the device's file system.
The device will reboot and show a new file system.

If at a later date you need to upgrade your CircuitPython, you can do so by keeping the Boot
button pressed while you connect the device to your computer. You'll then be able to copy a new
uf2 file.

Copy the contents of the [firmware](./Firmware/) directory from this repository to the root of
the device.

The tester will reboot and should display some text on the OLED display.
If it doesn't, then something went wrong with the installation.
Verify you copied everything.
If there's still an issue, you can try to check what happens on the serial port using [the Pi Pico
tooling for VS Code](https://marketplace.visualstudio.com/items?itemName=raspberry-pi.raspberry-pi-pico).

## This is too complicated, can I just buy one from you?

Yes, you can. [Contact me on the AtariAge forums](https://forums.atariage.com/profile/76850-screamingattheradio/).

## Design

Board schematic

The controller part of the board is just a simple implementation of [the RP2040 reference board](https://datasheets.raspberrypi.com/rp2040/hardware-design-with-rp2040.pdf).

GPIO 0 and 1 are the data lines for the USB-A port in front of the board.

GPIO 2 to 25 are connected to the various keyboard ports and can be programmed to scan the
keyboard to test. Each connector has its first pin (GPIO 2) towards the top-left of the board.

GPIO26 is connected to the mode button.

GPIO27 is the data line for the addressable RGB LEDs. Each key module has a SK6805 addressable
LED and a 100nF capacitor:

A key module

The data out of each LED goes into the data in of the next.
The final data out is exposed on a small 3-pin connector at the back of the board, enabling
the addition of more LEDs.

GPIO28 and 29 are I2C SDA and SCL, connected to the OLED display and to a qwiic expansion port
at the back of the board.

There's also a debug port on the board that can be used with [the Pi debug probe](https://www.raspberrypi.com/documentation/microcontrollers/debug-probe.html).

## Contributions

A great contribution to this project would be new drivers, adapters and overlays for keyboards
not yet supported.

Bug fixes are also greatly appreciated!

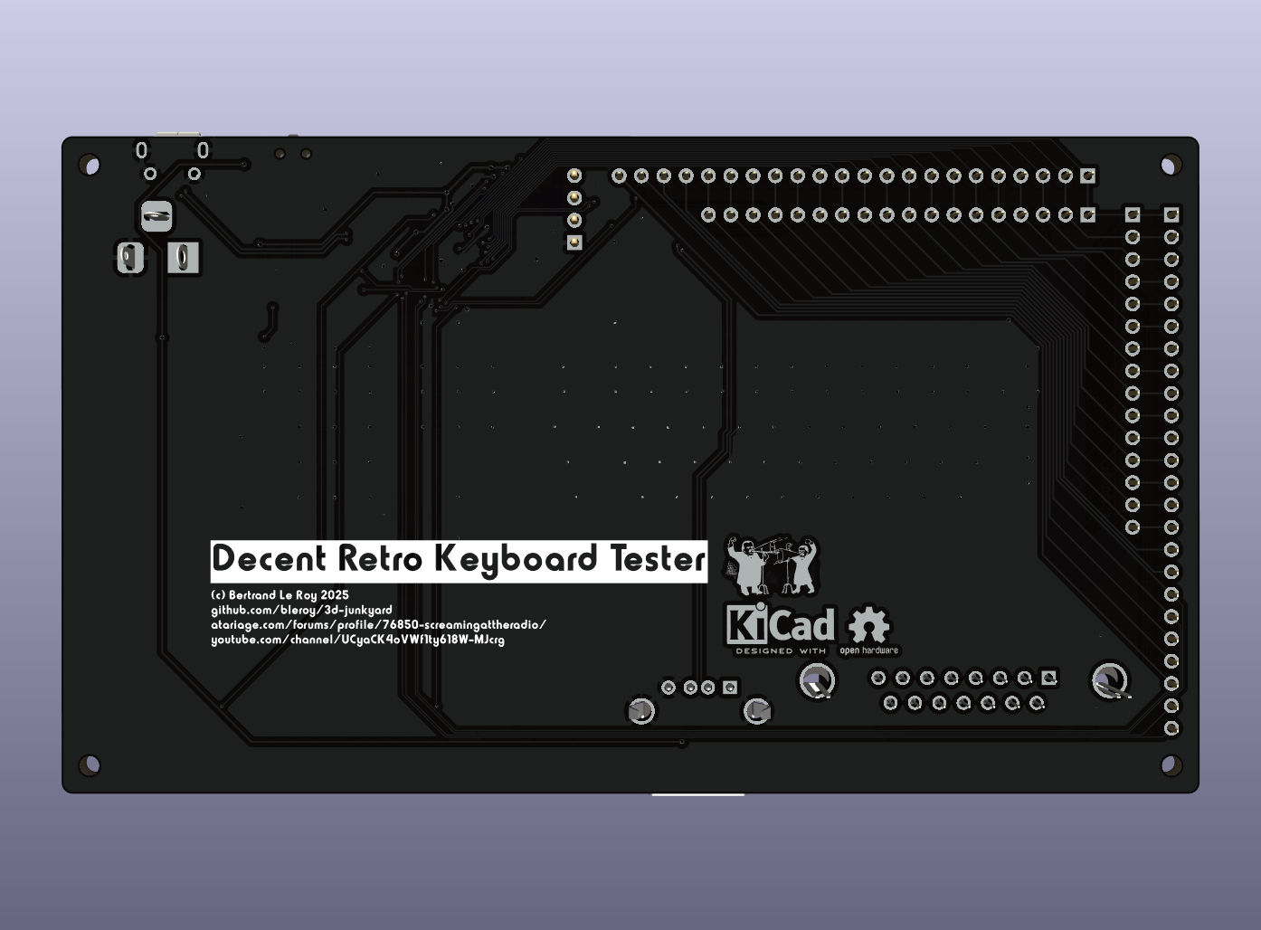
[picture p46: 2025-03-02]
misc-models/KeyboardTester/Media/DecentKeyboardTester-back.png

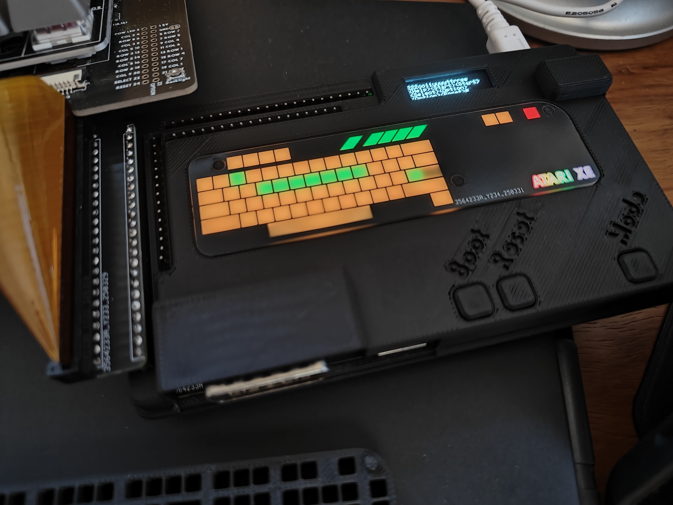
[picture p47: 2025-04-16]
misc-models/KeyboardTester/Media/TestingXE.jpg

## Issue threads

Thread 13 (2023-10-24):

Incorrect file linked in README.md

spicyjack, 2023-10-24:
Hi,

In the section of the `README.md` called "Key Caps", there's this paragraph:

> The first solution is to `[3D-print your own](https://github.com/bleroy/3d-junkyard/blob/main/Atari130MX/Caps/fn-choc.stl) `and then paint them. I recommend [Tamiya Sea Grey model paint](https://www.tamiyausa.com/shop/acrylic-paint-flat-mini-10ml/acrylic-mini-xf-83-m-sea-gray/) for a pretty good match with the Atari XE case color. You can mask the legends when painting to make them stand out.

The file `fn-choc.stl` doesn't exist in the repo, so the above Markdown link 404's; is `Atari130MX/Caps/fn-console-set-choc.stl` the correct filename now?

bleroy, 2023-10-24:
Thanks for the report, I fixed the readme to point at the correct file for console keys.

Closed 2023-10-24.

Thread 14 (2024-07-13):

DecentXE Plate issues

ProfsRetroFix, 2024-07-13:
I've asked PCBWay to make an aluminium plate using the plate gerbers here.

However they've come back to me with a few issues as below:

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

Any ideas as to the answers? I'm relatively oblivious to Gerber files I'm afraid. I've attached the image they want me to 'check'.
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

bleroy, 2024-07-13:
I have no idea why PCBWay can't find the inner edge cuts. They are on the same edge cut layer as the outline of the PCB. I've had dozens of this plate made at JLCPCB without issue. JLCPCB is also generally much less expensive.

The board is single layer. They can obviously ignore the second one.

Closed 2024-07-13.

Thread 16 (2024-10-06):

1200XL console keys

jma7x, 2024-10-06:
I'm starting to build a 1200xl keyboard (version 4m), and have a question about the console keys.
The readme says to use Kailh Choc v1 keyswitches, and that matches the 3d model for the caps.  However, the footprint on the pcb seems to be for cherry mx switches only?  Is there a 3d model for caps that will work with those?

Thanks

bleroy, 2024-10-07:
Oh wow, this is embarrassing, and you're totally right. I have a whole batch of those that I can just throw into the bin. I'll update the design as soon as I can.

bleroy, 2024-10-08:
Version 5m is in, with the correct footprint. Please use this.

Closed 2024-10-08.

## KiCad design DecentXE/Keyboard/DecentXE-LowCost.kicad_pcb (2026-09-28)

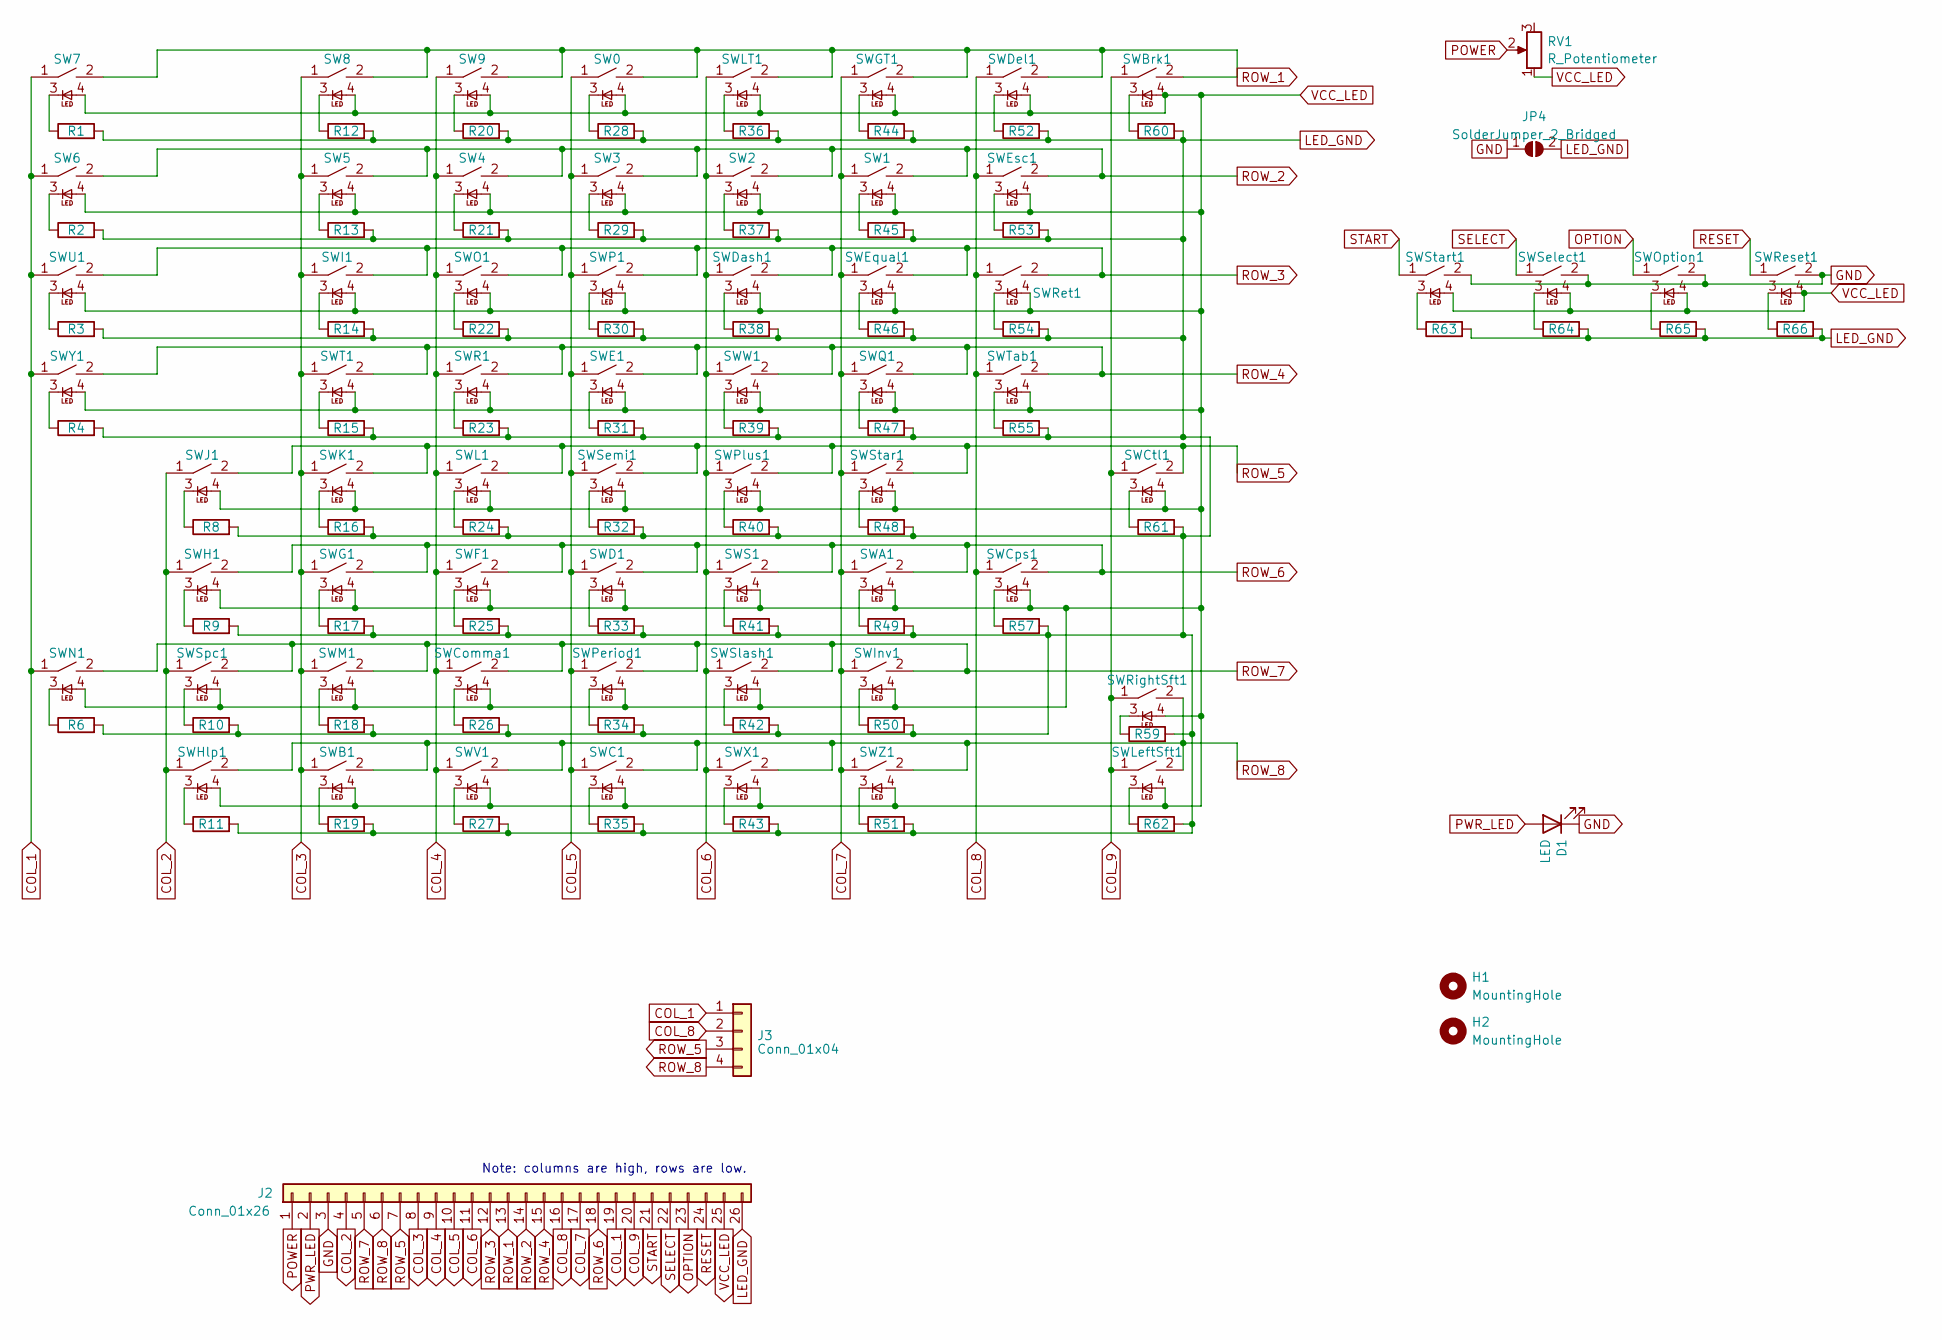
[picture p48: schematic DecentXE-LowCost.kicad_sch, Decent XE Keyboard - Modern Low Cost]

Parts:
D1: LED; LED_0603_1608Metric; JLCPCB Part # C2286
H1, H2: MountingHole; MountingHole_3.2mm_M3
J2: Conn_01x26; Molex_200528-0260_1x26-1MP_P1.00mm_Horizontal; JLCPCB Part # C2914085
J3: Conn_01x04; JST_EH_S4B-EH_1x04_P2.50mm_Horizontal
JP4: SolderJumper_2_Bridged; SolderJumper-2_P1.3mm_Bridged_RoundedPad1.0x1.5mm
R1, R2, R3, R4, R6, R8, R9, R10, R11, R12, R13, R14, R15, R16, R17, R18, R19, R20, R21, R22, R23, R24, R25, R26, R27, R28, R29, R30, R31, R32, R33, R34, R35, R36, R37, R38, R39, R40, R41, R42, R43, R44, R45, R46, R47, R48, R49, R50, R51, R52, R53, R54, R55, R57, R59, R60, R61, R62, R63, R64, R65, R66: R; R_0603_1608Metric; JLCPCB Part # C22775
RV1: R_Potentiometer; Potentiometer_Bourns_TC33X_Vertical; JLCPCB Part # C719174
SW0, SW1, SW2, SW3, SW4, SW5, SW6, SW7, SW8, SW9: SW_Push_45deg; MX-1-00U-LED; JLCPCB Part # C193191
SWA1: SW_Push_45deg; MX-1-00U-LED; JLCPCB Part # C193191
SWB1: SW_Push_45deg; MX-1-00U-LED; JLCPCB Part # C193191
SWBrk1: SW_Push_45deg; MX-1-25U-LED; JLCPCB Part # C193191
SWC1: SW_Push_45deg; MX-1-00U-LED; JLCPCB Part # C193191
SWComma1: SW_Push_45deg; MX-1-00U-LED; JLCPCB Part # C193191
SWCps1: SW_Push_45deg; MX-1-75U-LED; JLCPCB Part # C193191
SWCtl1: SW_Push_45deg; MX-1-25U-LED; JLCPCB Part # C193191
SWD1: SW_Push_45deg; MX-1-00U-LED; JLCPCB Part # C193191
SWDash1: SW_Push_45deg; MX-1-00U-LED; JLCPCB Part # C193191
SWDel1: SW_Push_45deg; MX-2-00U-LED; JLCPCB Part # C193191
SWE1: SW_Push_45deg; MX-1-00U-LED; JLCPCB Part # C193191
SWEqual1: SW_Push_45deg; MX-1-00U-LED; JLCPCB Part # C193191
SWEsc1: SW_Push_45deg; MX-1-00U-LED; JLCPCB Part # C193191
SWF1: SW_Push_45deg; MX-1-00U-LED; JLCPCB Part # C193191
SWG1: SW_Push_45deg; MX-1-00U-LED; JLCPCB Part # C193191
SWGT1: SW_Push_45deg; MX-1-00U-LED; JLCPCB Part # C193191
SWH1: SW_Push_45deg; MX-1-00U-LED; JLCPCB Part # C193191
SWHlp1: SW_Push_45deg; Choc-1-50U-Atari-Fn-LED; JLCPCB Part # C193191
SWI1: SW_Push_45deg; MX-1-00U-LED; JLCPCB Part # C193191
SWInv1: SW_Push_45deg; MX-1-00U-LED; JLCPCB Part # C193191
SWJ1: SW_Push_45deg; MX-1-00U-LED; JLCPCB Part # C193191
SWK1: SW_Push_45deg; MX-1-00U-LED; JLCPCB Part # C193191
SWL1: SW_Push_45deg; MX-1-00U-LED; JLCPCB Part # C193191
SWLT1: SW_Push_45deg; MX-1-00U-LED; JLCPCB Part # C193191
SWLeftSft1: SW_Push_45deg; MX-2-25U-LED; JLCPCB Part # C193191
SWM1: SW_Push_45deg; MX-1-00U-LED; JLCPCB Part # C193191
SWN1: SW_Push_45deg; MX-1-00U-LED; JLCPCB Part # C193191
SWO1: SW_Push_45deg; MX-1-00U-LED; JLCPCB Part # C193191
SWOption1: SW_Push_45deg; Choc-1-50U-Atari-Fn-LED; JLCPCB Part # C193191
SWP1: SW_Push_45deg; MX-1-00U-LED; JLCPCB Part # C193191
SWPeriod1: SW_Push_45deg; MX-1-00U-LED; JLCPCB Part # C193191
SWPlus1: SW_Push_45deg; MX-1-00U-LED; JLCPCB Part # C193191
SWQ1: SW_Push_45deg; MX-1-00U-LED; JLCPCB Part # C193191
SWR1: SW_Push_45deg; MX-1-00U-LED; JLCPCB Part # C193191
SWReset1: SW_Push_45deg; Choc-1-50U-Atari-Fn-LED; JLCPCB Part # C193191
SWRet1: SW_Push_45deg; MX-ISO-RETURN; JLCPCB Part # C193191
SWRightSft1: SW_Push_45deg; MX-1-75U-LED; JLCPCB Part # C193191
SWS1: SW_Push_45deg; MX-1-00U-LED; JLCPCB Part # C193191
SWSelect1: SW_Push_45deg; Choc-1-50U-Atari-Fn-LED; JLCPCB Part # C193191
SWSemi1: SW_Push_45deg; MX-1-00U-LED; JLCPCB Part # C193191
SWSlash1: SW_Push_45deg; MX-1-00U-LED; JLCPCB Part # C193191
SWSpc1: SW_Push_45deg; MX-6-25U-LED; JLCPCB Part # C193191
SWStar1: SW_Push_45deg; MX-1-00U-LED; JLCPCB Part # C193191
SWStart1: SW_Push_45deg; Choc-1-50U-Atari-Fn-LED; JLCPCB Part # C193191
SWT1: SW_Push_45deg; MX-1-00U-LED; JLCPCB Part # C193191
SWTab1: SW_Push_45deg; MX-1-50U-LED; JLCPCB Part # C193191
SWU1: SW_Push_45deg; MX-1-00U-LED; JLCPCB Part # C193191
SWV1: SW_Push_45deg; MX-1-00U-LED; JLCPCB Part # C193191
SWW1: SW_Push_45deg; MX-1-00U-LED; JLCPCB Part # C193191
SWX1: SW_Push_45deg; MX-1-00U-LED; JLCPCB Part # C193191
SWY1: SW_Push_45deg; MX-1-00U-LED; JLCPCB Part # C193191
SWZ1: SW_Push_45deg; MX-1-00U-LED; JLCPCB Part # C193191

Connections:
COL_1: J2.19, J3.1, SW6.1, SW7.1, SWN1.1, SWU1.1, SWY1.1
COL_2: J2.4, SWH1.1, SWHlp1.1, SWJ1.1, SWSpc1.1
COL_3: J2.8, SW5.1, SW8.1, SWB1.1, SWG1.1, SWI1.1, SWK1.1, SWM1.1, SWT1.1
COL_4: J2.9, SW4.1, SW9.1, SWComma1.1, SWF1.1, SWL1.1, SWO1.1, SWR1.1, SWV1.1
COL_5: J2.10, SW0.1, SW3.1, SWC1.1, SWD1.1, SWE1.1, SWP1.1, SWPeriod1.1, SWSemi1.1
COL_6: J2.11, SW2.1, SWDash1.1, SWLT1.1, SWPlus1.1, SWS1.1, SWSlash1.1, SWW1.1, SWX1.1
COL_7: J2.17, SW1.1, SWA1.1, SWEqual1.1, SWGT1.1, SWInv1.1, SWQ1.1, SWStar1.1, SWZ1.1
COL_8: J2.16, J3.2, SWCps1.1, SWDel1.1, SWEsc1.1, SWRet1.1, SWTab1.1
COL_9: J2.20, SWBrk1.1, SWCtl1.1, SWLeftSft1.1, SWRightSft1.1
GND: D1.1 (K), J2.3, JP4.1 (A), SWOption1.2, SWReset1.2, SWSelect1.2, SWStart1.2
LED_GND: J2.26, JP4.2 (B), R1.2, R2.2, R3.2, R4.2, R6.2, R8.2, R9.2, R10.2, R11.2, R12.2, R13.2, R14.2, R15.2, R16.2, R17.2, R18.2, R19.2, R20.2, R21.2, R22.2, R23.2, R24.2, R25.2, R26.2, R27.2, R28.2, R29.2, R30.2, R31.2, R32.2, R33.2, R34.2, R35.2, R36.2, R37.2, R38.2, R39.2, R40.2, R41.2, R42.2, R43.2, R44.2, R45.2, R46.2, R47.2, R48.2, R49.2, R50.2, R51.2, R52.2, R53.2, R54.2, R55.2, R57.2, R59.2, R60.2, R61.2, R62.2, R63.2, R64.2, R65.2, R66.2
unnamed: R1.1, SW7.3
unnamed: R2.1, SW6.3
unnamed: R3.1, SWU1.3
unnamed: R4.1, SWY1.3
unnamed: R6.1, SWN1.3
unnamed: R8.1, SWJ1.3
unnamed: R9.1, SWH1.3
unnamed: R10.1, SWSpc1.3
unnamed: R11.1, SWHlp1.3
unnamed: R12.1, SW8.3
unnamed: R13.1, SW5.3
unnamed: R14.1, SWI1.3
unnamed: R15.1, SWT1.3
unnamed: R16.1, SWK1.3
unnamed: R17.1, SWG1.3
unnamed: R18.1, SWM1.3
unnamed: R19.1, SWB1.3
unnamed: R20.1, SW9.3
unnamed: R21.1, SW4.3
unnamed: R22.1, SWO1.3
unnamed: R23.1, SWR1.3
unnamed: R24.1, SWL1.3
unnamed: R25.1, SWF1.3
unnamed: R26.1, SWComma1.3
unnamed: R27.1, SWV1.3
unnamed: R28.1, SW0.3
unnamed: R29.1, SW3.3
unnamed: R30.1, SWP1.3
unnamed: R31.1, SWE1.3
unnamed: R32.1, SWSemi1.3
unnamed: R33.1, SWD1.3
unnamed: R34.1, SWPeriod1.3
unnamed: R35.1, SWC1.3
unnamed: R36.1, SWLT1.3
unnamed: R37.1, SW2.3
unnamed: R38.1, SWDash1.3
unnamed: R39.1, SWW1.3
unnamed: R40.1, SWPlus1.3
unnamed: R41.1, SWS1.3
unnamed: R42.1, SWSlash1.3
unnamed: R43.1, SWX1.3
unnamed: R44.1, SWGT1.3
unnamed: R45.1, SW1.3
unnamed: R46.1, SWEqual1.3
unnamed: R47.1, SWQ1.3
unnamed: R48.1, SWStar1.3
unnamed: R49.1, SWA1.3
unnamed: R50.1, SWInv1.3
unnamed: R51.1, SWZ1.3
unnamed: R52.1, SWDel1.3
unnamed: R53.1, SWEsc1.3
unnamed: R54.1, SWRet1.3
unnamed: R55.1, SWTab1.3
unnamed: R57.1, SWCps1.3
unnamed: R59.1, SWRightSft1.3
unnamed: R60.1, SWBrk1.3
unnamed: R61.1, SWCtl1.3
unnamed: R62.1, SWLeftSft1.3
unnamed: R63.1, SWStart1.3
unnamed: R64.1, SWSelect1.3
unnamed: R65.1, SWOption1.3
unnamed: R66.1, SWReset1.3
OPTION: J2.23, SWOption1.1
POWER: J2.1, RV1.2
PWR_LED: D1.2 (A), J2.2
RESET: J2.24, SWReset1.1
ROW_1: J2.13, SW0.2, SW7.2, SW8.2, SW9.2, SWBrk1.2, SWDel1.2, SWGT1.2, SWLT1.2
ROW_2: J2.14, SW1.2, SW2.2, SW3.2, SW4.2, SW5.2, SW6.2, SWEsc1.2
ROW_3: J2.12, SWDash1.2, SWEqual1.2, SWI1.2, SWO1.2, SWP1.2, SWRet1.2, SWU1.2
ROW_4: J2.15, SWE1.2, SWQ1.2, SWR1.2, SWT1.2, SWTab1.2, SWW1.2, SWY1.2
ROW_5: J2.7, J3.3, SWCtl1.2, SWJ1.2, SWK1.2, SWL1.2, SWPlus1.2, SWSemi1.2, SWStar1.2
ROW_6: J2.18, SWA1.2, SWCps1.2, SWD1.2, SWF1.2, SWG1.2, SWH1.2, SWS1.2
ROW_7: J2.5, SWComma1.2, SWInv1.2, SWM1.2, SWN1.2, SWPeriod1.2, SWSlash1.2, SWSpc1.2
ROW_8: J2.6, J3.4, SWB1.2, SWC1.2, SWHlp1.2, SWLeftSft1.2, SWRightSft1.2, SWV1.2, SWX1.2, SWZ1.2
SELECT: J2.22, SWSelect1.1
START: J2.21, SWStart1.1
VCC_LED: J2.25, RV1.1, SW0.4, SW1.4, SW2.4, SW3.4, SW4.4, SW5.4, SW6.4, SW7.4, SW8.4, SW9.4, SWA1.4, SWB1.4, SWBrk1.4, SWC1.4, SWComma1.4, SWCps1.4, SWCtl1.4, SWD1.4, SWDash1.4, SWDel1.4, SWE1.4, SWEqual1.4, SWEsc1.4, SWF1.4, SWG1.4, SWGT1.4, SWH1.4, SWHlp1.4, SWI1.4, SWInv1.4, SWJ1.4, SWK1.4, SWL1.4, SWLT1.4, SWLeftSft1.4, SWM1.4, SWN1.4, SWO1.4, SWOption1.4, SWP1.4, SWPeriod1.4, SWPlus1.4, SWQ1.4, SWR1.4, SWReset1.4, SWRet1.4, SWRightSft1.4, SWS1.4, SWSelect1.4, SWSemi1.4, SWSlash1.4, SWSpc1.4, SWStar1.4, SWStart1.4, SWT1.4, SWTab1.4, SWU1.4, SWV1.4, SWW1.4, SWX1.4, SWY1.4, SWZ1.4

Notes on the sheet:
Note: columns are high, rows are low.

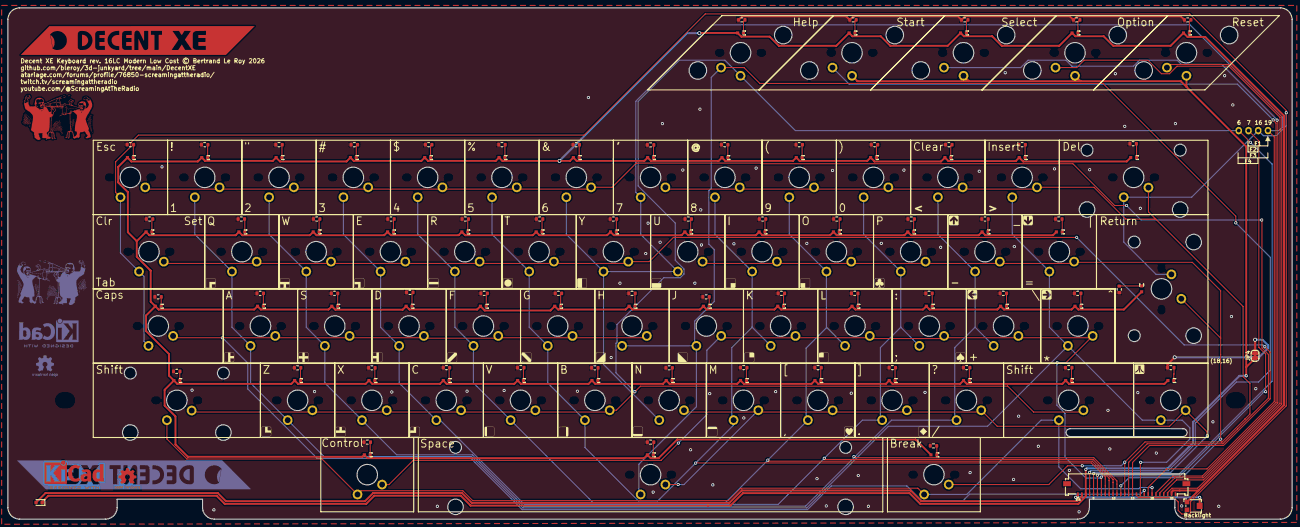
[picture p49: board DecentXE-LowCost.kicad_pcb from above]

Board: 2 copper layers, 329.2 x 131.1 mm, 131 parts (1 on the bottom side), 88 nets.

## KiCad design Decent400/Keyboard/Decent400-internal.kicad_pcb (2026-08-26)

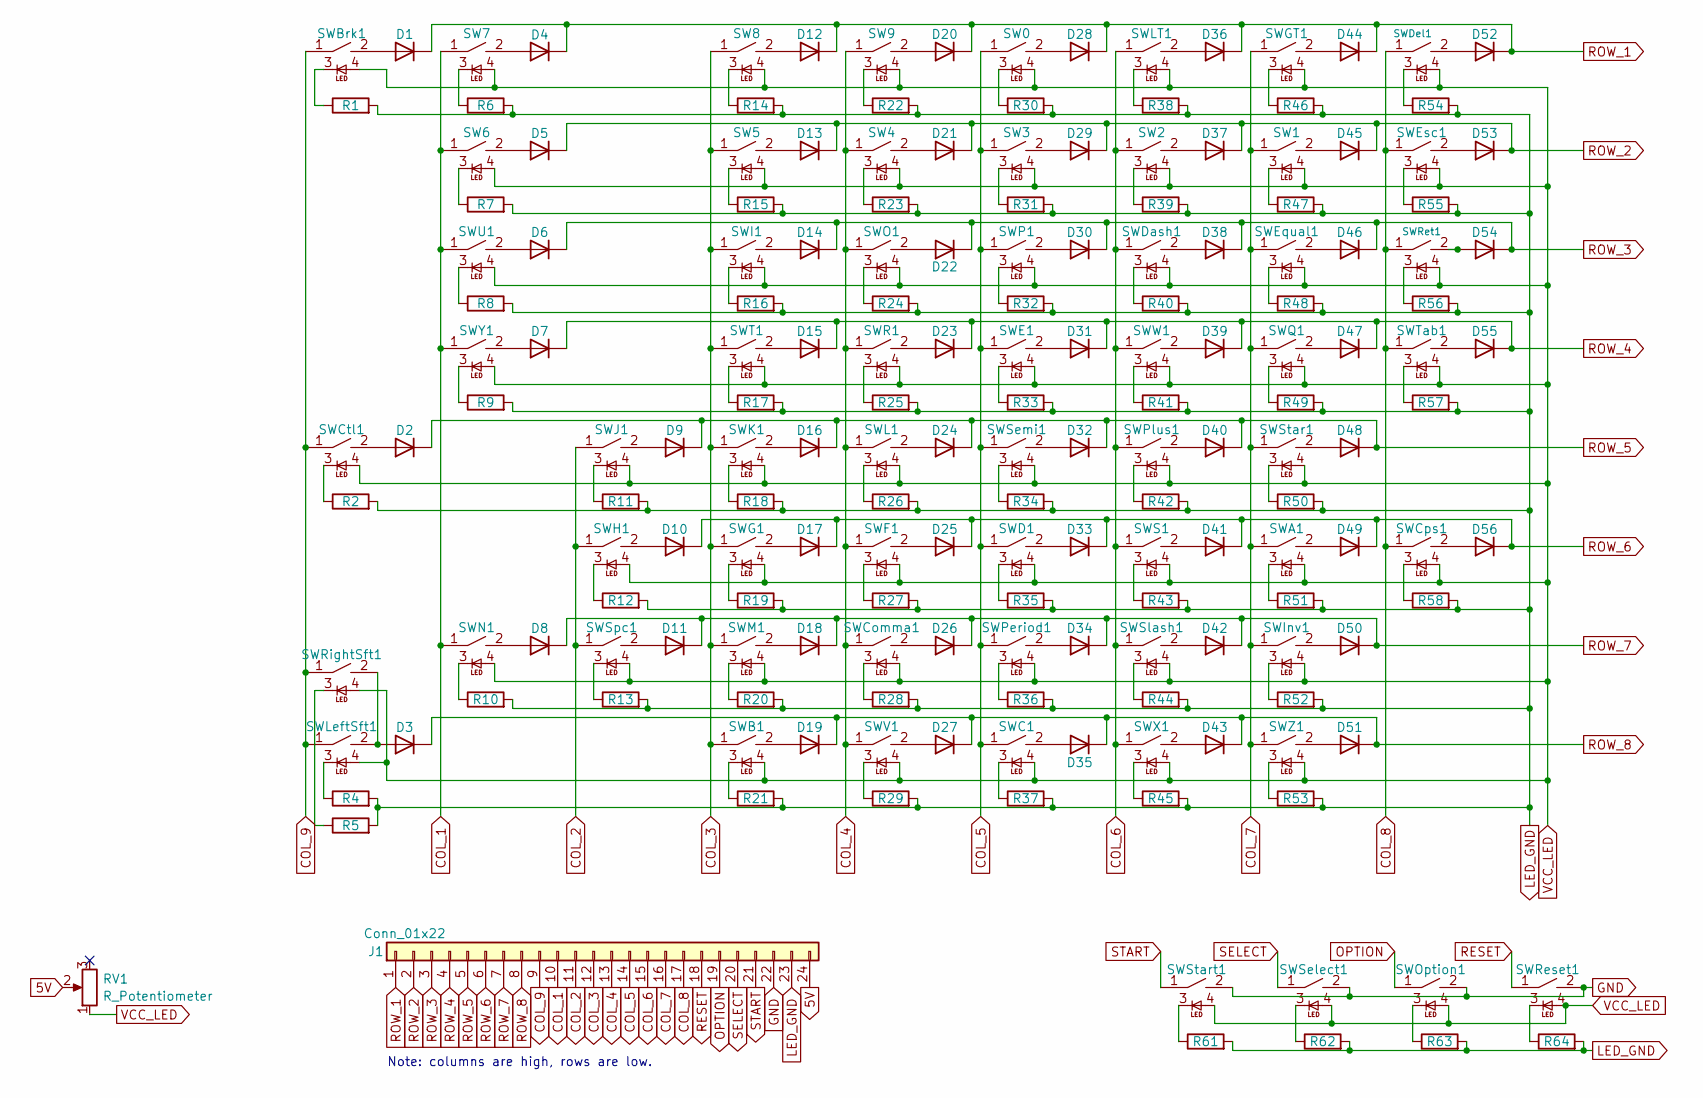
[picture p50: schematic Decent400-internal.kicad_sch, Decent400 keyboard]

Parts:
D1, D2, D3, D4, D5, D6, D7, D8, D9, D10, D11, D12, D13, D14, D15, D16, D17, D18, D19, D20, D21, D22, D23, D24, D25, D26, D27, D28, D29, D30, D31, D32, D33, D34, D35, D36, D37, D38, D39, D40, D41, D42, D43, D44, D45, D46, D47, D48, D49, D50, D51, D52, D53, D54, D55, D56: 1N4148W; D_SOD-123; LCSC Part # C81598
J1: Conn_01x22; IDC-Header_2x12_P2.54mm_Vertical
R1, R2, R4, R5, R6, R7, R8, R9, R10, R11, R12, R13, R14, R15, R16, R17, R18, R19, R20, R21, R22, R23, R24, R25, R26, R27, R28, R29, R30, R31, R32, R33, R34, R35, R36, R37, R38, R39, R40, R41, R42, R43, R44, R45, R46, R47, R48, R49, R50, R51, R52, R53, R54, R55, R56, R57, R58, R61, R62, R63, R64: 100; R_0402_1005Metric; LCSC Part # C25076
RV1: R_Potentiometer; Potentiometer_Bourns_TC33X_Vertical; LCSC Part # C720647
SW0, SW1, SW2, SW3, SW4, SW5, SW6, SW7, SW8, SW9: SW_LED; Choc-1-00U-LED; LCSC Part # C2290
SWA1: SW_LED; Choc-1-00U-LED; LCSC Part # C2290
SWB1: SW_LED; Choc-1-00U-LED; LCSC Part # C2290
SWBrk1: SW_LED; Choc-1-00U-LED; LCSC Part # C2290
SWC1: SW_LED; Choc-1-00U-LED; LCSC Part # C2290
SWComma1: SW_LED; Choc-1-00U-LED; LCSC Part # C2290
SWCps1: SW_LED; Choc-1-00U-LED; LCSC Part # C2290
SWCtl1: SW_LED; Choc-1-50U-LED; LCSC Part # C2290
SWD1: SW_LED; Choc-1-00U-LED; LCSC Part # C2290
SWDash1: SW_LED; Choc-1-00U-LED; LCSC Part # C2290
SWDel1: SW_LED; Choc-1-00U-LED; LCSC Part # C2290
SWE1: SW_LED; Choc-1-00U-LED; LCSC Part # C2290
SWEqual1: SW_LED; Choc-1-00U-LED; LCSC Part # C2290
SWEsc1: SW_LED; Choc-1-00U-LED; LCSC Part # C2290
SWF1: SW_LED; Choc-1-00U-LED; LCSC Part # C2290
SWG1: SW_LED; Choc-1-00U-LED; LCSC Part # C2290
SWGT1: SW_LED; Choc-1-00U-LED; LCSC Part # C2290
SWH1: SW_LED; Choc-1-00U-LED; LCSC Part # C2290
SWI1: SW_LED; Choc-1-00U-LED; LCSC Part # C2290
SWInv1: SW_LED; Choc-1-00U-LED; LCSC Part # C2290
SWJ1: SW_LED; Choc-1-00U-LED; LCSC Part # C2290
SWK1: SW_LED; Choc-1-00U-LED; LCSC Part # C2290
SWL1: SW_LED; Choc-1-00U-LED; LCSC Part # C2290
SWLT1: SW_LED; Choc-1-00U-LED; LCSC Part # C2290
SWLeftSft1: SW_LED; Choc-2-00U-LED; LCSC Part # C2290
SWM1: SW_LED; Choc-1-00U-LED; LCSC Part # C2290
SWN1: SW_LED; Choc-1-00U-LED; LCSC Part # C2290
SWO1: SW_LED; Choc-1-00U-LED; LCSC Part # C2290
SWOption1: SW_LED; Choc-1-00U-LED; LCSC Part # C2290
SWP1: SW_LED; Choc-1-00U-LED; LCSC Part # C2290
SWPeriod1: SW_LED; Choc-1-00U-LED; LCSC Part # C2290
SWPlus1: SW_LED; Choc-1-00U-LED; LCSC Part # C2290
SWQ1: SW_LED; Choc-1-00U-LED; LCSC Part # C2290
SWR1: SW_LED; Choc-1-00U-LED; LCSC Part # C2290
SWReset1: SW_LED; Choc-1-00U-LED; LCSC Part # C2290
SWRet1: SW_LED; Choc-1-25U-LED; LCSC Part # C2290
SWRightSft1: SW_LED; Choc-1-25U-LED; LCSC Part # C2290
SWS1: SW_LED; Choc-1-00U-LED; LCSC Part # C2290
SWSelect1: SW_LED; Choc-1-00U-LED; LCSC Part # C2290
SWSemi1: SW_LED; Choc-1-00U-LED; LCSC Part # C2290
SWSlash1: SW_LED; Choc-1-00U-LED; LCSC Part # C2290
SWSpc1: SW_LED; Choc-6-25U-LED; LCSC Part # C2290
SWStar1: SW_LED; Choc-1-00U-LED; LCSC Part # C2290
SWStart1: SW_LED; Choc-1-00U-LED; LCSC Part # C2290
SWT1: SW_LED; Choc-1-00U-LED; LCSC Part # C2290
SWTab1: SW_LED; Choc-1-50U-LED; LCSC Part # C2290
SWU1: SW_LED; Choc-1-00U-LED; LCSC Part # C2290
SWV1: SW_LED; Choc-1-00U-LED; LCSC Part # C2290
SWW1: SW_LED; Choc-1-00U-LED; LCSC Part # C2290
SWX1: SW_LED; Choc-1-00U-LED; LCSC Part # C2290
SWY1: SW_LED; Choc-1-00U-LED; LCSC Part # C2290
SWZ1: SW_LED; Choc-1-00U-LED; LCSC Part # C2290

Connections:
5V: J1.24, RV1.2
COL_1: J1.10, SW6.1, SW7.1, SWN1.1, SWU1.1, SWY1.1
COL_2: J1.11, SWH1.1, SWJ1.1, SWSpc1.1
COL_3: J1.12, SW5.1, SW8.1, SWB1.1, SWG1.1, SWI1.1, SWK1.1, SWM1.1, SWT1.1
COL_4: J1.13, SW4.1, SW9.1, SWComma1.1, SWF1.1, SWL1.1, SWO1.1, SWR1.1, SWV1.1
COL_5: J1.14, SW0.1, SW3.1, SWC1.1, SWD1.1, SWE1.1, SWP1.1, SWPeriod1.1, SWSemi1.1
COL_6: J1.15, SW2.1, SWDash1.1, SWLT1.1, SWPlus1.1, SWS1.1, SWSlash1.1, SWW1.1, SWX1.1
COL_7: J1.16, SW1.1, SWA1.1, SWEqual1.1, SWGT1.1, SWInv1.1, SWQ1.1, SWStar1.1, SWZ1.1
COL_8: J1.17, SWCps1.1, SWDel1.1, SWEsc1.1, SWRet1.1, SWTab1.1
COL_9: J1.9, SWBrk1.1, SWCtl1.1, SWLeftSft1.1, SWRightSft1.1
GND: J1.22, SWOption1.2, SWReset1.2, SWSelect1.2, SWStart1.2
LED_GND: J1.23, R1.2, R2.2, R4.2, R5.2, R6.2, R7.2, R8.2, R9.2, R10.2, R11.2, R12.2, R13.2, R14.2, R15.2, R16.2, R17.2, R18.2, R19.2, R20.2, R21.2, R22.2, R23.2, R24.2, R25.2, R26.2, R27.2, R28.2, R29.2, R30.2, R31.2, R32.2, R33.2, R34.2, R35.2, R36.2, R37.2, R38.2, R39.2, R40.2, R41.2, R42.2, R43.2, R44.2, R45.2, R46.2, R47.2, R48.2, R49.2, R50.2, R51.2, R52.2, R53.2, R54.2, R55.2, R56.2, R57.2, R58.2, R61.2, R62.2, R63.2, R64.2
unnamed: D1.2 (A), SWBrk1.2
unnamed: D2.2 (A), SWCtl1.2
unnamed: D3.2 (A), SWLeftSft1.2, SWRightSft1.2
unnamed: D4.2 (A), SW7.2
unnamed: D5.2 (A), SW6.2
unnamed: D6.2 (A), SWU1.2
unnamed: D7.2 (A), SWY1.2
unnamed: D8.2 (A), SWN1.2
unnamed: D9.2 (A), SWJ1.2
unnamed: D10.2 (A), SWH1.2
unnamed: D11.2 (A), SWSpc1.2
unnamed: D12.2 (A), SW8.2
unnamed: D13.2 (A), SW5.2
unnamed: D14.2 (A), SWI1.2
unnamed: D15.2 (A), SWT1.2
unnamed: D16.2 (A), SWK1.2
unnamed: D17.2 (A), SWG1.2
unnamed: D18.2 (A), SWM1.2
unnamed: D19.2 (A), SWB1.2
unnamed: D20.2 (A), SW9.2
unnamed: D21.2 (A), SW4.2
unnamed: D22.2 (A), SWO1.2
unnamed: D23.2 (A), SWR1.2
unnamed: D24.2 (A), SWL1.2
unnamed: D25.2 (A), SWF1.2
unnamed: D26.2 (A), SWComma1.2
unnamed: D27.2 (A), SWV1.2
unnamed: D28.2 (A), SW0.2
unnamed: D29.2 (A), SW3.2
unnamed: D30.2 (A), SWP1.2
unnamed: D31.2 (A), SWE1.2
unnamed: D32.2 (A), SWSemi1.2
unnamed: D33.2 (A), SWD1.2
unnamed: D34.2 (A), SWPeriod1.2
unnamed: D35.2 (A), SWC1.2
unnamed: D36.2 (A), SWLT1.2
unnamed: D37.2 (A), SW2.2
unnamed: D38.2 (A), SWDash1.2
unnamed: D39.2 (A), SWW1.2
unnamed: D40.2 (A), SWPlus1.2
unnamed: D41.2 (A), SWS1.2
unnamed: D42.2 (A), SWSlash1.2
unnamed: D43.2 (A), SWX1.2
unnamed: D44.2 (A), SWGT1.2
unnamed: D45.2 (A), SW1.2
unnamed: D46.2 (A), SWEqual1.2
unnamed: D47.2 (A), SWQ1.2
unnamed: D48.2 (A), SWStar1.2
unnamed: D49.2 (A), SWA1.2
unnamed: D50.2 (A), SWInv1.2
unnamed: D51.2 (A), SWZ1.2
unnamed: D52.2 (A), SWDel1.2
unnamed: D53.2 (A), SWEsc1.2
unnamed: D54.2 (A), SWRet1.2
unnamed: D55.2 (A), SWTab1.2
unnamed: D56.2 (A), SWCps1.2
unnamed: R1.1, SWBrk1.3
unnamed: R2.1, SWCtl1.3
unnamed: R4.1, SWLeftSft1.3
unnamed: R5.1, SWRightSft1.3
unnamed: R6.1, SW7.3
unnamed: R7.1, SW6.3
unnamed: R8.1, SWU1.3
unnamed: R9.1, SWY1.3
unnamed: R10.1, SWN1.3
unnamed: R11.1, SWJ1.3
unnamed: R12.1, SWH1.3
unnamed: R13.1, SWSpc1.3
unnamed: R14.1, SW8.3
unnamed: R15.1, SW5.3
unnamed: R16.1, SWI1.3
unnamed: R17.1, SWT1.3
unnamed: R18.1, SWK1.3
unnamed: R19.1, SWG1.3
unnamed: R20.1, SWM1.3
unnamed: R21.1, SWB1.3
unnamed: R22.1, SW9.3
unnamed: R23.1, SW4.3
unnamed: R24.1, SWO1.3
unnamed: R25.1, SWR1.3
unnamed: R26.1, SWL1.3
unnamed: R27.1, SWF1.3
unnamed: R28.1, SWComma1.3
unnamed: R29.1, SWV1.3
unnamed: R30.1, SW0.3
unnamed: R31.1, SW3.3
unnamed: R32.1, SWP1.3
unnamed: R33.1, SWE1.3
unnamed: R34.1, SWSemi1.3
unnamed: R35.1, SWD1.3
unnamed: R36.1, SWPeriod1.3
unnamed: R37.1, SWC1.3
unnamed: R38.1, SWLT1.3
unnamed: R39.1, SW2.3
unnamed: R40.1, SWDash1.3
unnamed: R41.1, SWW1.3
unnamed: R42.1, SWPlus1.3
unnamed: R43.1, SWS1.3
unnamed: R44.1, SWSlash1.3
unnamed: R45.1, SWX1.3
unnamed: R46.1, SWGT1.3
unnamed: R47.1, SW1.3
unnamed: R48.1, SWEqual1.3
unnamed: R49.1, SWQ1.3
unnamed: R50.1, SWStar1.3
unnamed: R51.1, SWA1.3
unnamed: R52.1, SWInv1.3
unnamed: R53.1, SWZ1.3
unnamed: R54.1, SWDel1.3
unnamed: R55.1, SWEsc1.3
unnamed: R56.1, SWRet1.3
unnamed: R57.1, SWTab1.3
unnamed: R58.1, SWCps1.3
unnamed: R61.1, SWStart1.3
unnamed: R62.1, SWSelect1.3
unnamed: R63.1, SWOption1.3
unnamed: R64.1, SWReset1.3
OPTION: J1.19, SWOption1.1
RESET: J1.18, SWReset1.1
ROW_1: D1.1 (K), D4.1 (K), D12.1 (K), D20.1 (K), D28.1 (K), D36.1 (K), D44.1 (K), D52.1 (K), J1.1
ROW_2: D5.1 (K), D13.1 (K), D21.1 (K), D29.1 (K), D37.1 (K), D45.1 (K), D53.1 (K), J1.2
ROW_3: D6.1 (K), D14.1 (K), D22.1 (K), D30.1 (K), D38.1 (K), D46.1 (K), D54.1 (K), J1.3
ROW_4: D7.1 (K), D15.1 (K), D23.1 (K), D31.1 (K), D39.1 (K), D47.1 (K), D55.1 (K), J1.4
ROW_5: D2.1 (K), D9.1 (K), D16.1 (K), D24.1 (K), D32.1 (K), D40.1 (K), D48.1 (K), J1.5
ROW_6: D10.1 (K), D17.1 (K), D25.1 (K), D33.1 (K), D41.1 (K), D49.1 (K), D56.1 (K), J1.6
ROW_7: D8.1 (K), D11.1 (K), D18.1 (K), D26.1 (K), D34.1 (K), D42.1 (K), D50.1 (K), J1.7
ROW_8: D3.1 (K), D19.1 (K), D27.1 (K), D35.1 (K), D43.1 (K), D51.1 (K), J1.8
SELECT: J1.20, SWSelect1.1
START: J1.21, SWStart1.1
VCC_LED: RV1.1, SW0.4, SW1.4, SW2.4, SW3.4, SW4.4, SW5.4, SW6.4, SW7.4, SW8.4, SW9.4, SWA1.4, SWB1.4, SWBrk1.4, SWC1.4, SWComma1.4, SWCps1.4, SWCtl1.4, SWD1.4, SWDash1.4, SWDel1.4, SWE1.4, SWEqual1.4, SWEsc1.4, SWF1.4, SWG1.4, SWGT1.4, SWH1.4, SWI1.4, SWInv1.4, SWJ1.4, SWK1.4, SWL1.4, SWLT1.4, SWLeftSft1.4, SWM1.4, SWN1.4, SWO1.4, SWOption1.4, SWP1.4, SWPeriod1.4, SWPlus1.4, SWQ1.4, SWR1.4, SWReset1.4, SWRet1.4, SWRightSft1.4, SWS1.4, SWSelect1.4, SWSemi1.4, SWSlash1.4, SWSpc1.4, SWStar1.4, SWStart1.4, SWT1.4, SWTab1.4, SWU1.4, SWV1.4, SWW1.4, SWX1.4, SWY1.4, SWZ1.4

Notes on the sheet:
Note: columns are high, rows are low.

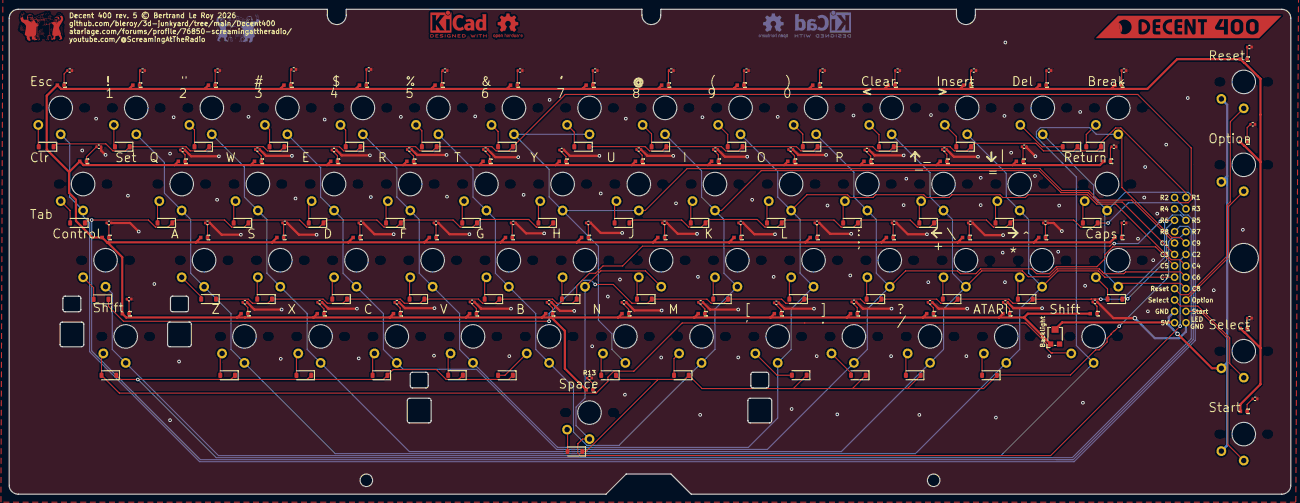
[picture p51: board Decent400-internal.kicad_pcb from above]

Board: 2 copper layers, 286.0 x 108.2 mm, 180 parts (1 on the bottom side), 142 nets.

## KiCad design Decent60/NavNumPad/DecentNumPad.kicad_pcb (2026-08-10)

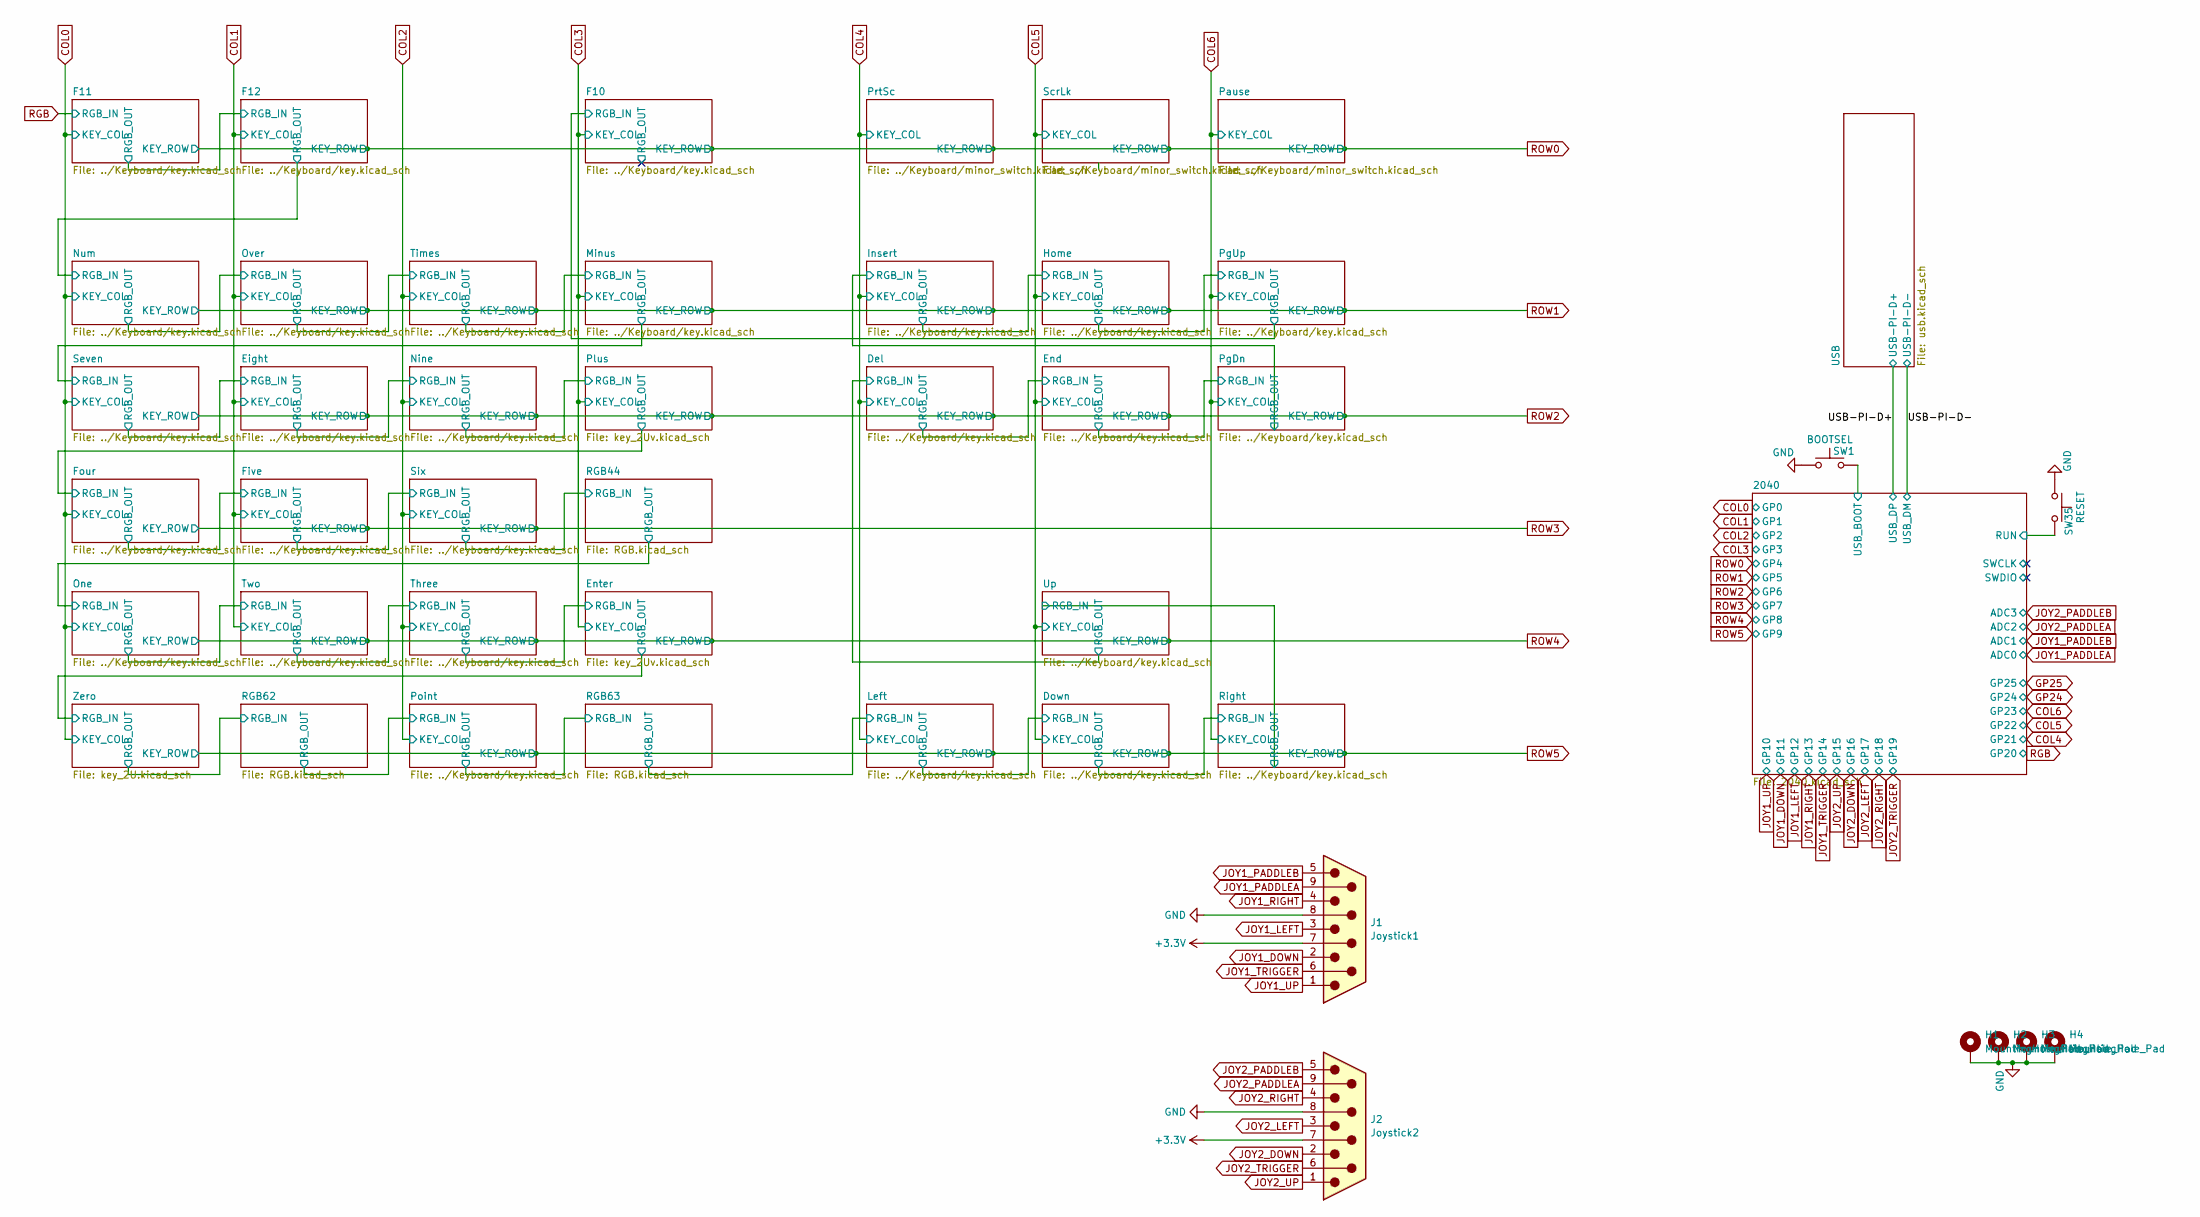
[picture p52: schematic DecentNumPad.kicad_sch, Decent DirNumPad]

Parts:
H1, H2, H3, H4: MountingHole_Pad; MountingHole_2.5mm_Pad_Via
J1: Joystick1; DSUB-9_Pins_Horizontal_P2.77x2.84mm_EdgePinOffset4.94mm_Hou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
J2: Joystick2; DSUB-9_Pins_Horizontal_P2.77x2.84mm_EdgePinOffset4.94mm_Hou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
SW1: BOOTSEL; SW-SMD_L3.9-W3.0-P4.45; LCSC Part # C720477
SW35: RESET; SW-SMD_L3.9-W3.0-P4.45; LCSC Part # C720477

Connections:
+3.3V: J1.7, J2.7; also elsewhere on the board
/2040/RUN: SW35.2; also elsewhere on the board
/2040/USB_BOOT: SW1.2; also elsewhere on the board
GND: H1.1 (1_1), H2.1 (1_1), H3.1 (1_1), H4.1 (1_1), J1.8, J2.8, SW1.1, SW35.1; also elsewhere on the board
JOY1_DOWN: J1.2; also elsewhere on the board
JOY1_LEFT: J1.3; also elsewhere on the board
JOY1_PADDLEA: J1.9; also elsewhere on the board
JOY1_PADDLEB: J1.5; also elsewhere on the board
JOY1_RIGHT: J1.4; also elsewhere on the board
JOY1_TRIGGER: J1.6; also elsewhere on the board
JOY1_UP: J1.1; also elsewhere on the board
JOY2_DOWN: J2.2; also elsewhere on the board
JOY2_LEFT: J2.3; also elsewhere on the board
JOY2_PADDLEA: J2.9; also elsewhere on the board
JOY2_PADDLEB: J2.5; also elsewhere on the board
JOY2_RIGHT: J2.4; also elsewhere on the board
JOY2_TRIGGER: J2.6; also elsewhere on the board
JOY2_UP: J2.1; also elsewhere on the board

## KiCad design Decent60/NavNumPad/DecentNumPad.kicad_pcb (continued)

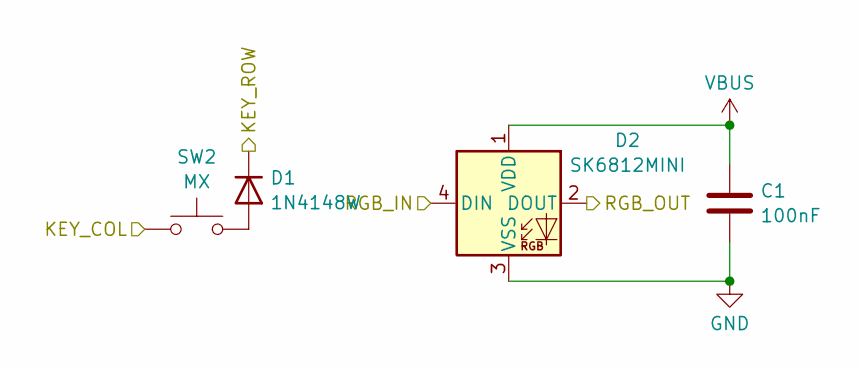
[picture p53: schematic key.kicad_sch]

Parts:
C1: 100nF; C_0402_1005Metric; LCSC Part # C1525
D1: 1N4148W; D_SOD-123; LCSC Part # C81598
D2: SK6812MINI; LED_SK6812MINI-E_3.2x2.8mm_P1.5mm_ReverseMount; LCSC Part # C5378731
SW2: MX; SMD_KEYBOARD-SW; LCSC Part # C41430893

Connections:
/F11/RGB_OUT: D2.2 (DOUT); also elsewhere on the board
COL0: SW2.1; also elsewhere on the board
GND: C1.2, D2.3 (VSS); also elsewhere on the board
unnamed: D1.2 (A), SW2.2
RGB: D2.4 (DIN); also elsewhere on the board
ROW0: D1.1 (K); also elsewhere on the board
VBUS: C1.1, D2.1 (VDD); also elsewhere on the board

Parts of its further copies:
C2, C3, C4, C5, C6, C8, C9, C10, C11, C12, C13, C14, C15, C17, C19, C45, C46, C47, C48, C49, C50, C53, C54, C55, C56, C57: 100nF; C_0402_1005Metric; LCSC Part # C1525
D3, D5, D7, D9, D11, D15, D17, D19, D21, D23, D25, D27, D29, D33, D37, D44, D46, D48, D50, D52, D54, D60, D62, D64, D66, D68: 1N4148W; D_SOD-123; LCSC Part # C81598
D4, D6, D8, D10, D12, D16, D18, D20, D22, D24, D26, D28, D30, D34, D38, D45, D47, D49, D51, D53, D55, D61, D63, D65, D67, D69: SK6812MINI; LED_SK6812MINI-E_3.2x2.8mm_P1.5mm_ReverseMount; LCSC Part # C5378731
SW3, SW4, SW5, SW6, SW7, SW9, SW10, SW11, SW12, SW13, SW14, SW15, SW16, SW18, SW20, SW22, SW23, SW24, SW25, SW26, SW27, SW30, SW31, SW32, SW33, SW34: MX; SMD_KEYBOARD-SW; LCSC Part # C41430893

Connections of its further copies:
/Del/RGB_IN: D51.2 (DOUT), D67.4 (DIN)
/Del/RGB_OUT: D65.4 (DIN), D67.2 (DOUT)
/Down/RGB_IN: D45.2 (DOUT), D47.4 (DIN)
/Down/RGB_OUT: D47.2 (DOUT), D49.4 (DIN)
/Eight/RGB_IN: D16.2 (DOUT), D18.4 (DIN)
/Eight/RGB_OUT: D18.2 (DOUT), D20.4 (DIN)
/End/RGB_OUT: D65.2 (DOUT), D69.4 (DIN)
/Enter/RGB_IN: D30.2 (DOUT); also elsewhere on the board
/F10/RGB_IN: D61.2 (DOUT), D63.4 (DIN)
/F10/RGB_OUT: D63.2 (DOUT)
/F11/RGB_OUT: D4.4 (DIN); also elsewhere on the board
/F12/RGB_OUT: D4.2 (DOUT), D6.4 (DIN)
/Five/RGB_IN: D22.4 (DIN), D28.2 (DOUT)
/Five/RGB_OUT: D22.2 (DOUT), D24.4 (DIN)
/Four/RGB_IN: D28.4 (DIN); also elsewhere on the board
/Home/RGB_IN: D53.2 (DOUT), D55.4 (DIN)
/Home/RGB_OUT: D55.2 (DOUT), D61.4 (DIN)
/Insert/RGB_IN: D53.4 (DIN), D69.2 (DOUT)
/Left/RGB_IN: D45.4 (DIN); also elsewhere on the board
/Minus/RGB_IN: D10.2 (DOUT), D12.4 (DIN)
/Minus/RGB_OUT: D12.2 (DOUT), D16.4 (DIN)
/Nine/RGB_OUT: D20.2 (DOUT); also elsewhere on the board
/Num/RGB_OUT: D6.2 (DOUT), D8.4 (DIN)
/One/RGB_IN: D34.4 (DIN); also elsewhere on the board
/One/RGB_OUT: D26.4 (DIN), D34.2 (DOUT)
/Over/RGB_OUT: D8.2 (DOUT), D10.4 (DIN)
/Point/RGB_IN: D38.4 (DIN); also elsewhere on the board
/Point/RGB_OUT: D38.2 (DOUT); also elsewhere on the board
/RGB44/RGB_IN: D24.2 (DOUT); also elsewhere on the board
/Right/RGB_OUT: D49.2 (DOUT), D51.4 (DIN)
/Three/RGB_IN: D26.2 (DOUT), D30.4 (DIN)
COL0: SW4.1, SW9.1, SW15.1, SW18.1; also elsewhere on the board
COL1: SW3.1, SW5.1, SW10.1, SW12.1, SW14.1; also elsewhere on the board
COL2: SW6.1, SW11.1, SW13.1, SW16.1, SW20.1; also elsewhere on the board
COL3: SW7.1, SW31.1; also elsewhere on the board
COL4: SW22.1, SW26.1, SW33.1; also elsewhere on the board
COL5: SW23.1, SW25.1, SW27.1, SW32.1; also elsewhere on the board
COL6: SW24.1, SW30.1, SW34.1; also elsewhere on the board
GND: C2.2, C3.2, C4.2, C5.2, C6.2, C8.2, C9.2, C10.2, C11.2, C12.2, C13.2, C14.2, C15.2, C17.2, C19.2, C45.2, C46.2, C47.2, C48.2, C49.2, C50.2, C53.2, C54.2, C55.2, C56.2, C57.2, D4.3 (VSS), D6.3 (VSS), D8.3 (VSS), D10.3 (VSS), D12.3 (VSS), D16.3 (VSS), D18.3 (VSS), D20.3 (VSS), D22.3 (VSS), D24.3 (VSS), D26.3 (VSS), D28.3 (VSS), D30.3 (VSS), D34.3 (VSS), D38.3 (VSS), D45.3 (VSS), D47.3 (VSS), D49.3 (VSS), D51.3 (VSS), D53.3 (VSS), D55.3 (VSS), D61.3 (VSS), D63.3 (VSS), D65.3 (VSS), D67.3 (VSS), D69.3 (VSS); also elsewhere on the board
unnamed: D3.2 (A), SW3.2
unnamed: D5.2 (A), SW4.2
unnamed: D7.2 (A), SW5.2
unnamed: D9.2 (A), SW6.2
unnamed: D11.2 (A), SW7.2
unnamed: D15.2 (A), SW9.2
unnamed: D17.2 (A), SW10.2
unnamed: D19.2 (A), SW11.2
unnamed: D21.2 (A), SW12.2
unnamed: D23.2 (A), SW13.2
unnamed: D25.2 (A), SW14.2
unnamed: D27.2 (A), SW15.2
unnamed: D29.2 (A), SW16.2
unnamed: D33.2 (A), SW18.2
unnamed: D37.2 (A), SW20.2
unnamed: D44.2 (A), SW22.2
unnamed: D46.2 (A), SW23.2
unnamed: D48.2 (A), SW24.2
unnamed: D50.2 (A), SW25.2
unnamed: D52.2 (A), SW26.2
unnamed: D54.2 (A), SW27.2
unnamed: D60.2 (A), SW30.2
unnamed: D62.2 (A), SW31.2
unnamed: D64.2 (A), SW32.2
unnamed: D66.2 (A), SW33.2
unnamed: D68.2 (A), SW34.2
ROW0: D3.1 (K), D62.1 (K); also elsewhere on the board
ROW1: D5.1 (K), D7.1 (K), D9.1 (K), D11.1 (K), D52.1 (K), D54.1 (K), D60.1 (K); also elsewhere on the board
ROW2: D15.1 (K), D17.1 (K), D19.1 (K), D64.1 (K), D66.1 (K), D68.1 (K); also elsewhere on the board
ROW3: D21.1 (K), D23.1 (K), D27.1 (K); also elsewhere on the board
ROW4: D25.1 (K), D29.1 (K), D33.1 (K), D50.1 (K); also elsewhere on the board
ROW5: D37.1 (K), D44.1 (K), D46.1 (K), D48.1 (K); also elsewhere on the board
VBUS: C2.1, C3.1, C4.1, C5.1, C6.1, C8.1, C9.1, C10.1, C11.1, C12.1, C13.1, C14.1, C15.1, C17.1, C19.1, C45.1, C46.1, C47.1, C48.1, C49.1, C50.1, C53.1, C54.1, C55.1, C56.1, C57.1, D4.1 (VDD), D6.1 (VDD), D8.1 (VDD), D10.1 (VDD), D12.1 (VDD), D16.1 (VDD), D18.1 (VDD), D20.1 (VDD), D22.1 (VDD), D24.1 (VDD), D26.1 (VDD), D28.1 (VDD), D30.1 (VDD), D34.1 (VDD), D38.1 (VDD), D45.1 (VDD), D47.1 (VDD), D49.1 (VDD), D51.1 (VDD), D53.1 (VDD), D55.1 (VDD), D61.1 (VDD), D63.1 (VDD), D65.1 (VDD), D67.1 (VDD), D69.1 (VDD); also elsewhere on the board

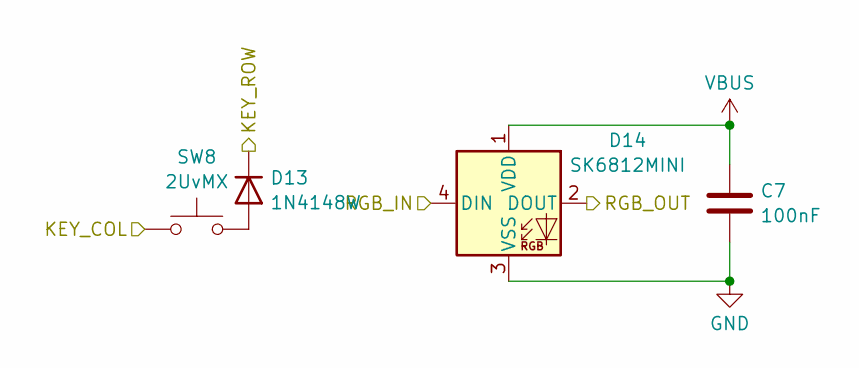
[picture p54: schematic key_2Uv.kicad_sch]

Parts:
C7: 100nF; C_0402_1005Metric; LCSC Part # C1525
D13: 1N4148W; D_SOD-123; LCSC Part # C81598
D14: SK6812MINI; LED_SK6812MINI-E_3.2x2.8mm_P1.5mm_ReverseMount; LCSC Part # C5378731
SW8: 2UvMX; Kailh_socket_MX_2-00U_V; LCSC Part # C41430893

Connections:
/Four/RGB_IN: D14.2 (DOUT); also elsewhere on the board
/Nine/RGB_OUT: D14.4 (DIN); also elsewhere on the board
COL3: SW8.1; also elsewhere on the board
GND: C7.2, D14.3 (VSS); also elsewhere on the board
unnamed: D13.2 (A), SW8.2
ROW2: D13.1 (K); also elsewhere on the board
VBUS: C7.1, D14.1 (VDD); also elsewhere on the board

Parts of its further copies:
C16: 100nF; C_0402_1005Metric; LCSC Part # C1525
D31: 1N4148W; D_SOD-123; LCSC Part # C81598
D32: SK6812MINI; LED_SK6812MINI-E_3.2x2.8mm_P1.5mm_ReverseMount; LCSC Part # C5378731
SW17: 2UvMX; Kailh_socket_MX_2-00U_V; LCSC Part # C41430893

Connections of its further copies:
/Enter/RGB_IN: D32.4 (DIN); also elsewhere on the board
/Enter/RGB_OUT: D32.2 (DOUT); also elsewhere on the board
COL3: SW17.1; also elsewhere on the board
GND: C16.2, D32.3 (VSS); also elsewhere on the board
unnamed: D31.2 (A), SW17.2
ROW4: D31.1 (K); also elsewhere on the board
VBUS: C16.1, D32.1 (VDD); also elsewhere on the board

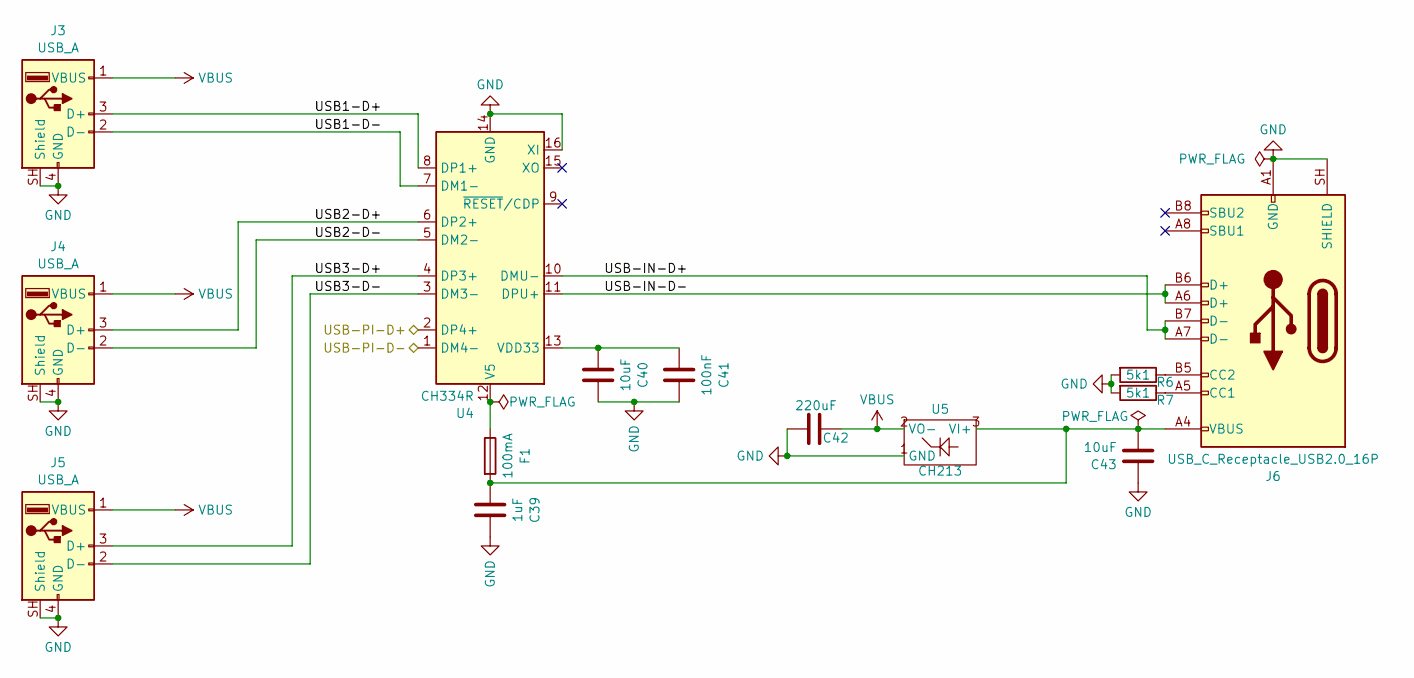
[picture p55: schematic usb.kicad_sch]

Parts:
C39: 1uF; C_0402_1005Metric; LCSC Part # C52923
C40, C43: 10uF; C_0402_1005Metric; LCSC Part # C15525
C41: 100nF; C_0402_1005Metric; LCSC Part # C1525
C42: 220uF; CP_Elec_6.3x5.4; LCSC Part # C3345
F1: 100mA; Fuse_1206_3216Metric; LCSC Part # C269108
J3, J4, J5: USB_A; USB_A_Molex_67643_Horizontal
J6: USB_C_Receptacle_USB2.0_16P; USB_C_Receptacle_HCTL_HC-TYPE-C-16P-01A; LCSC Part # C709357
R6, R7: 5k1; R_0402_1005Metric; LCSC Part # C25905
U4: CH334R; QSOP-16_3.9x4.9mm_P0.635mm; LCSC Part # C4154405
U5: CH213; TSOT-23; LCSC Part # C5456874

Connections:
/USB-PI-D+: U4.2 (DP4+); also elsewhere on the board
/USB-PI-D-: U4.1 (DM4-); also elsewhere on the board
/USB/USB1-D+: J3.3 (D+), U4.8 (DP1+)
/USB/USB1-D-: J3.2 (D-), U4.7 (DM1-)
/USB/USB2-D+: J4.3 (D+), U4.6 (DP2+)
/USB/USB2-D-: J4.2 (D-), U4.5 (DM2-)
/USB/USB3-D+: J5.3 (D+), U4.4 (DP3+)
/USB/USB3-D-: J5.2 (D-), U4.3 (DM3-)
/USB/USB-IN-D+: J6.A7 (D-), J6.B7 (D-), U4.10 (DMU-)
/USB/USB-IN-D-: J6.A6 (D+), J6.B6 (D+), U4.11 (DPU+)
GND: C39.2, C40.2, C41.2, C42.2, C43.1, J3.4 (GND), J3.SH (Shield), J4.4 (GND), J4.SH (Shield), J5.4 (GND), J5.SH (Shield), J6.A1 (GND), J6.A12 (GND), J6.B1 (GND), J6.B12 (GND), J6.SH (SHIELD), R6.2, R7.2, U4.14 (GND), U4.16 (XI), U5.1 (GND); also elsewhere on the board
unnamed: J6.A5 (CC1), R7.1
unnamed: J6.B5 (CC2), R6.1
unnamed: F1.1, U4.12 (V5)
unnamed: C40.1, C41.1, U4.13 (VDD33)
unnamed: C39.1, C43.2, F1.2, J6.A4 (VBUS), J6.A9 (VBUS), J6.B4 (VBUS), J6.B9 (VBUS), U5.3 (VI+)
VBUS: C42.1, J3.1 (VBUS), J4.1 (VBUS), J5.1 (VBUS), U5.2 (VO-); also elsewhere on the board

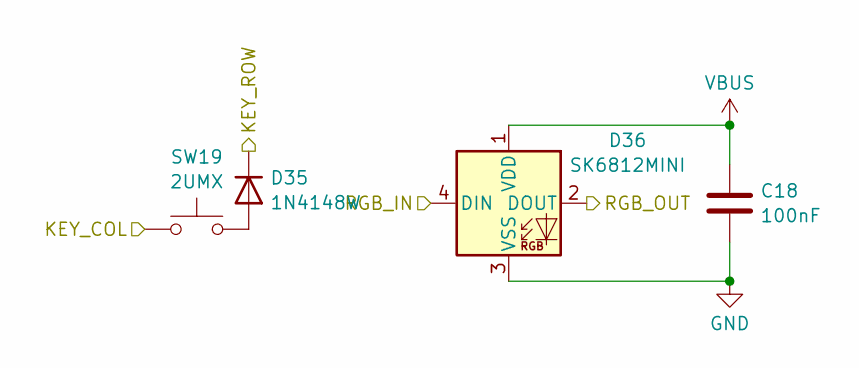
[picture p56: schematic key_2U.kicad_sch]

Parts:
C18: 100nF; C_0402_1005Metric; LCSC Part # C1525
D35: 1N4148W; D_SOD-123; LCSC Part # C81598
D36: SK6812MINI; LED_SK6812MINI-E_3.2x2.8mm_P1.5mm_ReverseMount; LCSC Part # C5378731
SW19: 2UMX; Kailh_socket_MX_2-00U; LCSC Part # C41430893

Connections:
/Enter/RGB_OUT: D36.4 (DIN); also elsewhere on the board
/RGB62/RGB_IN: D36.2 (DOUT); also elsewhere on the board
COL0: SW19.1; also elsewhere on the board
GND: C18.2, D36.3 (VSS); also elsewhere on the board
unnamed: D35.2 (A), SW19.2
ROW5: D35.1 (K); also elsewhere on the board
VBUS: C18.1, D36.1 (VDD); also elsewhere on the board

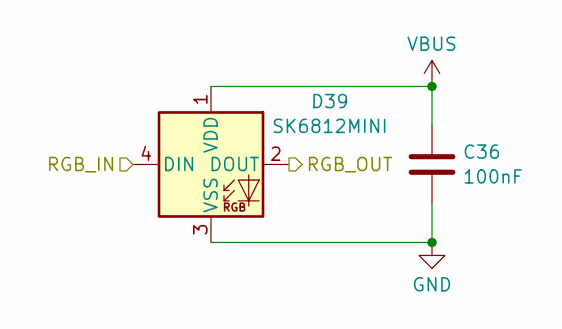
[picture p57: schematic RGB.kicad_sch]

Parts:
C36: 100nF; C_0402_1005Metric; LCSC Part # C1525
D39: SK6812MINI; LED_SK6812MINI-E_3.2x2.8mm_P1.5mm_ReverseMount; LCSC Part # C5378731

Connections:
/One/RGB_IN: D39.2 (DOUT); also elsewhere on the board
/RGB44/RGB_IN: D39.4 (DIN); also elsewhere on the board
GND: C36.2, D39.3 (VSS); also elsewhere on the board
VBUS: C36.1, D39.1 (VDD); also elsewhere on the board

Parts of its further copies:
C37, C38: 100nF; C_0402_1005Metric; LCSC Part # C1525
D40, D41: SK6812MINI; LED_SK6812MINI-E_3.2x2.8mm_P1.5mm_ReverseMount; LCSC Part # C5378731

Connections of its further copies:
/Left/RGB_IN: D41.2 (DOUT); also elsewhere on the board
/Point/RGB_IN: D40.2 (DOUT); also elsewhere on the board
/Point/RGB_OUT: D41.4 (DIN); also elsewhere on the board
/RGB62/RGB_IN: D40.4 (DIN); also elsewhere on the board
GND: C37.2, C38.2, D40.3 (VSS), D41.3 (VSS); also elsewhere on the board
VBUS: C37.1, C38.1, D40.1 (VDD), D41.1 (VDD); also elsewhere on the board

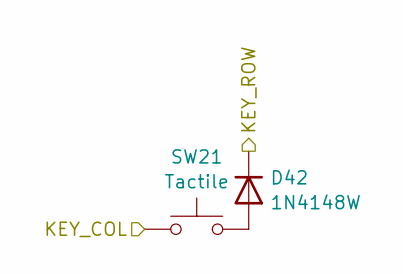
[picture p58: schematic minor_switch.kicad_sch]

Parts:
D42: 1N4148W; D_SOD-123; LCSC Part # C81598
SW21: Tactile; SMD_KEYBOARD-SW; LCSC Part # C41430893

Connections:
COL4: SW21.1; also elsewhere on the board
unnamed: D42.2 (A), SW21.2
ROW0: D42.1 (K); also elsewhere on the board

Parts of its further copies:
D56, D58: 1N4148W; D_SOD-123; LCSC Part # C81598
SW28, SW29: Tactile; SMD_KEYBOARD-SW; LCSC Part # C41430893

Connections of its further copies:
COL5: SW28.1; also elsewhere on the board
COL6: SW29.1; also elsewhere on the board
unnamed: D56.2 (A), SW28.2
unnamed: D58.2 (A), SW29.2
ROW0: D56.1 (K), D58.1 (K); also elsewhere on the board

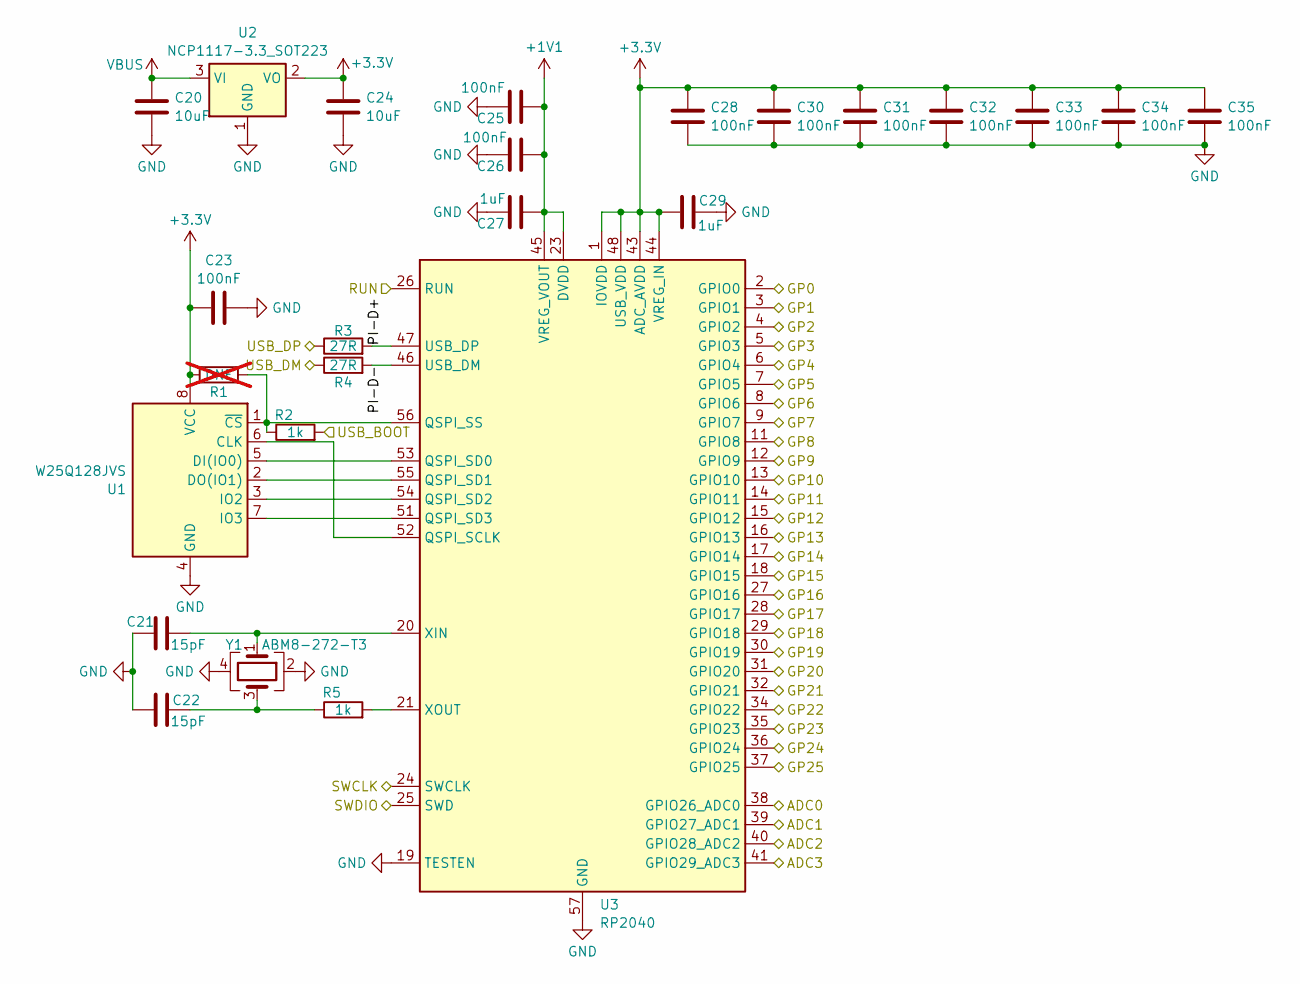
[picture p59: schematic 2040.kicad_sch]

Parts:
C20, C24: 10uF; C_0402_1005Metric; LCSC Part # C15525
C21, C22: 15pF; C_0402_1005Metric; LCSC Part # C1548
C23, C25, C26, C28, C30, C31, C32, C33, C34, C35: 100nF; C_0402_1005Metric; LCSC Part # C1525
C27, C29: 1uF; C_0402_1005Metric; LCSC Part # C52923
R1: DNF; R_0402_1005Metric; not fitted
R2, R5: 1k; R_0402_1005Metric; LCSC Part # C11702
R3, R4: 27R; R_0402_1005Metric; LCSC Part # C25100
U1: W25Q128JVS; SOIC-8_5.3x5.3mm_P1.27mm; LCSC Part # C97521
U2: NCP1117-3.3_SOT223; SOT-223-3_TabPin2; LCSC Part # C146799
U3: RP2040; QFN-56-1EP_7x7mm_P0.4mm_EP3.2x3.2mm; LCSC Part # C2040
Y1: ABM8-272-T3; Oscillator_SMD_Abracon_ASE-4Pin_3.2x2.5mm; LCSC Part # C20625731

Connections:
+1V1: C25.1, C26.1, C27.1, U3.23 (DVDD), U3.45 (VREG_VOUT), U3.50 (DVDD)
+3.3V: C23.2, C24.1, C28.1, C29.1, C30.1, C31.1, C32.1, C33.1, C34.1, C35.1, R1.1, U1.8 (VCC), U2.2 (VO), U3.1 (IOVDD), U3.10 (IOVDD), U3.22 (IOVDD), U3.33 (IOVDD), U3.42 (IOVDD), U3.43 (ADC_AVDD), U3.44 (VREG_IN), U3.48 (USB_VDD), U3.49 (IOVDD); also elsewhere on the board
/2040/PI-D+: R3.2, U3.47 (USB_DP)
/2040/PI-D-: R4.2, U3.46 (USB_DM)
/2040/RUN: U3.26 (RUN); also elsewhere on the board
/2040/SWCLK: U3.24 (SWCLK)
/2040/SWDIO: U3.25 (SWD)
/2040/USB_BOOT: R2.2; also elsewhere on the board
/USB-PI-D+: R3.1; also elsewhere on the board
/USB-PI-D-: R4.1; also elsewhere on the board
COL0: U3.2 (GPIO0); also elsewhere on the board
COL1: U3.3 (GPIO1); also elsewhere on the board
COL2: U3.4 (GPIO2); also elsewhere on the board
COL3: U3.5 (GPIO3); also elsewhere on the board
COL4: U3.32 (GPIO21); also elsewhere on the board
COL5: U3.34 (GPIO22); also elsewhere on the board
COL6: U3.35 (GPIO23); also elsewhere on the board
GND: C20.2, C21.1, C22.1, C23.1, C24.2, C25.2, C26.2, C27.2, C28.2, C29.2, C30.2, C31.2, C32.2, C33.2, C34.2, C35.2, U1.4 (GND), U2.1 (GND), U3.19 (TESTEN), U3.57 (GND), Y1.2, Y1.4; also elsewhere on the board
GP24: U3.36 (GPIO24)
GP25: U3.37 (GPIO25)
JOY1_DOWN: U3.14 (GPIO11); also elsewhere on the board
JOY1_LEFT: U3.15 (GPIO12); also elsewhere on the board
JOY1_PADDLEA: U3.38 (GPIO26_ADC0); also elsewhere on the board
JOY1_PADDLEB: U3.39 (GPIO27_ADC1); also elsewhere on the board
JOY1_RIGHT: U3.16 (GPIO13); also elsewhere on the board
JOY1_TRIGGER: U3.17 (GPIO14); also elsewhere on the board
JOY1_UP: U3.13 (GPIO10); also elsewhere on the board
JOY2_DOWN: U3.27 (GPIO16); also elsewhere on the board
JOY2_LEFT: U3.28 (GPIO17); also elsewhere on the board
JOY2_PADDLEA: U3.40 (GPIO28_ADC2); also elsewhere on the board
JOY2_PADDLEB: U3.41 (GPIO29_ADC3); also elsewhere on the board
JOY2_RIGHT: U3.29 (GPIO18); also elsewhere on the board
JOY2_TRIGGER: U3.30 (GPIO19); also elsewhere on the board
JOY2_UP: U3.18 (GPIO15); also elsewhere on the board
unnamed: C22.2, R5.1, Y1.3
unnamed: U1.6 (CLK), U3.52 (QSPI_SCLK)
unnamed: U1.5 (DI(IO0)), U3.53 (QSPI_SD0)
unnamed: U1.2 (DO(IO1)), U3.55 (QSPI_SD1)
unnamed: U1.3 (IO2), U3.54 (QSPI_SD2)
unnamed: U1.7 (IO3), U3.51 (QSPI_SD3)
unnamed: R1.2, R2.1, U1.1 (~CS), U3.56 (QSPI_SS)
unnamed: C21.2, U3.20 (XIN), Y1.1
unnamed: R5.2, U3.21 (XOUT)
RGB: U3.31 (GPIO20); also elsewhere on the board
ROW0: U3.6 (GPIO4); also elsewhere on the board
ROW1: U3.7 (GPIO5); also elsewhere on the board
ROW2: U3.8 (GPIO6); also elsewhere on the board
ROW3: U3.9 (GPIO7); also elsewhere on the board
ROW4: U3.11 (GPIO8); also elsewhere on the board
ROW5: U3.12 (GPIO9); also elsewhere on the board
VBUS: C20.1, U2.3 (VI); also elsewhere on the board



Board: 2 copper layers, 149.1 x 134.5 mm, 179 parts (142 on the bottom side), 125 nets.

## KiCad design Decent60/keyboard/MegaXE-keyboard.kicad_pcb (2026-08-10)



Board: 2 copper layers, 291.8 x 134.6 mm, 359 parts (288 on the bottom side), 202 nets.

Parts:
C4, C6, C7, C8, C9, C10, C11, C12, C13, C42, C75, C76, C77, C78, C79, C80, C81, C82, C83, C84, C85, C86, C87, C88, C89, C90, C91, C92, C93, C94, C95, C96, C97, C98, C99, C100, C101, C102, C103, C104, C105, C106, C107, C108, C109, C110, C111, C112, C113, C114, C115, C116, C117, C118, C119, C120, C121, C123, C124, C125, C126, C127, C128, C129, C130, C131, C132, C133, C134, C135, C136, C137, C138, C139, C140, C141, C142, C143, C144, C145, C146, C147, C148, C149, C150, C151, C152, C153, C154, C155: 100nF; C_0402_1005Metric
C5, C14: 1uF; C_0402_1005Metric
C24, C25: 15pF; C_0402_1005Metric
C27, C28, C43: 10uF; C_0402_1005Metric
D17, D18, D19, D20, D21, D22, D23, D24, D25, D26, D27, D28, D29, D30, D31, D47, D49, D51, D53, D55, D57, D59, D61, D63, D65, D67, D69, D71, D73, D75, D77, D79, D81, D83, D85, D87, D89, D91, D93, D95, D97, D99, D101, D103, D105, D107, D109, D111, D113, D115, D119, D121, D123, D125, D127, D128, D129, D130, D131, D132, D133, D134, D135, D137, D139, D141, D143, D145, D147, D148: 1N4148W; D_SOD-123
D149, D150, D151, D152, D153, D154, D155, D156, D157, D158, D159, D160, D161, D162, D163, D164, D165, D166, D167, D168, D169, D170, D171, D172, D173, D174, D175, D176, D177, D178, D179, D180, D181, D182, D183, D184, D185, D186, D187, D188, D189, D190, D191, D192, D193, D194, D195, D197, D198, D199, D200, D201, D202, D203, D204, D205, D206, D207, D208, D209, D210, D211, D212, D213, D214, D215, D216, D217, D218, D219, D220, D221, D222, D223, D224, D225, D226, D227, D228, D229: SK6812MINI; LED_SK6812MINI-E_3.2x2.8mm_P1.5mm_ReverseMount
H1, H2, H3, H4: MountingHole_Pad; MountingHole_2.2mm_M2_Pad_Via
J1: Conn_01x04_Socket; JST_PH_B4B-PH-K_1x04_P2.00mm_Vertical
J4: Conn_01x04_Pin; PinHeader_1x04_P2.54mm_Vertical
J5: USB_C_Receptacle_USB2.0_16P; USB_C_Receptacle_C2765186
J6: Conn_01x04; PinHeader_1x04_P2.54mm_Vertical
J9: SM03B-SRSS-TB; JST_SH_BM03B-SRSS-TB_1x03-1MP_P1.00mm_Vertical
R6, R7: 5k1; R_0402_1005Metric
R26, R28: 27; R_0402_1005Metric
R30, R31, R32: 1k; R_0402_1005Metric
R36: DNF; R_0402_1005Metric
R37: 0; SolderJumper-2_P1.3mm_Bridged_RoundedPad1.0x1.5mm
SW1: RotaryEncoder_Switch; RotaryEncoder_Alps_EC11E-Switch_Vertical_H20mm
SW2: SW_BOOT_SELECT; TactileSwitch
SW3: SW_RESET; TactileSwitch
SW10, SW11, SW12, SW13, SW14, SW15, SW16, SW17, SW19, SW20, SW21, SW22, SW23, SW24, SW25, SW26, SW27, SW28, SW29, SW30, SW31, SW32, SW33, SW34, SW35, SW36, SW37, SW38, SW39, SW40, SW41, SW42, SW43, SW44, SW45, SW46, SW47, SW48, SW49, SW50, SW51, SW52, SW53, SW54, SW55, SW56, SW57, SW58, SW59, SW61, SW64, SW65, SW66, SW67, SW68, SW70, SW71, SW72, SW73, SW74, SW76, SW77, SW78, SW79, SW80: MX; Kailh_socket_MX_1-00U
SW18: MX; Kailh_socket_MX_6-25U
SW62, SW63, SW69, SW75: MX; Kailh_socket_MX_2-00U
TP1, TP2, TP3, TP4, TP5, TP6, TP7, TP8, TP9, TP10, TP11, TP12, TP13, TP14, TP15, TP16, TP17: TestPoint; TestPoint_THTPad_D1.0mm_Drill0.5mm
U4: NCP1117-3.3; SOT-223-3_TabPin2
U7: RP2040; QFN-56-1EP_7x7mm_P0.4mm_EP3.2x3.2mm
U9: W25Q128JVS; SOIC-8_5.3x5.3mm_P1.27mm
X1: 12MHz; Crystal_SMD_Abracon_ABM8AIG-4Pin_3.2x2.5mm

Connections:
+1V1: C4.1, C5.1, C6.1, U7.23 (DVDD), U7.45 (VREG_VOUT), U7.50 (DVDD)
+3V3: C7.1, C8.1, C9.1, C10.1, C11.1, C12.1, C13.1, C14.1, C27.1, C28.1, C42.1, J1.3, J6.3, R36.1, U4.2 (VO), U7.1 (IOVDD), U7.10 (IOVDD), U7.22 (IOVDD), U7.33 (IOVDD), U7.42 (IOVDD), U7.43 (ADC_AVDD), U7.44 (VREG_IN), U7.48 (USB_VDD), U7.49 (IOVDD), U9.8 (VCC)
/Controller/FLASH_SS: R36.2, R37.2, U9.1 (~CS)
/Controller/QSPI_SCLK: U7.52 (QSPI_SCLK), U9.6 (CLK)
/Controller/QSPI_SD0: U7.53 (QSPI_SD0), U9.5 (DI(IO0))
/Controller/QSPI_SD1: U7.55 (QSPI_SD1), U9.2 (DO(IO1))
/Controller/QSPI_SD2: U7.54 (QSPI_SD2), U9.3 (IO2)
/Controller/QSPI_SD3: U7.51 (QSPI_SD3), U9.7 (IO3)
/Controller/QSPI_SS: R30.1, R37.1, U7.56 (QSPI_SS)
/Controller/SCL: J1.1, J6.2, U7.41 (GPIO29_ADC3)
/Controller/SDA: J1.2, J6.1, U7.40 (GPIO28_ADC2)
/Controller/SWCLK: J9.1, U7.24 (SWCLK)
/Controller/SWD: J9.3, U7.25 (SWD)
/Controller/USB_D+: J4.3, J5.A6 (D+), J5.B6 (D+), R26.1
/Controller/USB_D-: J4.2, J5.A7 (D-), J5.B7 (D-), R28.1
/Controller/USB_DN: R28.2, U7.46 (USB_DM)
/Controller/USB_DP: R26.2, U7.47 (USB_DP)
/Controller/XIN: C24.1, U7.20 (XIN), X1.1
/Controller/XOUT: R31.2, U7.21 (XOUT)
/Controller/~USB_BOOT: R30.2, SW2.2
/Key0/RGB_IN: D169.4 (DOUT), D178.2 (DIN)
/Key0/RGB_OUT: D178.4 (DOUT), D185.2 (DIN)
/Key1/RGB_IN: D193.2 (DIN), D201.4 (DOUT)
/Key1/RGB_OUT: D186.2 (DIN), D193.4 (DOUT)
/Key2/RGB_OUT: D177.2 (DIN), D186.4 (DOUT)
/Key3/RGB_OUT: D170.2 (DIN), D177.4 (DOUT)
/Key4/RGB_OUT: D167.2 (DIN), D170.4 (DOUT)
/Key5/RGB_OUT: D151.2 (DIN), D167.4 (DOUT)
/Key6/RGB_OUT: D150.2 (DIN), D151.4 (DOUT)
/Key7/RGB_OUT: D150.4 (DOUT), D168.2 (DIN)
/Key8/RGB_OUT: D168.4 (DOUT), D169.2 (DIN)
/KeyA/RGB_IN: D197.2 (DIN), D202.4 (DOUT)
/KeyA/RGB_OUT: D188.2 (DIN), D197.4 (DOUT)
/KeyAlt/RGB_IN: D198.4 (DOUT), D227.2 (DIN)
/KeyAlt/RGB_OUT: D221.2 (DIN), D227.4 (DOUT)
/KeyB/RGB_IN: D155.4 (DOUT), D161.2 (DIN)
/KeyB/RGB_OUT: D161.4 (DOUT), D176.2 (DIN)
/KeyBackslash/RGB_IN: D204.4 (DOUT), D229.2 (DIN)
/KeyBackslash/RGB_OUT: D194.2 (DIN), D229.4 (DOUT)
/KeyBreak/RGB_IN: D210.2 (DIN), D226.4 (DOUT)
/KeyBreak/RGB_OUT: D210.4 (DOUT), D225.2 (DIN)
/KeyC/RGB_IN: D176.4 (DOUT), D184.2 (DIN)
/KeyC/RGB_OUT: D184.4 (DOUT), D187.2 (DIN)
/KeyCaps/RGB_IN: D202.2 (DIN), D206.4 (DOUT)
/KeyComma/RGB_IN: D175.2 (DIN), D179.4 (DOUT)
/KeyComma/RGB_OUT: D162.2 (DIN), D175.4 (DOUT)
/KeyControl/RGB_IN: D205.2 (DIN), D209.4 (DOUT)
/KeyControl/RGB_OUT: D198.2 (DIN), D205.4 (DOUT)
/KeyD/RGB_IN: D181.2 (DIN), D188.4 (DOUT)
/KeyD/RGB_OUT: D174.2 (DIN), D181.4 (DOUT)
/KeyDelete/RGB_IN: D195.4 (DOUT), D204.2 (DIN)
/KeyE/RGB_IN: D172.4 (DOUT), D183.2 (DIN)
/KeyE/RGB_OUT: D183.4 (DOUT), D189.2 (DIN)
/KeyEqual/RGB_IN: D185.4 (DOUT), D195.2 (DIN)
/KeyEsc/RGB_IN: D201.2 (DIN), D211.4 (DOUT)
/KeyF1/RGB_IN: D149.4 (DOUT), D154.2 (DIN)
/KeyF1/RGB_OUT: D154.4 (DOUT), D207.2 (DIN)
/KeyF2/RGB_OUT: D159.2 (DIN), D207.4 (DOUT)
/KeyF3/RGB_OUT: D159.4 (DOUT), D208.2 (DIN)
/KeyF4/RGB_OUT: D160.2 (DIN), D208.4 (DOUT)
/KeyF/RGB_OUT: D163.2 (DIN), D174.4 (DOUT)
/KeyFn/RGB_IN: D226.2 (DIN), D228.4 (DOUT)
/KeyG/RGB_OUT: D157.2 (DIN), D163.4 (DOUT)
/KeyH/RGB_OUT: D156.2 (DIN), D157.4 (DOUT)
/KeyHelp/RGB_OUT: D160.4 (DOUT), D214.2 (DIN)
/KeyI/RGB_IN: D166.2 (DIN), D171.4 (DOUT)
/KeyI/RGB_OUT: D152.2 (DIN), D166.4 (DOUT)
/KeyJ/RGB_OUT: D156.4 (DOUT), D164.2 (DIN)
/KeyK/RGB_OUT: D164.4 (DOUT), D173.2 (DIN)
/KeyL/RGB_OUT: D173.4 (DOUT), D182.2 (DIN)
/KeyLeftBracket/RGB_IN: D190.2 (DIN), D194.4 (DOUT)
/KeyLeftBracket/RGB_OUT: D180.2 (DIN), D190.4 (DOUT)
/KeyLeftShift/RGB_IN: D200.4 (DOUT), D209.2 (DIN)
/KeyM/RGB_OUT: D155.2 (DIN), D162.4 (DOUT)
/KeyO/RGB_IN: D171.2 (DIN), D180.4 (DOUT)
/KeyOption/RGB_IN: D212.2 (DIN), D213.4 (DOUT)
/KeyOption/RGB_OUT: D211.2 (DIN), D212.4 (DOUT)
/KeyPeriod/RGB_IN: D179.2 (DIN), D191.4 (DOUT)
/KeyQ/RGB_IN: D189.4 (DOUT), D199.2 (DIN)
/KeyQ/RGB_OUT: D199.4 (DOUT), D206.2 (DIN)
/KeyQuote/RGB_IN: D182.4 (DOUT), D192.2 (DIN)
/KeyQuote/RGB_OUT: D192.4 (DOUT), D203.2 (DIN)
/KeyR/RGB_IN: D165.4 (DOUT), D172.2 (DIN)
/KeyReturn/RGB_OUT: D203.4 (DOUT), D215.2 (DIN)
/KeyRightAlt/RGB_IN: D224.4 (DOUT), D228.2 (DIN)
/KeyRightShift/RGB_OUT: D191.2 (DIN), D215.4 (DOUT)
/KeySelect/RGB_IN: D213.2 (DIN), D214.4 (DOUT)
/KeySpace/RGB_IN: D158.2 (DIN), D222.4 (DOUT)
/KeySpace/RGB_OUT: D158.4 (DOUT), D223.2 (DIN)
/KeyT/RGB_IN: D153.4 (DOUT), D165.2 (DIN)
/KeyU/RGB_OUT: D152.4 (DOUT), D153.2 (DIN)
/KeyX/RGB_OUT: D187.4 (DOUT), D200.2 (DIN)
/Logo1/RGB_OUT: D216.4 (DOUT), D217.2 (DIN)
/Logo2/RGB_OUT: D217.4 (DOUT), D218.2 (DIN)
/Logo3/RGB_OUT: D218.4 (DOUT), D219.2 (DIN)
/Logo4/RGB_OUT: D219.4 (DOUT), D220.2 (DIN)
/Logo5/RGB_OUT: D149.2 (DIN), D220.4 (DOUT)
/Space1/RGB_OUT: D221.4 (DOUT), D222.2 (DIN)
/Space3/RGB_OUT: D223.4 (DOUT), D224.2 (DIN)
COL_1: SW10.1, SW11.1, SW12.1, SW13.1, SW14.1, SW15.1, SW19.1, TP1.1 (1_1), U7.11 (GPIO8)
COL_2: SW16.1, SW17.1, SW18.1, SW20.1, TP2.1 (1_1), U7.12 (GPIO9)
COL_3: SW21.1, SW22.1, SW23.1, SW24.1, SW25.1, SW26.1, SW27.1, SW28.1, TP3.1 (1_1), U7.13 (GPIO10)
COL_4: SW29.1, SW30.1, SW31.1, SW32.1, SW33.1, SW34.1, SW35.1, SW36.1, TP4.1 (1_1), U7.14 (GPIO11)
COL_5: SW37.1, SW38.1, SW39.1, SW40.1, SW41.1, SW42.1, SW43.1, SW44.1, TP5.1 (1_1), U7.15 (GPIO12)
COL_6: SW45.1, SW46.1, SW47.1, SW48.1, SW49.1, SW50.1, SW51.1, SW52.1, TP6.1 (1_1), U7.16 (GPIO13)
COL_7: SW53.1, SW54.1, SW55.1, SW56.1, SW57.1, SW58.1, SW59.1, TP7.1 (1_1), U7.17 (GPIO14)
COL_8: SW61.1, SW62.1, SW63.1, SW64.1, SW65.1, SW67.1, SW68.1, SW80.1, TP8.1 (1_1), U7.18 (GPIO15)
COL_9: SW66.1, SW69.1, SW70.1, SW75.1, SW76.1, SW77.1, SW78.1, SW79.1, TP9.1 (1_1), U7.27 (GPIO16)
CONSOLE: SW71.1, SW72.1, SW73.1, SW74.1, U7.28 (GPIO17)
EncoderA: SW1.A, U7.37 (GPIO25)
EncoderB: SW1.B, U7.36 (GPIO24)
EncoderSwitch: SW1.S1, U7.35 (GPIO23)
GND: C4.2, C5.2, C6.2, C7.2, C8.2, C9.2, C10.2, C11.2, C12.2, C13.2, C14.2, C24.2, C25.1, C27.2, C28.2, C42.2, C43.1, C75.2, C76.2, C77.2, C78.2, C79.2, C80.2, C81.2, C82.2, C83.2, C84.2, C85.2, C86.2, C87.2, C88.2, C89.2, C90.2, C91.2, C92.2, C93.2, C94.2, C95.2, C96.2, C97.2, C98.2, C99.2, C100.2, C101.2, C102.2, C103.2, C104.2, C105.2, C106.2, C107.2, C108.2, C109.2, C110.2, C111.2, C112.2, C113.2, C114.2, C115.2, C116.2, C117.2, C118.2, C119.2, C120.2, C121.2, C123.2, C124.2, C125.2, C126.2, C127.2, C128.2, C129.2, C130.2, C131.2, C132.2, C133.2, C134.2, C135.2, C136.2, C137.2, C138.2, C139.2, C140.2, C141.2, C142.2, C143.2, C144.2, C145.2, C146.2, C147.2, C148.2, C149.2, C150.2, C151.2, C152.2, C153.2, C154.2, C155.2, D149.1 (VSS), D150.1 (VSS), D151.1 (VSS), D152.1 (VSS), D153.1 (VSS), D154.1 (VSS), D155.1 (VSS), D156.1 (VSS), D157.1 (VSS), D158.1 (VSS), D159.1 (VSS), D160.1 (VSS), D161.1 (VSS), D162.1 (VSS), D163.1 (VSS), D164.1 (VSS), D165.1 (VSS), D166.1 (VSS), D167.1 (VSS), D168.1 (VSS), D169.1 (VSS), D170.1 (VSS), D171.1 (VSS), D172.1 (VSS), D173.1 (VSS), D174.1 (VSS), D175.1 (VSS), D176.1 (VSS), D177.1 (VSS), D178.1 (VSS), D179.1 (VSS), D180.1 (VSS), D181.1 (VSS), D182.1 (VSS), D183.1 (VSS), D184.1 (VSS), D185.1 (VSS), D186.1 (VSS), D187.1 (VSS), D188.1 (VSS), D189.1 (VSS), D190.1 (VSS), D191.1 (VSS), D192.1 (VSS), D193.1 (VSS), D194.1 (VSS), D195.1 (VSS), D197.1 (VSS), D198.1 (VSS), D199.1 (VSS), D200.1 (VSS), D201.1 (VSS), D202.1 (VSS), D203.1 (VSS), D204.1 (VSS), D205.1 (VSS), D206.1 (VSS), D207.1 (VSS), D208.1 (VSS), D209.1 (VSS), D210.1 (VSS), D211.1 (VSS), D212.1 (VSS), D213.1 (VSS), D214.1 (VSS), D215.1 (VSS), D216.1 (VSS), D217.1 (VSS), D218.1 (VSS), D219.1 (VSS), D220.1 (VSS), D221.1 (VSS), D222.1 (VSS), D223.1 (VSS), D224.1 (VSS), D225.1 (VSS), D226.1 (VSS), D227.1 (VSS), D228.1 (VSS), D229.1 (VSS), H1.1 (1_1), H2.1 (1_1), H3.1 (1_1), H4.1 (1_1), J1.4, J4.4, J5.A1 (GND), J5.A12 (GND), J5.B1 (GND), J5.B12 (GND), J5.S1 (SHIELD), J6.4, J9.2, J9.MP (MountPin), R6.2, R7.2, SW1.C, SW1.MP, SW1.S2, SW2.1, SW3.1, U4.1 (GND), U7.19 (TESTEN), U7.57 (GND), U9.4 (GND), X1.2, X1.4
unnamed: C25.2, R31.1, X1.3
unnamed: D17.2 (A), SW10.2
unnamed: D18.2 (A), SW11.2
unnamed: D19.2 (A), SW12.2
unnamed: D20.2 (A), SW13.2
unnamed: D21.2 (A), SW14.2
unnamed: D22.2 (A), SW15.2
unnamed: D23.2 (A), SW16.2
unnamed: D24.2 (A), SW17.2
unnamed: D25.2 (A), SW18.2
unnamed: D26.2 (A), SW19.2
unnamed: D27.2 (A), SW20.2
unnamed: D28.2 (A), SW21.2
unnamed: D29.2 (A), SW22.2
unnamed: D30.2 (A), SW23.2
unnamed: D31.2 (A), SW24.2
unnamed: D47.2 (A), SW25.2
unnamed: D49.2 (A), SW26.2
unnamed: D51.2 (A), SW27.2
unnamed: D53.2 (A), SW28.2
unnamed: D55.2 (A), SW29.2
unnamed: D57.2 (A), SW30.2
unnamed: D59.2 (A), SW31.2
unnamed: D61.2 (A), SW32.2
unnamed: D63.2 (A), SW33.2
unnamed: D65.2 (A), SW34.2
unnamed: D67.2 (A), SW35.2
unnamed: D69.2 (A), SW36.2
unnamed: D71.2 (A), SW37.2
unnamed: D73.2 (A), SW38.2
unnamed: D75.2 (A), SW39.2
unnamed: D77.2 (A), SW40.2
unnamed: D79.2 (A), SW41.2
unnamed: D81.2 (A), SW42.2
unnamed: D83.2 (A), SW43.2
unnamed: D85.2 (A), SW44.2
unnamed: D87.2 (A), SW45.2
unnamed: D89.2 (A), SW46.2
unnamed: D91.2 (A), SW47.2
unnamed: D93.2 (A), SW48.2
unnamed: D95.2 (A), SW49.2
unnamed: D97.2 (A), SW50.2
unnamed: D99.2 (A), SW51.2
unnamed: D101.2 (A), SW52.2
unnamed: D103.2 (A), SW53.2
unnamed: D105.2 (A), SW54.2
unnamed: D107.2 (A), SW55.2
unnamed: D109.2 (A), SW56.2
unnamed: D111.2 (A), SW57.2
unnamed: D113.2 (A), SW58.2
unnamed: D115.2 (A), SW59.2
unnamed: D119.2 (A), SW61.2
unnamed: D121.2 (A), SW62.2
unnamed: D123.2 (A), SW63.2
unnamed: D125.2 (A), SW64.2
unnamed: D127.2 (A), SW65.2
unnamed: D128.2 (A), SW80.2
unnamed: D129.2 (A), SW66.2
unnamed: D130.2 (A), SW76.2
unnamed: D131.2 (A), SW67.2
unnamed: D132.2 (A), SW78.2
unnamed: D133.2 (A), SW68.2
unnamed: D134.2 (A), SW79.2
unnamed: D135.2 (A), SW69.2
unnamed: D137.2 (A), SW70.2
unnamed: D139.2 (A), SW71.2
unnamed: D141.2 (A), SW72.2
unnamed: D143.2 (A), SW73.2
unnamed: D145.2 (A), SW74.2
unnamed: D147.2 (A), SW75.2
unnamed: D148.2 (A), SW77.2
unnamed: J5.A5 (CC1), R7.1
unnamed: J5.B5 (CC2), R6.1
unnamed: R32.2, SW3.2
unnamed: R32.1, U7.26 (RUN)
OPTION: D141.1 (K), U7.30 (GPIO19)
RESET: D139.1 (K), U7.29 (GPIO18)
RGB: D216.2 (DIN), U7.38 (GPIO26_ADC0)
ROW_1: D17.1 (K), D53.1 (K), D55.1 (K), D71.1 (K), D89.1 (K), D103.1 (K), D123.1 (K), D137.1 (K), TP10.1 (1_1), U7.2 (GPIO0)
ROW_2: D18.1 (K), D51.1 (K), D57.1 (K), D73.1 (K), D87.1 (K), D105.1 (K), D119.1 (K), D130.1 (K), TP11.1 (1_1), U7.3 (GPIO1)
ROW_3: D19.1 (K), D49.1 (K), D59.1 (K), D75.1 (K), D93.1 (K), D113.1 (K), D121.1 (K), D134.1 (K), TP12.1 (1_1), U7.4 (GPIO2)
ROW_4: D20.1 (K), D47.1 (K), D61.1 (K), D77.1 (K), D99.1 (K), D111.1 (K), D131.1 (K), D148.1 (K), TP13.1 (1_1), U7.5 (GPIO3)
ROW_5: D21.1 (K), D23.1 (K), D31.1 (K), D63.1 (K), D79.1 (K), D97.1 (K), D125.1 (K), D129.1 (K), TP14.1 (1_1), U7.6 (GPIO4)
ROW_6: D24.1 (K), D30.1 (K), D65.1 (K), D81.1 (K), D95.1 (K), D109.1 (K), D127.1 (K), D132.1 (K), TP15.1 (1_1), U7.7 (GPIO5)
ROW_7: D22.1 (K), D25.1 (K), D29.1 (K), D67.1 (K), D83.1 (K), D91.1 (K), D115.1 (K), D128.1 (K), D147.1 (K), TP16.1 (1_1), U7.8 (GPIO6)
ROW_8: D26.1 (K), D27.1 (K), D28.1 (K), D69.1 (K), D85.1 (K), D101.1 (K), D107.1 (K), D133.1 (K), D135.1 (K), TP17.1 (1_1), U7.9 (GPIO7)
SELECT: D143.1 (K), U7.31 (GPIO20)
START: D145.1 (K), U7.32 (GPIO21)
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

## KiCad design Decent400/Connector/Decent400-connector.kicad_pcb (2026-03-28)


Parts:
J1: Conn_01x22; PinHeader_1x22_P2.54mm_Vertical
J2: Conn_01x02; PinHeader_1x02_P2.54mm_Vertical
J3: Conn_02x12_Odd_Even_MountingPin; IDC-Header_2x12_P2.54mm_Vertical

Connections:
unnamed: J1.1, J3.1
unnamed: J1.2, J3.2
unnamed: J1.3, J3.3
unnamed: J1.4, J3.4
unnamed: J1.5, J3.5
unnamed: J1.6, J3.6
unnamed: J1.7, J3.7
unnamed: J1.8, J3.8
unnamed: J1.9, J3.9
unnamed: J1.10, J3.10
unnamed: J1.11, J3.11
unnamed: J1.12, J3.12
unnamed: J1.13, J3.13
unnamed: J1.14, J3.14
unnamed: J1.15, J3.15
unnamed: J1.16, J3.16
unnamed: J1.17, J3.17
unnamed: J1.18, J3.18
unnamed: J1.19, J3.19
unnamed: J1.20, J3.20
unnamed: J1.21, J3.21
unnamed: J1.22, J3.22
unnamed: J2.1, J3.23
unnamed: J2.2, J3.24


Board: 2 copper layers, 14.7 x 57.9 mm, 3 parts (0 on the bottom side), 24 nets.

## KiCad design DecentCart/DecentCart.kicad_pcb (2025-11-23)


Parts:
BT1: Battery_Cell; BAT-SMD_BS-CR2032-8; JLCPCB Part # C70377
C1, C4, C6, C7, C8, C9, C10, C11, C12, C13, C14, C15, C16: 100nF; C_0402_1005Metric; JLCPCB Part # C1525
C5, C20: 4.7uF; C_0402_1005Metric; JLCPCB Part # C23733
C21, C22: 4.7uF; C_0603_1608Metric; JLCPCB Part # C19666
C23, C26, C27, C28: 10uF; C_0402_1005Metric; JLCPCB Part # C15525
C24, C25: 15pF; C_0402_1005Metric; JLCPCB Part # C1548
D1: MBR120VLSFT1G; Nexperia_CFP3_SOD-123W; JLCPCB Part # C8598
D2: LED; D_0805_2012Metric; JLCPCB Part # C2297
H2: MountingHole; MountingHole_2.2mm_M2; not fitted
J1: Micro_SD_Card; TF-SMD_TF-PUSH; JLCPCB Part # C393941
J2: Conn_02x15_Row_Letter_First; Atari Cartridge Edge Connector
J3: Conn_02x07_Row_Letter_First; IDC-SMD_14P-P1.27_HXJN1.27-14P_ATARI_ECI; JLCPCB Part # C42455944
J4: Conn_01x04_Socket; CONN-SMD_4P-P1.00_SM04B-SRSS-TB-LF-SN; JLCPCB Part # C160404
J5: USB_C_Receptacle_USB2.0_16P; USB-C-SMD_TYPE-C-6PIN-2MD-073; JLCPCB Part # C2765186
J7: Conn_01x08; PinHeader_1x08_P2.54mm_Vertical
J9: SM03B-SRSS-TB; JST_SH_SM03B-SRSS-TB_1x03-1MP_P1.00mm_Horizontal; JLCPCB Part # C160389
L16: 3.3uH; IND-SMD_L2.0-W1.6_AOTA-B201610S3R3-101-T; JLCPCB Part # C42411119
Q1: PNP; SOT-23; JLCPCB Part # C8542
Q2: DMG2305UX; SOT-23; JLCPCB Part # C150470
R1: 470; R_0402_1005Metric; JLCPCB Part # C25117
R2, R3: 10k; R_0402_1005Metric; JLCPCB Part # C25744
R4, R5, R6, R7, R8, R9: 47k; R_0402_1005Metric; JLCPCB Part # C25792
R25: 33; R_0402_1005Metric; JLCPCB Part # C25105
R26, R28: 27; R_0805_2012Metric; JLCPCB Part # C17561
R30, R31, R32: 1k; R_0402_1005Metric; JLCPCB Part # C11702
R34: 220; R_0402_1005Metric; JLCPCB Part # C25091
R41, R42: 5k1; R_0402_1005Metric; JLCPCB Part # C25905
SW2, SW3: SW_TACTILE; Tactile_Switch_Basic_XKB_TS-1187A; JLCPCB Part # C318884
U1: Raspberry Pi RM2; rpi_rmc20452t; JLCPCB Part # C49451547
U2: DS3231MZ; SOIC-8_3.9x4.9mm_P1.27mm; JLCPCB Part # C107410
U3: RP2354B_80QFN; QFN-80_L10.0-W10.0-P0.40-TL-EP3.4; JLCPCB Part # C39843328
U4: NCP1117-3.3_SOT223; SOT-223-3_TabPin2; JLCPCB Part # C6186
X1: 12MHz; Crystal_SMD_Abracon_ABM8AIG-4Pin_3.2x2.5mm; JLCPCB Part # C20625731

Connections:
+1V1: C4.1, C5.1, C6.1, C22.1, L16.2, U3.10 (DVDD), U3.32 (DVDD), U3.51 (DVDD), U3.65 (VREG_FB)
+3V3: C1.1, C7.1, C8.1, C9.1, C10.1, C11.1, C12.1, C13.1, C14.1, C15.1, C16.2, C21.1, C23.2, C27.1, C28.1, D2.2 (A), J1.4 (VDD), J4.3, J7.2, J7.8, R2.2, R4.1, R5.1, R6.1, R7.1, R8.1, R9.1, R25.1, U1.14 (VDDIO), U1.16 (VIN), U2.2 (VCC), U3.5 (IOVDD), U3.15 (IOVDD), U3.24 (IOVDD), U3.29 (IOVDD), U3.41 (IOVDD), U3.50 (IOVDD), U3.59 (ADC_AVDD), U3.60 (IOVDD), U3.64 (VREG_VIN), U3.68 (USB_OTP_VDD), U3.69 (QSPI_IOVDD), U3.76 (IOVDD), U4.2 (VO)
+5V: J2.13, J3.7, Q2.3 (D)
/QSPI_SS: R30.1, U3.75 (QSPI_SS)
/SWCLK: J9.1, U3.33 (SWCLK)
/SWD: J9.3, U3.34 (SWD)
/USB+: R26.2, U3.67 (USB_DP)
/USB-: R28.2, U3.66 (USB_DM)
/VBUS: D1.2 (A), J5.2 (VBUS), J5.11 (VBUS), Q2.2 (G)
/VREG_AVDD: C20.1, R25.2, U3.61 (VREG_AVDD)
/VREG_LX: L16.1, U3.63 (VREG_LX)
/XIN: C24.1, U3.30 (XIN), X1.1
/XOUT: R31.2, U3.31 (XOUT)
/~USB_BOOT: R30.2, SW2.2
A0: J2.5, U3.77 (GPIO0)
A1: J2.4, U3.78 (GPIO1)
A2: J2.3, U3.79 (GPIO2)
A3: J2.2, U3.80 (GPIO3)
A4: J2.C, U3.1 (GPIO4)
A5: J2.D, U3.2 (GPIO5)
A6: J2.E, U3.3 (GPIO6)
A7: J2.F, U3.4 (GPIO7)
A8: J2.H, U3.6 (GPIO8)
A9: J2.J, U3.7 (GPIO9)
A10: J2.P, U3.8 (GPIO10)
A11: J2.N, U3.9 (GPIO11)
A12: J2.K, U3.11 (GPIO12)
A13: J3.D, U3.12 (GPIO13)
A14: J3.E, U3.13 (GPIO14)
A15: J3.F, U3.14 (GPIO15)
Audio in: J3.5
D0: J2.10, U3.40 (GPIO32)
D1: J2.9, U3.42 (GPIO33)
D1xx: J3.3, U3.27 (GPIO26)
D2: J2.8, U3.43 (GPIO34)
D3: J2.L, U3.44 (GPIO35)
D4: J2.6, U3.45 (GPIO36)
D5: J2.7, U3.46 (GPIO37)
D6: J2.11, U3.47 (GPIO38)
D7: J2.M, U3.48 (GPIO39)
DISP_CMD: J7.6, U3.53 (GPIO42_ADC2)
DISP_CS: J7.7, U3.54 (GPIO43_ADC3)
DISP_RST: J7.5
GND: BT1.2 (-), C1.2, C4.2, C5.2, C6.2, C7.2, C8.2, C9.2, C10.2, C11.2, C12.2, C13.2, C14.2, C15.2, C16.1, C20.2, C21.2, C22.2, C23.1, C24.2, C25.1, C26.2, C27.2, C28.2, J1.6 (VSS), J1.10 (SHIELD), J2.B, J3.H, J4.4, J5.1 (GND), J5.12 (GND), J5.13 (SHELL), J5.14 (SHELL), J7.1, J9.2, J9.MP (MountPin), Q1.1 (C), R41.1, R42.1, SW2.1, SW3.2, U1.1 (GND), U1.4 (GND), U1.7 (GND), U1.11 (GND), U1.15 (GND), U1.21 (GND), U2.5 (GND), U3.62 (VREG_PGND), U3.81 (GND), U4.1 (GND), X1.2, X1.4
GPIO16: J2.1, U3.16 (GPIO16)
GPIO17: J2.12, U3.17 (GPIO17)
GPIO18: J2.15, U3.18 (GPIO18)
GPIO19: J2.R, U3.19 (GPIO19)
GPIO20: J2.S, U3.20 (GPIO20)
GPIO21: J3.2, U3.21 (GPIO21)
GPIO22: J3.C, U3.22 (GPIO22)
GPIO23: U1.12 (WL_ON), U1.13 (BT_ON), U3.23 (GPIO23)
GPIO24: R1.2, R3.2, U1.5 (DI), U3.25 (GPIO24)
GPIO25: U1.9 (CS), U3.26 (GPIO25)
GPIO27: J2.A, U3.28 (GPIO27)
GPIO28: J2.14, U3.36 (GPIO28)
GPIO29: U1.3 (SCLK), U3.37 (GPIO29)
GPIO30: J3.B, U3.38 (GPIO30)
GPIO31: J3.1, U3.39 (GPIO31)
I2C_CLK: J4.1, U2.8 (SCL), U3.52 (GPIO41_ADC1)
I2C_DATA: J4.2, U2.7 (SDA), U3.49 (GPIO40_ADC0)
unnamed: BT1.1 (+), U2.6 (VBAT)
unnamed: C25.2, R31.1, X1.3
unnamed: C26.1, D1.1 (K), Q2.1 (S), U4.3 (VI)
unnamed: D2.1 (K), R34.2
unnamed: J1.8 (DAT1), R9.2
unnamed: J1.1 (DAT2), R4.2
unnamed: J5.4 (CC1), R41.2
unnamed: J5.10 (CC2), R42.2
unnamed: Q1.3 (E), R34.1
unnamed: R32.2, SW3.1
unnamed: R1.1, U1.6 (DO)
unnamed: R3.1, U1.10 (nIRQ)
unnamed: R2.1, U2.1 (32KHZ)
unnamed: R32.1, U3.35 (RUN)
REF: J3.6, U1.18 (GPIO1)
Reserved: J3.A
SD_CS: J1.2 (DAT3/CD), Q1.2 (B), R5.2, U3.56 (GPIO45_ADC5)
SD_DETECT: J1.9 (DET), U1.8 (GPIO0)
SPI RX: J1.7 (DAT0), R8.2, U3.55 (GPIO44_ADC4)
SPI SCK: J1.5 (CLK), J7.3, R7.2, U3.57 (GPIO46_ADC6)
SPI TX: J1.3 (CMD), J7.4, R6.2, U3.58 (GPIO47_ADC7)
USB_D+: J5.6 (DP1), J5.8 (DP2), R26.1
USB_D-: J5.5 (DN2), J5.7 (DN1), R28.1
WL_GPIO2: J3.4, U1.17 (GPIO2)

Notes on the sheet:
Clock
A10
SPI_SCK
XE PBI (cart + ECI)
SPI_TX
Display Reset
A14
ATARI
Display command
WL_CS
Display
Address bus
Data bus
Display_CS
D1xx
Power
SD_CS
WL_REG_ON
WL_SPI_CLK
Inputs
Wireless
A12
Make sure R7 and R8 are close to RP2350
/CCTL
Data
Display_Command
Display SPI SCK
RD4
JST Debug Connector
Outputs
/IRQ
Phi2
I2C0_SDA
Display SPI TX
I2C0_SCL
A15
WL_DATA
R/W
SPI_RX
A13


Board: 2 copper layers, 59.3 x 73.0 mm, 62 parts (1 on the bottom side), 82 nets.

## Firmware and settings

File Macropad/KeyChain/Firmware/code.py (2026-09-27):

import os
import math
import random
import time
import board
import digitalio
import neopixel
import usb_hid
import adafruit_logging
from adafruit_debouncer import Debouncer
from adafruit_hid.keyboard import Keyboard
from adafruit_hid.keyboard_layout_us import KeyboardLayoutUS as KeyboardLayout
from rainbowio import colorwheel

logger = adafruit_logging.getLogger("log")
logger.setLevel(adafruit_logging.ERROR)
logger.info("Starting up")

class Mode():
    SIMON = 0
    MACROPAD = 1

mode = Mode.SIMON

class Color():
    RED = 0xFF0000
    GREEN = 0x00FF00
    BLUE = 0x0000FF
    YELLOW = 0xFFFF00
    ORANGE = 0xFF8000
    WHITE = 0xFFFFFF
    BLACK = 0x000000

led_intensity = float(os.getenv("INTENSITY"))

pixels = neopixel.NeoPixel(board.GP4, 4)
coordinates = [[-1, -1], [-1, 1], [1, -1], [1, 1]]

def modulate(color, intensity):
    intensity = max(0, min(1, intensity))
    red = math.ceil(((color & 0xFF0000) >> 16) * intensity)
    green = math.ceil(((color & 0xFF00) >> 8) * intensity)
    blue = math.ceil((color & 0xFF) * intensity)
    return (red << 16) | (green << 8) | blue

def addWithinRange(initialValue, addedValue, lowerBound, upperBound):
    return max(lowerBound, min(upperBound , initialValue + addedValue))

def combine_colors(color1, color2):
    return color1 if color2 == 0 else color2 if color1 == 0 else \
        addWithinRange(color1 & 0xFF, color2 & 0xFF, 0, 0xFF) + \
        (addWithinRange((color1 & 0xFF00) >> 8, (color2 & 0xFF00) >> 8, 0, 0xFF) << 8) + \
        (addWithinRange((color1 & 0xFF0000) >> 16, (color2 & 0xFF0000) >> 16, 0, 0xFF) << 16)

def display_solid(color):
    for i in range(4):
        pixels[i] = modulate(color, led_intensity)
    pixels.show()


class Animation():
    def __init__(self):
        self.frame_number = 0
    def define_done_callback(self, done_callback):
        self.done_callback = done_callback
    def loop(self):
        self.frame_number = self.frame_number + 1
    def display_frame(self):
        for i, [x, y] in enumerate(coordinates):
             pixels[i] = self.paint(x, y, i)
        pixels.show()
    def paint(self, x, y, i):
        return 0
    def done(self):
        if self.done_callback != None:
            self.done_callback(self)

class BeachBall(Animation):
    def paint(self, x, y, i):
        return modulate(colorwheel((math.atan2(y, x) * 128 / math.pi - self.frame_number) % 256), led_intensity)

class FlashAndFade(Animation):
    def __init__(self, led_index, color, duration):
        super().__init__()
        self.led_index = led_index
        self.color = color
        self.duration = self.count = duration
    def loop(self):
        self.count = max(0, self.count - 1)
        if (self.count == 0):
            self.done()
        super().loop()
    def paint(self, x, y, i):
        return modulate(modulate(self.color, self.count / self.duration), led_intensity) if self.led_index == i else 0

class CompositeAnimation(Animation):
    def __init__(self):
        super().__init__()
        self.animations = []
    def add(self, animation):
        self.animations.append(animation)
        def callback(anim):
            if anim in self.animations:
                self.animations.remove(anim)
        animation.define_done_callback(callback)
    def loop(self):
        for animation in self.animations:
            animation.loop()
        super().loop()
    def paint(self, x, y, i):
        color = super().paint(x, y, i)
        colors = [color]
        for animation in self.animations:
            animationColor = animation.paint(x, y, i)
            color = combine_colors(color, animationColor)
            colors.append(animationColor)
        if (len(self.animations) > 1):
            logger.info(f"Composite color {i} {colors} = {color}")
        return color

MSGS = [os.getenv("KEY" + str(i + 1)) for i in range(4)]

def setup_key(pin):
    KEY_GPIO = digitalio.DigitalInOut(pin)
    KEY_GPIO.direction = digitalio.Direction.INPUT
    KEY_GPIO.pull = digitalio.Pull.UP
    return KEY_GPIO

KEYS = [Debouncer(setup_key(getattr(board, "GP" + str(i)))) for i in range(4)]

def wait_for_no_keys():
    keys_pressed = True
    while keys_pressed:
        keys_pressed = False
        for key in KEYS:
            key.update()
            if not key.value:
                keys_pressed = True
                break

display_solid(Color.WHITE)

keyboard_found = False

for device in usb_hid.devices:
    if device.usage_page == 1 and device.usage == 6:
        keyboard_found = True
        logger.info("Keyboard found")
        pixels[0] = Color.GREEN
        pixels.show()

if (keyboard_found):
    try:
        kb = Keyboard(usb_hid.devices, 2)
        display_solid(Color.BLUE)
        layout = KeyboardLayout(kb)
        mode = Mode.MACROPAD
        display_solid(Color.GREEN)
    except ValueError:
        logger.error("Keyboard not found")
        display_solid(Color.ORANGE)
    except OSError:
        logger.error("USB not connected")
        display_solid(Color.RED)

class SimonMode():
    PROMPT = 0
    GUESS = 1
    NEW_PROMPT = 2

while True:
    if mode == Mode.SIMON:
        colors = [(0, Color.RED), (1, Color.GREEN), (2, Color.YELLOW), (3, Color.BLUE)]
        for prompt_led, prompt_color in colors:
            pixels[prompt_led] = prompt_color
        pixels.show()

        simon_state = SimonMode.NEW_PROMPT
        simon_prompt = []
        simon_prompt_length = 3
        simon_prompt_delay_color_display = 1000 #ms
        simon_prompt_delay_between_colors = 100 #ms

        while mode == Mode.SIMON:
            if simon_state == SimonMode.NEW_PROMPT:
                logger.info("Simon new prompt mode")
                time.sleep(1)
                simon_prompt = [random.choice(colors) for i in range(simon_prompt_length)]
                simon_state = SimonMode.PROMPT
            elif simon_state == SimonMode.PROMPT:
                logger.info("Simon prompt mode")
                for prompt_led, prompt_color in simon_prompt:
                    for led, color in colors:
                        pixels[led] = prompt_color if prompt_led == led else Color.BLACK
                    pixels.show()
                    time.sleep(simon_prompt_delay_color_display / 1000)
                    display_solid(Color.BLACK)
                    time.sleep(simon_prompt_delay_between_colors / 1000)
                simon_state = SimonMode.GUESS
            elif simon_state == SimonMode.GUESS:
                logger.info("Simon guess mode")
                display_solid(Color.BLACK)
                correct = False
                for (prompted_index, prompted_color) in simon_prompt:
                    guessed = False
                    while not guessed:
                        keys_pressed = 0
                        for pressed_index, key in enumerate(KEYS):
                            # handle key presses
                            key.update()
                            if key.fell:
                                logger.info(f"Key {pressed_index} pressed")
                                for prompt_led, prompt_color in colors:
                                    pixels[prompt_led] = prompt_color if pressed_index == prompt_led else Color.BLACK
                                pixels.show()
                                guessed = True
                                correct = pressed_index == prompted_index
                            if not key.value:
                               keys_pressed = keys_pressed + 1
 
                        if keys_pressed > 0: logger.info(f"{keys_pressed} pressed")
                        if keys_pressed == 4:
                            logger.info("4 keys pressed, back to macropad mode")
                            mode = Mode.MACROPAD
                            display_solid(Color.YELLOW)
                            wait_for_no_keys()
                            break
                    if not correct or mode != Mode.SIMON:
                        break
                if correct:
                    display_solid(Color.GREEN)
                    simon_prompt_length = simon_prompt_length + 1
                    simon_state = SimonMode.NEW_PROMPT
                    time.sleep(1)
                else:
                    display_solid(Color.RED)
                    simon_state = SimonMode.PROMPT
                    time.sleep(1)

    elif mode == Mode.MACROPAD:
        display_solid(Color.YELLOW)

        animation = CompositeAnimation()
        animation.add(BeachBall())

        while mode == Mode.MACROPAD:
            keys_pressed = 0
            for i, key in enumerate(KEYS):
                # handle key presses
                key.update()
                if key.fell:
                    animation.add(FlashAndFade(i, Color.WHITE, 10))
                    layout.write(MSGS[i], delay=0.05)
                    logger.info(f"Key {i} pressed")
                if not key.value:
                    keys_pressed = keys_pressed + 1
            if (keys_pressed > 0): logger.info(f"Number of keys pressed {keys_pressed}")
            if keys_pressed == 4:
                logger.info("4 keys pressed, going into Simon mode")
                mode = Mode.SIMON
                display_solid(Color.YELLOW)
                wait_for_no_keys()
            else:
                # update LEDS according to the current animation
                animation.loop()
                animation.display_frame()

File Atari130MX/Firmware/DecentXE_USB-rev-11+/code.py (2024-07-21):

# SPDX-License-Identifier: MIT

"""
`Decent XE USB adapter`
====================================================

This CircuitPython driver connects an Atari 130XE keyboard as an
Altirra-compatible PC keyboard

* Author: Bertrand Le Roy
"""

#Settings
power_led_brightness = 10 # Percent brightness for the keyboard's power LED.
backlight_brightness = 10 # Percent brightness for the keyboard backlight.
joystick_brightness = 10 # Percent brightness. This won't do anything on ordinary joysticks, but will set the backlight brightness for JoyKeys with backlight.
pico_led_brightness = 10 # Percent brightness for the Pi Pico's built-in LED.
map_jostick_to_dpad = False # If false, joystick directions are mapped to analog joystick, otherwise to D-pad.
paddle_a_min = 34000 # The minimum value from paddle A, that will map to -127 as an analog HID value
paddle_a_max = 65000 # The maximum value from paddle A, that will map to 127 as an analog HID value
paddle_b_min = 34000 # The minimum value from paddle B, that will map to -127 as an analog HID value
paddle_b_max = 65000 # The maximum value from paddle B, that will map to 127 as an analog HID value

# Requirements: copy Adafruit's HID library into the lib folder on the Pi Pico, as well as hid_gamepad.py into the lib/adafruit_hid.
# Adafruit HID: https://github.com/adafruit/Adafruit_CircuitPython_HID
# Gamepad HID:  https://github.com/adafruit/Adafruit_CircuitPython_HID/blob/main/examples/hid_gamepad.py

import board
import digitalio
import analogio
import pwmio
import time
import usb_hid
from adafruit_hid.keyboard import Keyboard
from adafruit_hid.keycode import Keycode
from adafruit_hid.hid_gamepad import Gamepad

SHIFTED = 0x100
CONTROLLED = 0x200

# Map of the Atari XE keyboard matrix to key codes
key_matrix = [
    [Keycode.SEVEN,           None,          Keycode.EIGHT,         Keycode.NINE,          Keycode.ZERO,            SHIFTED | Keycode.COMMA,     SHIFTED | Keycode.PERIOD, Keycode.BACKSPACE,              Keycode.PAUSE],
    [Keycode.SIX,             None,          Keycode.FIVE,          Keycode.FOUR,          Keycode.THREE,           Keycode.TWO,                 Keycode.ONE,              Keycode.ESCAPE,                 None],
    [Keycode.U,               None,          Keycode.I,             Keycode.O,             Keycode.P,               Keycode.MINUS,               Keycode.EQUALS,           Keycode.RETURN,                 None],
    [Keycode.Y,               None,          Keycode.T,             Keycode.R,             Keycode.E,               Keycode.W,                   Keycode.Q,                Keycode.TAB,                    None],
    [Keycode.F1,              Keycode.J,     Keycode.K,             Keycode.L,             Keycode.SEMICOLON,       SHIFTED | Keycode.EQUALS,    SHIFTED | Keycode.EIGHT,  Keycode.F2,                    Keycode.CONTROL],
    [None,                    Keycode.H,     Keycode.G,             Keycode.F,             Keycode.D,               Keycode.S,                   Keycode.A,                Keycode.CAPS_LOCK,              None],
    [Keycode.N,               Keycode.SPACE, Keycode.M,             Keycode.COMMA,         Keycode.PERIOD,          Keycode.FORWARD_SLASH,       Keycode.GRAVE_ACCENT,     None,                           None],
    [Keycode.F3,              Keycode.F10,   Keycode.B,             Keycode.V,             Keycode.C,               Keycode.X,                   Keycode.Z,                Keycode.F4,                    Keycode.SHIFT]]

# Shifted Atari keys have a different layout than PC shifted keys; this maps between the two so the character typed on the Atari keyboard results in the right character on the PC
shifted_overrides = dict([
    (Keycode.SEVEN, Keycode.QUOTE),
    (Keycode.EIGHT, SHIFTED | Keycode.TWO),
    (SHIFTED | Keycode.COMMA, Keycode.HOME),
    (SHIFTED | Keycode.PERIOD, SHIFTED | Keycode.INSERT),
    (Keycode.BACKSPACE, SHIFTED | Keycode.DELETE),
    (Keycode.SIX, SHIFTED | Keycode.SEVEN),
    (Keycode.TWO, SHIFTED | Keycode.QUOTE),
    (Keycode.EQUALS, SHIFTED | Keycode.BACKSLASH),
    (SHIFTED | Keycode.EQUALS, Keycode.BACKSLASH),
    (SHIFTED | Keycode.EIGHT, SHIFTED | Keycode.SIX),
    (Keycode.COMMA, Keycode.LEFT_BRACKET),
    (Keycode.PERIOD, Keycode.RIGHT_BRACKET)])

# Atari control key to PC key
controlled_overrides = dict([
    (SHIFTED | Keycode.PERIOD, Keycode.INSERT),
    (Keycode.BACKSPACE, Keycode.DELETE),
    (Keycode.ESCAPE, CONTROLLED | Keycode.BACKSLASH),
    (Keycode.MINUS, Keycode.UP_ARROW),
    (Keycode.EQUALS, Keycode.DOWN_ARROW),
    (SHIFTED | Keycode.EQUALS, Keycode.LEFT_ARROW),
    (SHIFTED | Keycode.EIGHT, Keycode.RIGHT_ARROW)])

# Joystick button enum
class JoystickButton:
    FIRE = 1
    UP = 2
    DOWN = 3
    LEFT = 4
    RIGHT = 5

GPIO_BASE = 0xd0000004

keeb = Keyboard(usb_hid.devices)
joystick = Gamepad(usb_hid.devices)

# Setup the brightness of all LEDs
def set_brightness(pin, percent):
    """Sets up the LED at the specified pin with the specified brightness percentage"""
    return pwmio.PWMOut(pin, frequency = 5000, duty_cycle = int(65535 * percent / 100))

# Helpers to setup pins
def pin_in(id, pull):
    """Helper to setup an input pin from its number"""
    pin = digitalio.DigitalInOut(getattr(board, 'GP' + str(id)))
    pin.direction = digitalio.Direction.INPUT
    pin.pull = pull
    return pin

def pin_out(id):
    """Helper to setup an output pin from its number"""
    pin = digitalio.DigitalInOut(getattr(board, 'GP' + str(id)))
    pin.direction = digitalio.Direction.OUTPUT
    return pin

def reset_joy_mode():
    """Resets the joystick ports"""
    global joy_gnd, joy_vcc, paddle_a, paddle_b
    if "joy_gnd" in globals():
        joy_gnd.deinit()
    joy_gnd = pin_in(26, digitalio.Pull.DOWN)
    if "joy_vcc" in globals():
        joy_vcc.deinit()
    joy_vcc = set_brightness(board.GP8, joystick_brightness)

# Setup LED brightness through PWM and pull ground pins down
power_led = set_brightness(board.GP2, power_led_brightness)
backlight_gnd = set_brightness(board.GP3, 100 - backlight_brightness)
backlight = pin_out(9)
backlight.value = True
pico_led = set_brightness(board.LED, pico_led_brightness)
reset_joy_mode()

# Paddles
paddle_a = analogio.AnalogIn(board.A1)
paddle_b = analogio.AnalogIn(board.A2)

# Setup decoder pins
strobe = pin_out(4)
a0 = pin_out(16)
a1 = pin_out(17)
a2 = pin_out(19)
a3 = pin_out(20)

# pin numbers for keyboard rows in order
row_pin_numbers = [13, 14, 12, 15, 7, 18, 5, 6]
row_pins = list(map(lambda pin: pin_in(pin, digitalio.Pull.DOWN), row_pin_numbers))

# Last row is special as pin 3 is connected to ground: cols are: [21, 22, 0, 1] # Pi pin 0-> keeb pin 23, Pi pin 1 -> keeb pin 24
start_pin = pin_in(21, digitalio.Pull.UP)
select_pin = pin_in(22, digitalio.Pull.UP)
option_pin = pin_in(0, digitalio.Pull.UP)
reset_pin = pin_in(1, digitalio.Pull.UP)
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

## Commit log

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2021-03-07 Add bottom part of keeb box, space for the pi, screws and nuts
    [demo-keeb.scad]
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2021-04-18 Revision 6 of the Atari key stem
    This one actually works, but there's a risk to shatter the stem when inserting the cap. Next rev will have wider socket.
    Adds an option to carve the revision number on the side of the stem.
    [keeb-stem.scad]
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2021-04-21 Atari stem Rev 8
    Move column to the center
    Middle section of the stem is narrower
    Move one of the rails
    Add a recess at the bottom of the cap hole to allow for extra resin to stay out of the way
    [keeb-stem.scad]
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2021-05-02 Add OSH logo, fix one track, OSH Park settings
    [Atari130MX.kicad_pcb]
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2021-05-03 Some more keeb PCB fixes
    [Atari130MX.kicad_pcb]
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2021-08-01 Convert to CircuitPython, finish work and fix bugs
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2021-09-03 ... and we have flat-faced mountains with few bugs.
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2021-09-15 Add a Pi PICO to the schematic for the 130MX keyboard PCB
    [Atari130MX.sch]
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2021-09-25 Small fix to one of the plate footprints
    [Atari130MXPlate.kicad_pcb]
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2021-10-11 Add stabilizer holes for the correct orientation of the space bar in the circular variant
    [Atari130MXPlate.kicad_pcb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]
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2021-10-14 Fix F4 position on matrix footprints
    [Atari130MX.kicad_pcb]
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2021-10-21 More routing, replace solder headers with pin headers.
    [AtariKeyboardTester.kicad_pcb, AtariKeyboardTester.sch]
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2021-11-02 Add XL variants
    Alps, cross and square stems and adapters
    Tidy up the directory structure
    [keeb-stem-alps.stl, keeb-stem-circle.stl, keeb-stem-square.stl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]
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2021-11-08 More Rev. D tweaks
    Plate: larger holes to accommodate for space stabilizer rod.
    Plat: move lower-left function key stabilizer a little to the top-right.
    [Atari130MXPlate.kicad_pcb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]
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2021-11-23 Add teeth to Choc adapters to make them a tighter fit.
    [kailh-choc-to-xl-cross.stl, kailh-choc-to-xl-square.stl, keeb-stem.scad]
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2021-11-29 A variation of the XE mechanical keyboard that takes Kailh Choc low-profile switches and has backlighting
    [AtariChocXE.kicad_pcb, AtariChocXE.sch]
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2021-12-19 Bug fixes in rendering, thrust limits
2022-02-07 Fix Kailh Choc footprint and reroute ChoxXE keyboard accordingly
    Bigger LED power traces too
    [AtariChocXE-B_Cu.gbl, AtariChocXE-B_Cu.gbr, AtariChocXE-B_Mask.gbr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]
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2022-09-12 Add a version of the 130MX PCB that takes a modern layout compatible with modern key caps and with the 130XE general footprint
    [Atari130MX_wasdkb.kicad_pcb]
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2022-09-13 Fix XEs layout, add fabrication files and previews
    [Atari130MX_wasdkb-B_Cu.gbl, Atari130MX_wasdkb-B_Mask.gbs, Atari130MX_wasdkb-B_Paste.gbp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]
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2022-12-19 Mini monitor and PC case models
    Can fit RPis and e-ink screen.
    [MiniMonitor.f3d, MiniMonitor.stl, pc-case-mini.scad]
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2022-12-30 Decent MX progress
    Updated footprints
    Rebuilt schematic with diodes
    Started rebuilding PCB
    [AtariChocXE.kicad_sch]
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2023-01-24 Initial design for a flexible PCB custom cable
    But those turn out to be way more expensive than expected, at least at PCBWay (JLC doesn't offer them)
    [Atari130MX-adapter-FFC.kicad_sch, Atari130MX-adapter-IDC.kicad_sch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]
2023-01-25 Cleaning up old version of the board from the branch
    Renaming current to DecentXE
    [Atari130MX.dsn, Atari130MX.kicad_pcb, Atari130MX.sch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]
2023-01-29 First attempt at Pi Pico USB adapter
    Not good, lazy design, will redo
    [Atari130MX-B_Cu.gbl, Atari130MX-B_Mask.gbs, Atari130MX-B_Paste.gbp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]
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2023-01-30 Bettter design for the USB adapter
    There will eventually be a 2040-based design that will do away with the Pico entirely. This is only a prototype.
    [DecentXE-to-USB-B_Cu.gbr, DecentXE-to-USB-B_Mask.gbr, DecentXE-to-USB-B_Paste.gbr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]
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2023-02-03 Fixes to fabrication files
    [DecentXE-top-pos.csv]
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2023-02-08 First complete draft of a MX-compatible function key
    First STL rendering of the Help key as an example
    [help-MX.stl, keeb-stem.scad]
2023-02-09 Update fn key model after first proto print
    Generate STL for all Atari fn keys plus no legend and F1-12
    [fn-F1.stl, fn-F10.stl, fn-F11.stl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]
2023-02-11 First Duroc v2 adapter
    This one is for the square style space bar and it works brilliantly
    [durock-v2-adapter.scad, durock-v2-spacebar-circle-adapter.stl]
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2023-03-02 Last JoyKey fixes, JoyKey sticker designs
    [JoyKeyCase-Top-first-batch.stl, JoyKeyCase-Top.stl, JoyKeyCase.FCStd]
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2023-03-09 Add linked sets of cap adapters
    Add an option to rotate the stem 90 degrees
    [kailh-choc-to-xe-circle-90.stl, kailh-choc-to-xe-circle-set.stl, kailh-choc-to-xe-circle.stl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]
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2023-03-15 Fix the USB adapter
    Decoder power supply was reversed. oops
    [DecentXE-to-USB.kicad_pcb]
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2023-04-06 DecentXE Rev 12
    Minor tweaks
    Power LED is surface mounted
    Moving the connector to the front
    Add F1-4 connector
    [DecentXE-BOM.csv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]
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2023-04-18 Fix JoyKey XL backlight connection
    [JoyKeyMX-B_Cu.gbr, JoyKeyMX-B_Mask.gbr, JoyKeyMX-B_Paste.gbr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]
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2023-05-14 minor changes missed in the merge
    [DecentXE-positions.csv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]
2023-05-14 Fix schematic background
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2023-05-30 Firmware bug fix
    Add library files for convenience
    [boot.py, code.py]
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2023-06-24 Sidecar case rework WIP
    [SidecarXE85-case-Bottom.stl]
2023-06-24 Sidecar rev 2 finalization
    Some small DecentXE PCB fixes
    [SidecarXE85-case-Top.stl, low-pro-to-xe-square-set.stl]
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2023-06-25 Small case fixes
    [SidecarXE85-case-Bottom.stl, SidecarXE85-case-Full.stl]
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2023-07-06 DecentXL footprint library with Alps compatible footprint
    Other usable footprints: MX, Kailh Choc v2
    [DecentXL-keyboard.kicad_sch]
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2023-09-13 Fix XL footprints
    TODO: update footprints in console board.
    [DecentXL-keyboard.kicad_sch]
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2023-09-23 Fix BOM and pos files for Decent1200
    [Decent1200-bom.csv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]
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2023-10-17 Decent1200: replace console keys with footprint that allows the board to move left by U/8 to compensate for left row being U/4 smaller in the modern case
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2023-10-19 More misc models
    Festool rail with threads
    Table version of the probe holder
    [FesseTouleRails.FCStd]
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2023-11-11 Decent800 fixes
    [Decent800-plate.kicad_pcb]
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2023-12-04 Small XL bracket adjustment for 600XL pillar clearance
    [DecentXL-Left-Bracket.FCStd, DecentXL-Left-Bracket.stl]
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2024-01-06 Fixing a mistake in XL rev.4m production files
    [DecentXL-keyboard-modern.kicad_sch, DecentXL_keyboard-Modern_4-bom.csv, DecentXL_keyboard-Modern_4-positions.csv]
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2024-01-14 Fix inv key on Decent1200
    3D printed parts for 1200
    [ConsoleKeyAdapter.FCStd, ConsoleKeyAdapter1200-x12.stl, ConsoleKeyAdapter1200.stl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]
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2024-01-14 Decent1200 inv key fixes in schematic and PCB
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2024-02-19 A small adapter to stack separate keyboard and mouse PS/2 connectors on a 1088XEL since the double connectors are unobtainium.
    [PS2-adapter.kicad_pcb, PS2-adapter.kicad_sch]
2024-02-19 DecentXL Modern cut trace fix
    [DecentXL_keyboard_-_Modern_4.1m-bom.csv, DecentXL_keyboard_-_Modern_4.1m-positions.csv, DecentXL_keyboard_4.1m-bom.csv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]
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2024-03-29 Decent400 enclosure fix to leave more room to the USB cable
    Updated USB firmware
    [code.py]
2024-04-06 Add an XE console key stabilizer with room for 9 keys
    F1-4 + help, start, select, option, reset
    [LowProPlateWithF1-4.FCStd, LowProPlateWithF1-4.stl]
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2024-04-07 DecentXL bracket fixes & console key plate
    The console key plate is now strictly necessary but a nice to have
    [DecentXL-Right-Bracket.FCStd, DecentXL-Right-Bracket.stl, LowProPlateXL.FCStd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]
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2024-07-21 DecentXL 4.1v
    Fix a mistake
    Alps adapters for stabilizers
    [DurockAlpsInsert-left.stl, DurockAlpsInsert-right.stl, DurockAlpsInserts-x10.stl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]
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2024-07-21 Minor fixes to 800
    [Decent800.kicad_sch]
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2024-07-21 DecentXE files moved from the Atari130MX directory to DecentXE
    DecentXE updated to rev. 15
    [ConsoleXE-F1-4.FCStd, ConsoleXE.FCStd, DecentXE-Enclosure.FCStd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]
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2024-07-29 600XL keyboard interface board replacement
    [600XL-keyboard-RN.kicad_pcb, 600XL-keyboard-RN.kicad_sch, bom.csv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]
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2024-08-12 Revision of the 600XL keybaord interface replacement board
    [600XL-keyboard-RN.kicad_pcb, 600XL-keyboard-RN.kicad_sch, bom.csv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]
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2024-08-12 Chip breakout boards use larger holes to allow for precision sockets to go through
    [ChipShift.kicad_pcb, DIP40-breakout.kicad_pcb, bom.csv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]
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2024-08-18 Misc models
    Reorg of the folder structure
    New and improved hex lattice models
    New action figure shelves
    [ActionFigureBracket.FCStd, AloyPopFig.stl, BottomLattice.stl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]
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2024-08-25 Plug for XL case when Sophia's DVI port leaves a small part of the old port exposed.
    [OverSophiaDviPlug.3mf, OverSophiaDviPlug.FCStd, OverSophiaDviPlug.stl]
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2024-08-26 Fix on the DecenTKL numpad enclosure proto
    [DecenTKL-Numpad-Enclosure-Bottom.stl]
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2024-09-04 Guitar pedal rack
    Misc models cleanup
    Fixes to hex lattice 3D model
    [BOM.ods, DIP40-breakout.kicad_pcb, DIP40-breakout.kicad_sch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]
2024-09-04 Fixed production orientation of one of the RGB LEDs
    [key_2U.kicad_sch, positions.csv]
2024-09-07 Fix D36 orientation in DecnTKL NumPad
    [DecentNumPad.kicad_pcb]
2024-09-07 Better padding of DeceTKL keyboard PCB in bottom of case
    Padding parts for previous version of the case.
    [DecenTKL-Enclosure.FCStd, DecenTKL-bottom.stl, Padding-Corner-Left.stl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]
2024-09-12 DecentUSB Host rev. 2 schematic done
    RS2350 instead of Pi Pico
    ESP32 for WiFi
    4-ports USB hub
    Full support for 2 joysticks
    Level shifting on all lines
    2 RGB LEDs + 1 single color LED
    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
    [DecentUSB.kicad_sch]
2024-09-13 DecentUSB Host adjustments
    Internal RGB LED is now a neopixel
    Added port for additional neopixels chained behind the on-board one
    Added an expansion port for the leftover GPIOs and the OLED display
    Added power source selection MOSFET
    [DecentUSB.kicad_sch]
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2024-10-15 Replacement cartridge port model
    [CartridgePort.FCStd, CartridgePort.stl]
2024-10-15 DecentCart 2040 rev. 1.1 fixes
    [DecentCart2040.kicad_pcb, DecentCart2040.kicad_sch, bom.csv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]
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2024-11-30 DecenTKL firmware update
    Missing stickers
    Font
    Encoder knob design
    [EncoderKnob.FCStd]
2024-11-30 DecentXL stackpole vintage adapters fix
    [StackpoleXLLeftShiftStabilizerAdapter.3mf, StackpoleXLLeftShiftStabilizerAdapter.FCStd, StackpoleXLLeftShiftStabilizerAdapter.stl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]
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2025-01-24 Remove mention of a console key plate that's no longer necessary.
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2025-03-07 Fix bug where you can't cycle modes all the way
    [code.py]
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2025-04-16 Retro Keyboard Tester support for 1200XL
    Fixes to the Decent1200 keyboard schematic
    [Decent1200-Modern.kicad_sch]
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2025-04-16 Fix 800 BOM
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2025-05-29 Decent800 Rev. 3M
    A modern only version of the 800 keyboard replacement
    [Decent800-M.kicad_sch, Decent800-plate.kicad_pcb, Decent800M-Plate.kicad_pcb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]
2025-07-22 Fix BOM and position links from seller docs
2025-07-30 Fix R switch position on the 1200 keyboard
    [Decent1200-Modern.kicad_sch, Decent1200_modern_keyboard_5m-bom.csv, Decent1200_modern_keyboard_5m-positions.csv]
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2025-10-12 DecentXE Rev. 15.2m
    Moved anti-ghosting diode for the space bar to the up and right, avoiding colliding with the stabilizer wire.
    [Decent_XE_Keyboard_-_Modern_15.1-bom.csv, Decent_XE_Keyboard_-_Modern_15.1-positions.csv, Decent_XE_Keyboard_-_Modern_15.2-positions.csv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]
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2026-01-14 Fix a small alignment error on console keys
    [Decent400-internal.kicad_sch, bom.csv, positions.csv]
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2026-02-10 Flex cable rev 2 tweaks
    [DecentXL-cable.kicad_pcb]
2026-02-10 Add fabrication comment to flex cable
    [DecentXL-cable.kicad_pcb]
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2026-03-17 Decent400 rev 4.2i
    Moved the luminosity pot left of the right shift key so it's still accessible but not normally visible
    Changed the connector to an IDC connector between the main part of the keyboard and the console keys
    Fixed alignment issues on console keys
    Created all-new cap legends, fake test caps and printed rigs for UV home printing
    [Decent400-internal.kicad_sch, Decent400-plate.kicad_pcb, Decent400CapPrintRig-Small mini plate rig 1U.3mf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]
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2026-08-10 Decent60
    60% USB keyboard with hot-swap sockets and RGB backlighting
    [MegaXE-keyboard.kicad_pcb, MegaXE-keyboard.kicad_sch, bom.csv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]
2026-08-10 Decent60 NavNumPad
    Takes your 60% keyboard to full-size, with a 3 port USB hub, hot-swap sockets and RGB lighting.
    [2040.kicad_sch, DecentNumPad.kicad_pcb, DecentNumPad.kicad_sch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]
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2026-09-07 A simple fix for IKEA drawer bottoms falling out under load
    [IkeaDrawerFixBracket.3mf, IkeaDrawerFixBracket.FCStd]
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2026-10-17 Decent800 brackets - small correction to exported files
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2026-10-26 Fixed 800 bracket 3mf files
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

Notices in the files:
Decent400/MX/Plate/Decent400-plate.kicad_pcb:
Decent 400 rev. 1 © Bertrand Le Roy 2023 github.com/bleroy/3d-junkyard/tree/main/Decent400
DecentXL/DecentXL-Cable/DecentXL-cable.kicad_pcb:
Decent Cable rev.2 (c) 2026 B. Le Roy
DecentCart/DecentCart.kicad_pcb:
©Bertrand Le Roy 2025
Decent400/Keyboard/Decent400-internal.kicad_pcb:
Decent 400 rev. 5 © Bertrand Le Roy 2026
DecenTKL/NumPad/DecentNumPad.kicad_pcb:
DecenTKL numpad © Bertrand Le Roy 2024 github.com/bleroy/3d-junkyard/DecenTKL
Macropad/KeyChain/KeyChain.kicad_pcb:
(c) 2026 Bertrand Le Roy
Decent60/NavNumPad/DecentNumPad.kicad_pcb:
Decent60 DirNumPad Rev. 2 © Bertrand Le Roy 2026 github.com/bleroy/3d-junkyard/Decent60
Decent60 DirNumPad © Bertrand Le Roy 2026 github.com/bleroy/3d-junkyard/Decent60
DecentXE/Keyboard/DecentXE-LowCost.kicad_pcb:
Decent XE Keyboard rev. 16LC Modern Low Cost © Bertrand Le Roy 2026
